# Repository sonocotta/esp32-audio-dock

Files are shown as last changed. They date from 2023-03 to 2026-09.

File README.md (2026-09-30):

# ESP32 Audio Docks and Louder ESP

<a class="logo" href="https://www.elecrow.com/store/Sonocotta" title="I sell at Elecrow">elecrow logo</a>



ESP32 Audio Docks is a range of development boards (earlier docks) that allow you to develop Audio solutions based on ESP32 chips. These were created to make Audio development entry as easy and inexpensive as possible. 

<details>
  <summary>First generation docks</summary>
  


</details>

| **HiFi-ESP32** | **HiFi-ESP32-Plus** |
|---|---|
|  |  |
| **Loud-ESP32** | **Loud-ESP32-Plus**
|   | 
| **Louder-ESP32** | **Louder-ESP32-Plus** |
|  | 
| **Louder-ESP32-mini** | **Louder-ESP32-Pro** |
|  |  |
| **Amped-ESP32** | **Amped-ESP32-Plus** | 
|  | 

⚠️ _Looking for Esparagus boards? Check out sister repository: [Esapragus Media Center](https://github.com/sonocotta/esparagus-media-center/)_

## Table of Contents

- [ESP32 Audio Docks and Louder ESP](#esp32-audio-docks-and-louder-esp)
  - [Table of Contents](#table-of-contents)
  - [Motivation](#motivation)
  - [HiFi-ESP32 and Hifi-ESP32-Plus](#hifi-esp32-and-hifi-esp32-plus)
  - [Loud-ESP32 and Loud-ESP32-Plus](#loud-esp32-and-loud-esp32-plus)
  - [Louder-ESP32 and Louder-ESP32 Plus](#louder-esp32-and-louder-esp32-plus)
  - [Louder-ESP32 Mini](#louder-esp32-mini)
  - [Louder-ESP32 Pro](#louder-esp32-pro)
    - [Recommended power adapter](#recommended-power-adapter)
  - [Amped-ESP32 and Amped-ESP32-Plus](#amped-esp32-and-amped-esp32-plus)
    - [TPA3110 vs TAP3118 designs](#tpa3110-vs-tap3118-designs)
  - [Features](#features)
    - [Onboard PSRAM](#onboard-psram)
  - [Which chip: ESP32 or ESP32-S3?](#which-chip-esp32-or-esp32-s3)
  - [Boards Pinout](#boards-pinout)
    - [Legacy boards](#legacy-boards)
    - [HiFi-ESP32 and Amped-ESP32](#hifi-esp32-and-amped-esp32)
    - [Amped-ESP32-Plus](#amped-esp32-plus)
    - [HiFi-ESP32 Plus and Amped-ESP32 Plus](#hifi-esp32-plus-and-amped-esp32-plus)
    - [Loud-ESP32](#loud-esp32)
    - [Loud-ESP32-Plus](#loud-esp32-plus)
    - [Louder-ESP32 and Louder-ESP32-Plus](#louder-esp32-and-louder-esp32-plus-1)
    - [Ethernet (all boards)](#ethernet-all-boards)
    - [Optional peripheral (all boards)](#optional-peripheral-all-boards)
    - [Fan (optional on Louder-ESP32-Pro boards)](#fan-optional-on-louder-esp32-pro-boards)
    - [Mic header](#mic-header)
    - [TFT and Fan header (Louder-ESP32 Pro boards)](#tft-and-fan-header-louder-esp32-pro-boards)
  - [Which software is right for me](#which-software-is-right-for-me)
  - [Software samples](#software-samples)
    - [Platformio IDE](#platformio-ide)
    - [Arduino IDE](#arduino-ide)
  - [Using ESP32 Audio Boards with the Home Assistant](#using-esp32-audio-boards-with-the-home-assistant)
    - [Configuring Home Assistant](#configuring-home-assistant)
    - [Home Assistant: LMS or Airplay](#home-assistant-lms-or-airplay)
      - [Native HA integration](#native-ha-integration)
      - [Integrate into Music Assistant directly](#integrate-into-music-assistant-directly)
    - [Home Assistant: ESPHome way](#home-assistant-esphome-way)
      - [Install steps](#install-steps)
    - [PCM5122 DSP capabilities (HiFi-ESP32 Plus \& Amped-ESP32 Plus)](#pcm5122-dsp-capabilities-hifi-esp32-plus--amped-esp32-plus)
    - [Home Assistant: Snapcast](#home-assistant-snapcast)
  - [Squeezelite-ESP32](#squeezelite-esp32)
    - [How to flash and configure](#how-to-flash-and-configure)
    - [Ethernet configuration](#ethernet-configuration)
    - [Squeezelite-esp32 reboots and connection drops](#squeezelite-esp32-reboots-and-connection-drops)
  - [AirPlay 1 & 2](#airplay-1--2)
    - [TAS58xx DSP: full parametric EQ and crossover control](#tas58xx-dsp-full-parametric-eq-and-crossover-control)
    - [How to Get Started](#how-to-get-started)
  - [Other smart home options](#other-smart-home-options)
    - [Building Tasmota with I2S support](#building-tasmota-with-i2s-support)
    - [Connect to the MQTT broker](#connect-to-the-mqtt-broker)
    - [Connect Louder-ESP32 to the MQTT broker](#connect-louder-esp32-to-the-mqtt-broker)
    - [Testing audio playback with MQTT controls](#testing-audio-playback-with-mqtt-controls)
  - [Standalone Snapclient](#standalone-snapclient)
    - [Snapclient benefits](#snapclient-benefits)
  - [Flashing ESP32-S3](#flashing-esp32-s3)
  - [Hardware](#hardware)
    - [ESP Audio Solo](#esp-audio-solo)
    - [ESP Audio Duo](#esp-audio-duo)
    - [HiFi-ESP](#hifi-esp)
    - [Louder ESP](#louder-esp)
    - [HiFi-ESP32](#hifi-esp32)
    - [Loud-ESP32](#loud-esp32-1)
    - [Amped-ESP32](#amped-esp32)
    - [Amped-ESP32 with TPA3118/TPA3128 amp](#amped-esp32-with-tpa3118tpa3128-amp)
    - [Louder-ESP32](#louder-esp32)
    - [Optional SPI Ethernet module](#optional-spi-ethernet-module)
    - [BTL and PBTL mode (Louder and Amped boards)](#btl-and-pbtl-mode-louder-and-amped-boards)
      - [Power figures (comparison of BTL and PBTL modes)](#power-figures-comparison-of-btl-and-pbtl-modes)
      - [Louder-ESP32 and Louder-ESP32-Plus (recent revisions)](#louder-esp32-and-louder-esp32-plus-recent-revisions)
      - [Amped TPA3110 Amp](#amped-tpa3110-amp)
      - [Amped TPA3128 Amp](#amped-tpa3128-amp)
      - [Louder TAS5805M DAC](#louder-tas5805m-dac)
    - [TAS5805M DSP capabilities](#tas5805m-dsp-capabilities)
    - [Louder-ESP32 and Amped-ESP32 power considerations](#louder-esp32-and-amped-esp32-power-considerations)
      - [Connector specs](#connector-specs)
      - [Recommended models](#recommended-models)
      - [Efficiency](#efficiency)
    - [Speakers selection](#speakers-selection)
    - [OLED screen](#oled-screen)
      - [OLED models](#oled-models)
      - [Software side](#software-side)
    - [TFT screen](#tft-screen)
    - [Case](#case)
    - [Parametric OpenSCAD desktop case](#parametric-openscad-desktop-case)
    - [Louder-ESP32 Pro case](#louder-esp32-pro-case)
    - [Louder-ESP32 Mini shell](#louder-esp32-mini-shell)
    - [Louder-ESP32 Mini Speakers Compatibility](#louder-esp32-mini-speakers-compatibility)
    - [Louder-ESP32 Mini USB-PD note](#louder-esp32-mini-usb-pd-note)
  - [Community projects](#community-projects)
  - [Where to buy](#where-to-buy)
  - [Errata](#errata)

## Motivation

I spent the last few years developing different solutions based on ESP devices. It all started with ESP8266, where CPU power is not really sufficient to do real-time decoding, so you're limited to a rather simple ding-dong business. Then ESP32 came, bringing two much more capable cores, so you have a powerhouse to handle communication and decoding at the same time. Perhaps most importantly, it also came with SPIRAM, so you can do decent buffering (essential for streamed content). Now, new ESP32 C-Series and S-Series chips are entering the market, and their potential is mostly unrealized as of today.

I created those docks and subsequently development boards to be able to quickly prototype for the whole range of ESP8266 and ESP32 chips, starting with the simplest finger-sized toys and going all the way up to full-sized speakers.

## HiFi-ESP32 and Hifi-ESP32-Plus

The **HiFi-ESP32** is a first-in-line product that uses the legendary PCM5100 series DAC with supreme audio quality. It exposes line-level output that you can plug into a stereo amplifier. Analog power comes through an Ultra-low-noise LDO, making sure no interference from the MCU comes through to your speakers. Spend as much as you need on the external amp to deliver the sound you like (personally, I prefer late 80's audio gear).

| **HiFi-ESP32** | **HiFi-ESP32-Plus** |
|---|---|
|  | 

The **HiFi-ESP32 Plus** represents the next evolution of the board, featuring the advanced PCM5122 DAC with built-in DSP capabilities. This board maintains the same audio quality as the original HiFi-ESP32 while adding powerful digital signal processing features, including parametric EQ (6 BQs per channel), DRC, and crossover functionality (with output to downstream DAC). The PCM5122's flexible DSP engine can be configured for various audio enhancement scenarios, making it ideal for projects requiring sound tuning (why would you not)

**Key Features:**

- [PCM5122](https://www.ti.com/lit/ds/symlink/pcm5122.pdf) DAC with integrated DSP
- Parametric EQ and crossover capabilities (for cascading DACs)
- Digital volume control (avoids loss of resolution compared to software volume)
- Advanced audio processing features (DRC)
- Same form factor and connectivity as HiFi-ESP32

## Loud-ESP32 and Loud-ESP32-Plus

The **Loud-ESP32** uses a dual MAX98357 HiFi DAC with a built-in highly efficient D-class amp to deliver 3 to 5W of music power directly to your speakers. It is not too loud, but also very simple to use and fun to play with. When DAC is not in use, it goes into shutdown mode, making sure no hissing will keep you up at night. It powers from a standard USB-C power source, like a phone charger, etc.

| **Loud-ESP32** | **Loud-ESP32-Plus** |
|---|---|
|  | 

The **Loud-ESP32-Plus** model hires a much more powerful [Infineon MA12070P](https://www.infineon.com/part/MA12070P) DAC with up to 60W per channel. Due to the D-class amp, they are highly efficient yet high-quality audio streamers. It lacks DSP features, but has the most raw horsepower across the line. It is in beta testing, and I'm still trying to fix minor issues with the DAC driver.

## Louder-ESP32 and Louder-ESP32 Plus

The **Louder-ESP32** is a top-of-the-range model that uses a modern, highly capable TAS5805M DAC and is aimed at being paired with medium-to-large speaker systems. With 25W per channel stereo output, it packs a punch and can easily enliven living quarters or dorm rooms. It is highly efficient, but much more demanding for power when cranked; therefore, it also uses an external power adapter using a standard  jack. This DAC has a built-in DSP, so you can have a lot of fun with complex EQ, soft-clipping, DRC compression, and AGL tools, among other things.

| **Louder-ESP32** | **Louder-ESP32-Plus** |
|---|---|
|  | 

The **Louder-ESP32-Plus** upgrades the DAC to the TAS5825M model, which is more efficient (and therefore more powerful) and more capable. It introduces advanced DSP features that are not available on the base model, as it has a much more powerful DSP processor.

- TAS5825M DAC with integrated DSP
- Digital volume control (avoids loss of resolution compared to software volume)
- Gain digital control
- Parametric EQ (15xBQ), 128-tap FIR, 3-band DRC, AGL
- Advanced DSP: Smart Excursion, Smart Thermal, Smart Bass, SmartEQ

## Louder-ESP32 Mini

**Louder-ESP32-mini** is a compact and stripped-down version of the Louder-ESP32, which would replace the standard speaker terminal on your old speakers, turning them into a Hi-Fi audio solution for your smart home.

It comes in two sizes that are most common among off-the-shelf speakers: 42x42mm (small speakers typically) and 52x52mm (for larger models).

Louder-ESP32-mini is equipped with a high-quality TAS5805M DAC with powerful DSP features, allowing audio tuning to turn small speakers into high-quality audio streamers. Onboard ESP32-S3 with 8MB PSRAM is there to ensure enough horsepower for solid streaming capabilities.

It is designed to be as affordable as it can be, so more speakers can avoid landfills and be an integral part of smart homes instead. It uses minimal (if any) extra peripherals, and it requires no soldering to operate. The part choice was carefully done to make it production-friendly and affordable for everyone

| Front | Back |
|---|---|
|  | 

## Louder-ESP32 Pro

On the other side of the scale, Louder-ESP32-Pro is a feature-packed version of the Louder-ESP32-Plus, which hosts most of the optional extras as standard, adds support for color TFT screens, and, perhaps most importantly, adds an industrial-grade heat release solution for reliable heavy-duty operation.

It comes in Raspberry Pi 5 shape with the most important component placed to follow the original heat release pattern. This allows the use of Raspberry Pi aluminum radiators, including those with soft-controlled fan connectors, that can be driven through Louder-ESP32-Pro software when operating in hot conditions.

Louder-ESP32-Pro is equipped with a high-quality TAS5825M DAC with powerful DSP features, allowing audio tuning to turn your speakers into high-quality audio streamers, big or small likewise. Onboard ESP32-S3 with 8MB PSRAM is there to ensure enough horsepower for solid streaming capabilities.



### Recommended power adapter

Louder-ESP32-Pro is designed to be powered from a USB-C power source, so powering it is as easy as plugging in a standard laptop power charger. It can accept a wide range of voltages, but for maximum performance, a 20V 3.25A 65W power adapter is recommended. This will ensure that the board can deliver its full audio output capabilities without power limitations.

|  Model | Image |
|---|---|
| [20V 3.25A 65W AC Laptop Power adapter Charger](https://pl.aliexpress.com/item/1005007070762655.html) | 

It will also work from Quick-charge power adapters (9V, 12V) that support USB-PD protocol, and even bare USB-C power sources, but the maximum output will be limited to the power adapter's capabilities.

## Amped-ESP32 and Amped-ESP32-Plus

The PCM5100 HiFi DAC is combined with a highly efficient TPA31-series D-class amplifier. It brings all the best from the HiFi model and adds an onboard amp to form a complete solution that can be paired with speakers. Compared to the Louder models, it has similar power capabilities, but it is much simpler to use since it only needs a valid I2S signal to operate, so a simple book example code will do it. It adds line-out, so you have a chance to switch betwwen built-in amp and external, if you need to. 

| **Amped-ESP32** | **Amped-ESP32-Plus** |
|---|---|
|  | 

Building upon the success of the Amped-ESP32, the **Amped-ESP32 Plus** combines the powerful PCM5122 DAC with the same TPA31-series amplifier. This board offers the same DSP capabilities as the HiFi-ESP32-Plus while providing built-in amplification for direct speaker connection. The PCM5122's DSP features will enable advanced audio processing, including speaker correction, room EQ, and other enhancements.

**Features:**

- [PCM5122](https://www.ti.com/lit/ds/symlink/pcm5122.pdf) DAC with integrated DSP + TPA3110/TPA3118 D-class amplifier
- Digital EQ and dynamic range processing
- Same power output as Amped-ESP32 with enhanced audio quality

### TPA3110 vs TAP3118 designs

Recently, all Amped boards were migrated to use the new [TPA3118](https://www.ti.com/product/TPA3118D2) amp. Benefits that the new TPA3118 amp brings:

- It is more efficient (about half the heat with the same output power, compared to TPA3110), so the board can sustain higher power for longer
- It has a true MUTE pin that can be connected to the GPIO and shut down the output driver when no audio is playing
- It can be powered from a 5V source, so if you're not looking for maximum power, you can use a USB-C power adapter alone
- Being a newer design, it has better audio quality. I can't hear it, but people say it sounds better

## Features

<details>
  <summary>First generation docks</summary>

| ESP Audio Solo | ESP Audio Duo | Hifi ESP | Louder ESP |
|---|---|---|---|
|  |  |  |  |
| ESP8266, ESP32C3, ESP32S2 Mini modules | ESP32 Mini Module | ESP32 Mini Module | ESP32 Mini Module |
| Single I2S DAC ([MAX98357](https://www.analog.com/en/products/max98357a.html)) with built in D-Class amp | Dual I2S DAC ([MAX98357](https://www.analog.com/en/products/max98357a.html)) with built in D-Class amp | [PCM5100A](https://www.ti.com/product/PCM5100A) 32bit Stereo DAC  -100 dB typical noise level | Stereo I2S DAC ([TAS5805M](https://www.ti.com/product/TAS5805M)) with built in D-Class amp |
| 3W | 2x 3W | Non-amplified stereo output | 2x 32W (4Ω, 1% THD+N) |
| 1.5W | 2x 1.5W | Non-amplified stereo output | 2x 22W (8Ω, 1% THD+N) |
|  | 8MB PSRAM (4MB usable) | 8MB PSRAM (4MB usable) | 8MB PSRAM (4MB usable) |
| WiFi (ESP8266, ESP32S2)  WiFi + BT5.0 (ESP32C3) | WiFi + BT4.2 + BLE | WiFi + BT4.2 + BLE | WiFi + BT4.2 + BLE  Ethernet |

</details>

|  | HiFi-ESP32 | HiFi-ESP32 Plus | Loud-ESP32 | Loud-ESP32-Plus | Louder-ESP32 | Louder-ESP32 Mini | Louder-ESP32 Plus | Louder-ESP32 Pro | Amped-ESP32 | Amped-ESP32 Plus |
|---|---|---|---|---|---|---|---|---|---|---|
| Image (ESP32) |  |  |  |  |  | n/a |  | n/a |  |  |
| MCU | ESP32-WROVER-N8R8 | ESP32-WROVER-N8R8 | ESP32-WROVER-N8R8 | ESP32-WROVER-N8R8 | ESP32-WROVER-N8R8 | n/a | ESP32-WROVER-N8R8 | n/a | ESP32-WROVER-N8R8 | ESP32-WROVER-N8R8 |
| Image (ESP32-S3) |  |  |  |  |  |  |  |  |   |  |
| MCU (S3) | ESP32-S3-WROOM-N8R8 | ESP32-S3-WROOM-N8R8 | ESP32-S3-WROOM-N8R8 | ESP32-S3-WROOM-N8R8 | ESP32-S3-WROOM-N8R8 | ESP32-S3-WROOM-N8R8 | ESP32-S3-WROOM-N8R8 | ESP32-S3-WROOM-N8R8 | ESP32-S3-WROOM-N8R8 | ESP32-S3-WROOM-N8R8 |
| DAC | [PCM5100A](https://www.ti.com/product/PCM5100A) 32bit Stereo DAC (-100 dB typical noise level) | [PCM5122](https://www.ti.com/product/PCM5122) 32bit Stereo DAC with integrated DSP (-112 dB typical noise level) | Dual I2S DAC ([MAX98357](https://www.analog.com/en/products/max98357a.html)) with built in D-Class amp | [Infineon MA12070P](https://www.infineon.com/part/MA12070P)<br> with built-in D-Class amp | Stereo I2S DAC ([TAS5805M](https://www.ti.com/product/TAS5805M)) with built in D-Class amplifier and powerful DSP | Stereo I2S DAC (<br>[TAS5805M](https://www.ti.com/product/TAS5805M)<br>) with built in D-Class amplifier and powerful DSP | Stereo I2S DAC (<br>[TAS5825M](https://www.ti.com/product/TAS5825M)<br>) with built in D-Class amplifier and powerful DSP | Stereo I2S DAC (<br>[TAS5825M](https://www.ti.com/product/TAS5825M)<br>) with built in D-Class amplifier and powerful DSP | [PCM5100A](https://www.ti.com/product/PCM5100A) 32bit Stereo DAC working with <br> [TPA3110D2](https://www.ti.com/product/TPA3110D2) D-Class amp <br> [TPA3128D2](https://www.ti.com/product/TPA3128D2) amp starting from Rev H | [PCM5122](https://www.ti.com/product/PCM5122) 32bit Stereo DAC with DSP + [TPA3110D2](https://www.ti.com/product/TPA3110D2) or [TPA3118D2](https://www.ti.com/product/TPA3118D2) amp |
| Line-out (possibility to connect external amplifier) | ✅ | ✅ | ❌ | ❌ | ❌ | ❌ | ❌ | ❌ | ✅ | ✅ |
| Output (4Ω, 1% THD) | ❌ | ❌ | 2x 5W | 2x 60W | 2x 32W,<br>1x 45W (bridged) | 1x 5W | 2x 45W,<br>1x 53W (bridged) | 2x 45W,<br>1x 53W (bridged) | (TPA3110)<br>2x 25W<br>1x 40W (bridged)<br>(TPA3128)<br>2x 25W<br>1x 60W (bridged) | (TPA3110)<br>2x 25W<br>1x 40W (bridged)<br>(TPA3118)<br>2x 25W<br>1x 60W (bridged) |
| Output (8Ω, 1% THD) | ❌ | ❌ | 2x 3W | 2x 35W | 2x 22W | 1x 3W | 2x 30W | 2x 30W | 2x 25W | 2x 25W |
| Flash | 8MB | 8MB | 8MB | 8MB | 8MB | 8MB | 8MB | 8MB | 8MB | 8MB |
| PSRAM | 8MB | 8MB | 8MB | 8MB | 8MB | 8MB | 8MB | 8MB | 8MB | 8MB |
| Power | 5V over USB-C | 5V over USB-C | 5V (up to 2.5A) from USB-C | 5..26V from external PSU | 5..26V from external PSU | 5V (up to 2A) from USB-C | 5..26V from external PSU | USB-PD enabled power adapter (up to 65W) | (TPA3110) 9..26V <br>(TPA3128) 5..26V<br>from external PSU | (TPA3110) 9..26V <br>(TPA3118) 5..26V<br>from external PSU |
| Connectivity | WiFi + BT4.2 (except S3) + BLE <br> Ethernet (optional module) | WiFi + BT4.2 (except S3) + BLE <br> Ethernet (optional module) | WiFi + BT4.2 (except S3) + BLE <br> Ethernet (optional module) | WiFi + BT4.2 (except S3) + BLE <br> Ethernet (optional module) | WiFi + BT4.2 (except S3) + BLE <br> Ethernet (optional module) | WiFi + BLE | WiFi + BT4.2 (except S3) + BLE <br> Ethernet (optional module) | WiFi + BLE + Ethernet | WiFi + BT4.2 (except S3) + BLE <br> Ethernet (optional module) | WiFi + BT4.2 (except S3) + BLE <br> Ethernet (optional module) |
| Built-in DSP (Digital Signal Processor) | ❌ | Basic (6-band EQ, DRC) | ❌ | ❌ | Advanced (15-band EQ, DRC, AGL, FIR, etc.) | Advanced (15-band EQ, DRC, AGL, FIR, etc.) | Advanced+ (15-band EQ, DRC, AGL, FIR, Smart features.) | Advanced+ (15-band EQ, DRC, AGL, FIR, Smart features.) | ❌ | Basic (6-band EQ, DRC) |
| Built-in mic (voice assist) | optional | optional | optional | optional | optional | ❌ | optional | ✅ | optional | optional |
| Built-in IR reader | ✅ | ✅ | ✅ | ✅ | ✅ | ❌ | ✅ | ✅ | ✅ | ✅ |
| **Software support** |  |  |  |  |  |  |  |  |  |  |
| [Squeezelite-ESP32](https://github.com/sle118/squeezelite-esp32)** | ✅ | ✅ | ✅ | ✅ | ✅ | ✅ | ✅ | ✅ | ✅ | ✅ |
| [Snapclient](https://github.com/CarlosDerSeher/snapclient)*** | ✅ | ✅ | ✅ | ✅ | ✅ | ✅ | ✅ | ✅ | ✅ | ✅ |
| [ESPHome](https://esphome.io/) (Media player) | ✅ | ✅ | ✅ | ✅ | ✅ | ✅ | ✅ | ✅ | ✅ | ✅ |
| [ESPHome](https://esphome.io/) (Sendspin player)**** | ✅ | ✅ | ✅ | ✅ | ✅ | ✅ | ✅ | ✅ | ✅ | ✅ |
| [ESPHome](https://esphome.io/) (Snapclient player)***** | ✅ | ✅ | ✅ | ✅ | ✅ | ✅ | ✅ | ✅ | ✅ | ✅ |
| [AirPlay 1 & 2](https://github.com/rbouteiller/airplay-esp32)****** | ✅ | 🔜 | ✅ | ❌ | ✅ | 🔜 | ✅ | 🔜 | ✅ | 🔜 |

** Squeezelite-ESP32 support for the ESP32-S3 is an experimental feature and is not fully stable; for styable operation, 'classic' ESP32 is recommended. Please refer to the [original repo](https://github.com/sle118/squeezelite-esp32) for up-to-date support information

*** Snapclient support for the ESP32-S3 is in beta and not fully stable as well. For best results, 'classic' ESP32 is recommended.

**** [Sendspin](https://www.sendspin-audio.com/) player is a beta feature and in active development; currently, ESP32-S3 works considerably better than classic ESP32, but it is still in development, and the situation will improve over time.

***** [Snapclient component](https://github.com/c-MM/esphome-snapclient/) in ESPHome is a beta feature, developed by the community. Please check the current development status for up-to-date support information.

****** See [AirPlay 1 & 2](#airplay-1--2) below. 🔜 means the DAC is planned but not yet supported: HiFi-ESP32-Plus and Amped-ESP32-Plus will get basic playback on their PCM5122 (no DSP exposed), and Louder-ESP32-mini/Pro will get the same TAS5805M/TAS5825M support (including full DSP) as their siblings once a build matches their exact pinout. Loud-ESP32-Plus (MA12070P) is not currently planned.

### Onboard PSRAM

Audio streaming requires proper buffering to work; even with the ESP32's 500K of RAM, it is a challenging task. For that reason, most of the projects will require WROVER modules that have onboard PSRAM chips.  All ESP32 Audio boards have an 8MB PSRAM chip onboard, connected via a high-speed interface. Any code using PSRAM just works out of the box.

## Which chip: ESP32 or ESP32-S3?

Most boards in this line are sold with either the 'classic' ESP32 or the newer ESP32-S3. They are not interchangeable for every use case, and picking the wrong one is the single most common support question — here's the short version:

- **ESP32-S3 is the newer, more capable chip** — more RAM headroom, a faster CPU, and native USB — but it has **no Bluetooth Classic radio**, so Bluetooth A2DP only works on the original ESP32.
- **Squeezelite-ESP32 and standalone Snapclient**: pick the **classic ESP32**. Neither firmware is fine-tuned for the S3 yet, and current S3 support is noticeably laggier.
- **ESPHome / Home Assistant media player**: pick **ESP32-S3**. The new Sendspin renderer runs much better on the S3's extra headroom.
- **Voice assistant (wake word) in Home Assistant**: **ESP32-S3 is mandatory** — the classic ESP32 doesn't have the RAM/CPU headroom to run it.
- **AirPlay 1 & 2** ([rbouteiller/airplay-esp32](https://github.com/rbouteiller/airplay-esp32)): both chips are fully supported on the boards it currently targets; ESP32-S3 is preferred for its extra performance headroom.

| Your use case | Pick |
|---|---|
| Bluetooth A2DP from a phone/laptop | **ESP32** |
| Squeezelite-ESP32 or standalone Snapclient | **ESP32** |
| ESPHome media player / Sendspin | **ESP32-S3** |
| Home Assistant voice assistant | **ESP32-S3** |
| AirPlay 1 & 2 | Either — **ESP32-S3** for more headroom |

If none of that applies to you and you just want the safe default, pick **ESP32-S3** — it's the newer chip. Only choose classic ESP32 if you specifically need Bluetooth A2DP, or plan to run Squeezelite-ESP32/Snapclient today.

Note that **Louder-ESP32-mini** and **Louder-ESP32-Pro** are ESP32-S3-only designs — there is no chip choice to make on those two.

## Boards Pinout

### Legacy boards

<details>
  <summary>First generation docks</summary>

**ESP Audio Solo**

| | I2S CLK | I2S DATA | I2S WS |
|---|---|---|---|
| ESP8266 | 15 | 3 | 2 |
| ESP32-C3 | 5 | 20 | 6 |
| ESP32-S2 | 12 | 37 | 16 |

**ESP Audio Duo**

| | I2S CLK | I2S DATA | I2S WS | PSRAM CE | PSRAM CLK |
|---|---|---|---|---|---|
| ESP32 | 26 | 22 | 25 | 16 | 17 |

**HiFi-ESP**

| | I2S CLK | I2S DATA | I2S WS | PSRAM CE | PSRAM CLK |
|---|---|---|---|---|---|
| ESP32 | 26 | 22 | 25 | 16 | 17 |

**Louder ESP**

| | I2S CLK | I2S DATA | I2S WS | PSRAM CE | PSRAM CLK | TAS5805 SDA | TAS5805 SCL | TAS5805 PWDN | TAS5805 FAULT |
|---|---|---|---|---|---|---|---|---|---|
| ESP32 | 26 | 22 | 25 | 16 | 17 | 21 | 27 | 33 | 34 |
| ESP32-S3 | 14 | 16 | 15 | - | - | 8 | 9 | 17 | 18 |

</details>

### HiFi-ESP32 and Amped-ESP32

| | I2S CLK | I2S DATA | I2S WS | PSRAM RESERVED | AMP EN | 
|---|---|---|---|---|---|
| ESP32 | 26 | 22 | 25 | 16, 17 | 13 (rev H+)
| ESP32-S3 | 14 | 16 | 15 | 35, 36, 37 | 17 (rev J+) 

### Amped-ESP32-Plus

| | I2C CLK | I2C DATA | PSRAM RESERVED | AMP EN | 
|---|---|---|---|---|
| ESP32 | 27 | 21 | 16, 17 | 13 | 
| ESP32-S3 | 08 | 18 | 35, 36, 37 | 17 | 

### HiFi-ESP32 Plus and Amped-ESP32 Plus

| | I2S CLK | I2S DATA | I2S WS | I2S MCLK (optional) | PSRAM RESERVED | DAC/AMP EN | I2C SDA | I2C CLK. |
|---|---|---|---|---|---|---|---|---|
| ESP32 (J) | 26 | 22 | 25 | 0 | 16, 17 | 13 |  27 | 21 |
| ESP32-S3 (H)  | 14 | 16 | 15 | 0 | 35, 36, 37 | 4 |  41 | 42 |
| ESP32 (J1+) | 26 | 22 | 25 | 0 | 16, 17 | 13 |  21 | 27 |
| ESP32-S3 (H1+)| 14 | 16 | 15 | 0 | 35, 36, 37 | 4 |  42 | 41 |

### Loud-ESP32

| | I2S CLK | I2S DATA | I2S WS | DAC EN | PSRAM RESERVED | 
|---|---|---|---|---|---|
| ESP32 | 26 | 22 | 25 | 13 | 16, 17 |
| ESP32-S3 | 14 | 16 | 15 | 8 | 35, 36, 37 | 

### Loud-ESP32-Plus

| | I2S CLK | I2S DATA | I2S WS | DAC ENABLE| DAC MUTE | SDA  |  SCL | PSRAM RESERVED | 
|---|---|---|---|---|---|---|---|---|
| ESP32 | 26 | 22 | 25 | 13 | 33 | 21 | 27 | 16, 17 |
| ESP32-S3 | 14 | 16 | 15 | 17 | 18 | 9 | 8 | 35, 36, 37 | 

### Louder-ESP32 and Louder-ESP32-Plus

| | I2S CLK | I2S DATA | I2S WS | PSRAM RESERVED |  I2C SDA | I2C SCL  | TAS58XX PWDN | TAS58XX FAULT |
|---|---|---|---|---|---|---|---|---|
| ESP32 | 26 | 22 | 25 | 16, 1 | 21 | 27 | 33 | 34 |
| ESP32-S3 | 14 | 16 | 15 | 35, 36, 37 | 8 | 9 | 17 | 18 |

### Ethernet (all boards)

| | SPI CLK | SPI MOSI | SPI MISO | SPI CS | SPI HOST/SPEED | ETH INT | ETH RST |  
|---|---|---|---|---|---|---|---|
| ESP32 | 18 | 23 | 19 | 05 | 2/20MHz | 35 | 14 | 
| ESP32-S3 | 12 | 11 | 13 | 10 | SPI2/20MHz | 6 | 5 |  

### Optional peripheral (all boards)

| |  IR IN  | RGB OUT  | OLED SPI HOST/SPEED | OLED SPI CLK | OLED SPI MOSI | OLED SPI MISO | OLED SPI CS | OLED SPI DC | OLED RST | 
|---|---|---|---|---|---|---|---|---|---|
| ESP32 | 39 | 12 | 2/20MHz | 18 | 23 | 19 | 15 | 4 | 32 |
| ESP32-S3 | 7 | 9 | SPI2/20MHz | 12 | 11 | 13 | 39 | (37) | 38 |
| ESP32-S3 (Rev J3+) | 7 | 9 | SPI2/20MHz | 12 | 11 | 13 | 47 | 38 | 48 |
| HIFI-ESP32-S3 (Rev G2+)  | 7 | 9 | SPI2/20MHz | 12 | 11 | 13 | 39 | 40 | 38 |

### Fan (optional on Louder-ESP32-Pro boards)

Louder-ESP32-Pro have a 4-pin fan connector, with a size and pinout borrowed from the Raspberry Pi 5 specification. It can be used to connect a 5V fan, which can be controlled by the onboard ESP32-S3. The fan speed can be set in software, and the actual speed can be read back from the fan's tachometer output.

| | IN (RPM read) | OUT (speed set) 
|---|---|---|
| ESP32-S3 | 1 | 2 | 

### Mic header

Both versions of the Louder-ESP32 boards (ESP32 Rev. H6+, ESP32-S3 Rev. K0+) and HiFi-ESP32 (ESP32 Rev. F3+, ESP32-S3 Rev. G2+) have an unsoldered header for external I2S mic: left and right channels. ESP32 uses the same I2S bus with an extra DATA IN pin due to the pin limitations, while S3 uses a dedicated I2S bus. It can be used for wake word functionality in the Home Assistant or for custom firmware.

| | I2S CLK | I2S WS | I2S DATA |
|---|---|---|---|
| ESP32 | 26 | 25 | 13 |
| ESP32-S3 | 41 | 40 | 39 |
| HIFI-ESP32-S3 (Rev G2+) | 17 | 18 | 8 |

The mic model that I used for testing and validation is the INMP441 MEMS microphone; the pinout is created for this model. Other models might be available.


### TFT and Fan header (Louder-ESP32 Pro boards)

| |  FAN PWM| FAN SPD  | TFT SPI HOST/SPEED | TFT SPI CLK | TFT SPI MOSI | TFT SPI MISO | TFT SPI CS | TFT SPI DC | TFT RST | TFT BACKLIGHT |
|---|---|---|---|---|---|---|---|---|---|---|
| ESP32-S3 | 2 | 1 | SPI2/20MHz | 12 | 11 | 13 | 47 | 38 | 48 | 42 | 

## Which software is right for me



## Software samples

In the [software](/firmware) section, two firmware examples are provided.

- [esp32-i2s-bare](/firmware/esp32-i2s-bare/) is base I2S implementation based on ESP-IDF implementation directly.
- [esp32-i2s-esp8266audio](/firmware/esp32-i2s-esp8266audio/) is based on excellent [ESP8266Audio](https://github.com/earlephilhower/ESP8266Audio) library (it works with the whole ESP range, don't get fooled by the name), providing minimum code implementation. 
- [esp32-i2s-web-radio](/firmware/esp32-i2s-web-radio/) is based on the [same library](https://github.com/earlephilhower/ESP8266Audio), providing minimum web-readio stream player. It expects a playlist as input in the 'data' folder.
- [Squeezelite-ESP32](https://github.com/sle118/squeezelite-esp32) - see more details [below](#Squeezelite-ESP32)

### Platformio IDE
 
All samples are provided as [Plarformio IDE](https://platformio.org/platformio-ide) projects. After installing it, open the sample project. Select the proper environment based on your dock. Run the `Build` and `Upload` commands to install necessary tools and libraries, and build and upload the project to the board. Communication and proper upload method selection will be handled by IDE automatically. 

### Arduino IDE

Follow the [ESP8266Audio](https://github.com/earlephilhower/ESP8266Audio) library guide. Default settings will work out of the box with ESP8266 and ESP32 boards. For the ESP32C3 and ESP32S2 board, please adjust the pinout according to the above section

## Using ESP32 Audio Boards with the Home Assistant

There are several ways ESP32 Audio Boards can be integrated into the Home Assistant setup. Each of them gives a unique feature, losing some other in return. As usual, there is no perfect solution for everyone, but perhaps there is one for you. Below is the summary table of the methods known to me and tested by me.

| Integration type | Tested  | Description | Pros | Cons |
|---|---|---|---|---|
| [LMS/Airplay](https://github.com/sle118/squeezelite-esp32) | Yes | Connect to Music Assistant as external protocol device. Can play your media library and internet radio | Still can use squeezelite, i.e. use Spotify Connect and Apple Airplay when HA is not using the device | No native integration into HA, only works with Music Assistant |
| [ESPHome way](https://www.espthings.io/index.php/2024/04/07/louder-esp32-a-hi-fi-class-d-audio-amplifier-running-esphome/) | Yes | Connect as HA media device. Can be used with any HA integration, including Music Assistant, Text-to-Speech announcements, alarms, etc | More integrations with HA, more flexibility in use case | No longer works as Spotify, Airplay, etc. |
| [Snapcast way](https://github.com/CarlosDerSeher/snapclient/issues/70#issuecomment-2034700037) | Yes | Connect to Music Assistant as snapcast protocol device. Can play your media library and internet radio. | Perfect for multiroom sync (Sonos-like, perhaps even better). Can be used with other Snapcast servers around the house | No longer works with Spotify, AirPlay, etc. No native integration into HA only works with Music Assistant |

Below are specific steps that you need to follow to spin up ESP32 Audio Boards in the Home Assistant

### Configuring Home Assistant

I prefer to use HA with the Music Assistant. This way, you can integrate both your media library and internet radio and have a nice UI/UX at the same time (including mobile).

Generally, you need to have a supported HA (native) installation and follow [these steps](https://music-assistant.io/integration/installation/). I will place here a short version to have a reminder for future self

<details>
  <summary>Install instructions</summary>

| Step | Screenshot |
|---|---|
| **Add SSH Addon** <br/> <br/> Navigate to Settings > Addons > Add Addon <br/> Search for SSH and install it. <br/> Enable `Show in sidebar` switch while you there | 
| **Start SSH Addon** <br/> <br/> SSH addon won't start until you add at least one SSH public key to it. So navigate to SSH Addon Settings and add a key (or password) to the config <br/> It should be able to start now | 
| **[Install Community Store](https://hacs.xyz/docs/setup/download/)** <br/> <br/> Run this command in the Terminal session <br> <code>wget -O - https://get.hacs.xyz &#124; bash -</code> <br/> You need to restart your HA after that | 
| **[Add HACS](https://hacs.xyz/docs/configuration/basic)** <br/> <br/> Navigate to Settings > Devices as Services > Integrations > Add Integration, search for HACS, and add it to the HA </br> You'll need to authorize your extension to your GitHub account | 
| **[Install Music Assistant via HACS](https://music-assistant.io/integration/installation/)** <br/> <br/> From the HACS menu, search for Music Assistant and press the Download button <br/> You need to restart HA again <br/> In the Settings > Addons, you should be able to see MA and enable sidebar navigation for it. | 
| **Configure Music Assistant** <br/> <br/> Before you enable Integration (that will in turn add speaker devices), you need to enable MA providers <br/> Go to MA > Settings > Providers and enable both Music providers and Player providers that interest you. If you're not sure, enable all of them; you can disable them later on. | 
| **Add Music Assistant Integration** <br /> <br/> Navigate to HA Settings > Devices & services > Integrations. Click the big + ADD INTEGRATION button, look for Music Assistant, and click to add it. <br/> It should discover and add media devices based on the providers you're enabled in the previous step | 
| **Add Music Devices discovered by MA** <br/> <br/> You should be able to add and use discovered devices. More details in below sections |  

</details>
  
### Home Assistant: LMS or Airplay

[gh://sle118/squeezelite-esp32](https://github.com/sle118/squeezelite-esp32)

When you have squeezelite-esp32 installed on your ESP32 Audio Board (either stock or manually going through [steps](#squeezelite-esp32)), it will announce itself by multiple protocols in the network:

- Bluetooth
- LMS or slimproto - auto-discovered by HA
- Apple AirPlay - auto-discovered by HA
- Spotify Connect

The power of this method is that you can use all four ways outside of HA, for example, using your smartphone and Spotify app, and still have it integrated into HA at the same time.

<details>
  <summary>Install instructions</summary>
  
#### Native HA integration

Make sure your MA Slimproto provider is disabled; it will conflict with the native HA integration 

| Step | Screenshot |
|---|---|
| **Add SlimProto Integration** <br/> <br/> Navigate to HA Settings > Devices & services > Integrations. Click the big + ADD INTEGRATION button, look for  SlimProto, and install it. | 
| **Add HA MediaPlayers provider to MA** | 

#### Integrate into Music Assistant directly 

Disable SlimProto integration in the HA if you want to go the MA way. If you enabled SlimProto and AirPlay providers in the MA, you should find your device as both a Slimproto device and an AirPlay device. It is up to you which protocol to use; generally, they both work perfectly well.

</details>

### Home Assistant: ESPHome way

[Louder-ESP32 running ESPHome](https://www.espthings.io/index.php/2024/04/07/louder-esp32-a-hi-fi-class-d-audio-amplifier-running-esphome/)

All ESPHome configurations are in the [firmware/esphome/](firmware/esphome/) folder. See the **[ESPHome README](firmware/esphome/README.md)** for full details on supported hardware variants, configuration options, the package system, and build instructions.

All configs use the ESP-IDF framework (preferred for audio — lighter, faster, and more stable than Arduino). Each board directory contains up to four firmware variants:

| Variant | Files | Description |
|---|---|---|
| Standard media player | `*-idf.yaml` | Native HA media player with mixer, resampler, TTS and announcement ducking |
| Snapclient | `*-snapclient.yaml` | Snapcast multi-room client with 18-band software EQ (experimental) |
| Sendspin | `*-sendspin.yaml` | ESPHome-native multi-room playback via [Sendspin protocol](https://www.music-assistant.io/player-support/sendspin/) (experimental, 2026.2.0+) |
| Voice Assistant | `*-voice-assist.yaml` | Wake-word voice assistant with HA Voice integration (Plus boards only) |

Both ESP32 and ESP32-S3 variants are covered for each board. S3 variants carry `-s3-` in the filename.

Sendspin references:

- [Music assistant discussion](https://github.com/orgs/music-assistant/discussions/4200#discussioncomment-15345580)
- [XDA Developers post](https://www.xda-developers.com/sendspin-esphome-multi-room-audio/)
- [ESPHome PR](https://github.com/esphome/esphome/pull/12284)

#### Install steps

<details>
  <summary>Install instructions</summary>

| Step | Screenshot |
|---|---|
| **Add ESPHome Addon** <br/> <br/> Navigate to HA Settings > Addons > Add Addon <br/> Search for SSH and install it.  <br/> Enable `Show in sidebar` switch while you there | 
| **Prepare ESP32 Audio Board for ESPHome onboarding** <br/> <br/> Use [Web Flasher](https://web.esphome.io/?dashboard_wizard) to flash stock ESPHome into device | 
| **Onboard ESP32 Audio Board ESPHome device into HA** <br/> <br/> Go to the HA ESPHome page and you should be able to find a new device. You need to onboard it with the below config (feel free to change names) <br/> This will take a moment or two | 
| **Validate device in the ESPHome** | 
| **Add ESPHome Integration** <br /> <br/> Navigate to HA Settings > Devices & services > Integrations. Click the big + ADD INTEGRATION button, look for ESPHome, and click to add it. <br/> It should discover and add ESPHome media devices based on the previous step | 
| **Use your media device in the HA** | 
| **Use your media device in the MA** <br/> <br/> Add Music Assistant HA MediaPlayers provider to discover new Media device | 

</details>

The latest changes in the ESPHome (deprecation of the custom components) triggered a work to implement an external [TAS5805M DAC ESPHome component](https://github.com/mrtoy-me/esphome-tas5805m). It took some time, but this driver implements a few very important features of the TAS5805M DAC that can not only be used in the device configuration, but also in various automations and complex logic. Worth noting:

- Possibility to configure Analog Gain (depending on the power supply you have, more details [here](https://github.com/sonocotta/esp32-tas5805m-dac/#digital-volume-and-analog-gain)) | 
- Advanced digital volume configuration (set minimum, maximum, and step value)
- 
- Automatic powersave modes based on playback state
- DAC mode: 2 channel, or 1 channel bridged mode (more details [here](https://github.com/sonocotta/esp32-tas5805m-dac/#setting-and-getting-dac-mode))
- Mixer mode: MONO, STEREO, INVERTED, LEFT, RIGHT (more details [here](https://github.com/sonocotta/esp32-tas5805m-dac/#mixer-controls))
- My favorite: 15 band equalizer with [-15 dB .. +15 dB] range, which is an absolute treat to configure your speakers to your audio taste
- 
- For the first time: read and reset fault states, no need to reboot the device. Not only reports them back to HA, but also example of automatic correction is provided (slowly reduce volume on overheat)
- 

We have some plans for further development of the ESPHome driver, implementing subwoofer and satellite profiles (for 2.1 and bi-amp configs), enabling soft-clipping, and perhaps even unleashing the power of all BQ-parameters (to enable speaker-specific compensation of the DAC). Stay tuned!

### PCM5122 DSP capabilities (HiFi-ESP32 Plus & Amped-ESP32 Plus)

The PCM5122 DAC featured in the new Plus models brings advanced DSP capabilities that were previously unavailable in the PCM5100-based lineup. This powerful 32-bit DAC includes a flexible DSP engine that enables low-latency sophisticated audio processing directly on the chip, reducing CPU load and providing professional-grade audio enhancement features.

**Key DSP Features:**

- **Parametric EQ**: ^BQs per channel of parametric equalization for precise frequency response shaping
- **Dynamic Range Control (DRC)**: Automatic volume management and dynamic compression
- **Crossover Networks**: Digital crossover filters for bi-amp and multi-way speaker systems
- **Bass/Treble Enhancement**: Dedicated low and high frequency boost/cut controls
- **Volume Control**: High-resolution digital volume with soft mute functionality
- **Sample Rate Conversion**: Automatic handling of different input sample rates

**Planned Implementation:**

- Integration with ESPHome for Home Assistant control of DSP parameters
- Real-time EQ adjustment through UI
- Preset management for different listening environments
- Advanced crossover configurations for 2.1 setups

The PCM5122's DSP features will be gradually unlocked through firmware updates, starting with basic EQ and volume control, and expanding to include advanced crossover and room correction features. This positions the HiFi-ESP32 Plus and Amped-ESP32 Plus as professional-grade audio development platforms suitable for high-end audio applications.

**Development Status:**

- [X] - Hardware design completed (HiFi-ESP32 Plus)
- [X] - Basic I2C driver [implementation](https://github.com/tommag/PCM51xx_Arduino)
- [X] - ESPHome component development
- [x] - Advanced DSP feature implementation
- [X] - Hardware design (Amped-ESP32 Plus)
- [x] - Web interface for DSP control

### Home Assistant: Snapcast

Snapcast is a multi-room audio player that synchronizes playback across multiple devices, ensuring that audio streams play simultaneously in perfect sync. It consists of a server, which distributes audio streams, and clients, which receive and play the audio. There is a [snapcast](https://github.com/sonocotta/esparagus-snapclient) fork that was created to implement ESP32 Audio Board-specific configuration on top of the ESP32 Snapcast client. This allows us to build flexible and extendable setups connected to various sources, like Mopidy, MPD, or Home Assistant. 

<details>
  <summary>Install instructions</summary>

| Step | Screenshot |
|---|---|
| **[Flash Snapcast to the ESP32 Audio Boards](https://sonocotta.github.io/esparagus-snapclient/)** using web-flashing tool <br/> |  
| **Enable Snapcast in the MA** <br/> <br /> Got to the Ma and enable Snapcast provider. Your speaker will be discovered automatically, as long as it is running | 
| **Use your media device in the MA** <br/> <br/> Play your audio into new device | 
| **Use a group of speakers for multi-room setup** <br/><br/> In the MA settings > Players create a new group player and add as many Eparagus players as you need. Use that group speaker to get a synced audio | 

</details>

As of mid-2025 work is ongoing ([1](https://github.com/c-MM/esphome-snapclient/), [2](https://github.com/esphome/esphome/pull/8350)) to add snapcast component to ESPHome. This is based on the [original implementation](https://github.com/CarlosDerSeher/snapclient) done by CarlosDerSeher. This has the benefit of enabling all the DAC features implemented by the ESPHome driver. At the moment of writing, there are quite a few issues to be solved in the code before it can be merged, but having tested this myself on a few S3-based boards as long as Louder-Esparagus and Louder-ESP32 boards, I can say it is stable and works really well. Also
- This is the only implementation that works with ESP32-S3 (exciting!)
- This implementation allows using advanced TAS5805M DAC features available in the Esphome driver, like bridge mode and 15-band EQ. If you have Home Assistant already, that's no brainer

## Squeezelite-ESP32

Squeezelite-ESP32 is a multimedia software suite that started as a renderer (or player) of LMS (Logitech Media Server). Now it is extended with 
- **Spotify** over-the-air player using SpotifyConnect (thanks to cspot)
- **AirPlay** controller (iPhone, iTunes ...) and enjoy multi-room synchronization as well (although it's AirPlay 1 only)
- Traditional **Bluetooth** device (iPhone, Android)

And LMS itself
- Streams your local music and connects to all major online music providers (Spotify, Deezer, Tidal, Qobuz) using Logitech Media Server - a.k.a LMS with **multi-room** audio synchronization.
- LMS can be extended by numerous plugins and can be controlled using a Web browser or dedicated applications (iPhone, Android).
- It can also send audio to UPnP, Sonos, Chromecast, and AirPlay speakers/devices.

All ESP32-based boards are tested with [Squeezelite-ESP32](https://github.com/sle118/squeezelite-esp32) software, which can be flashed using nothing but a web browser. You can use [Squeezelite-ESP32 installer](https://sonocotta.github.io/esp32-audio-dock/) for that purpose.

Note that the squeezelite team only supports officially 'classic' ESP32 boards. The ESP32-S3 build is done based on the latest code and S3-specific SDKCONFIG provided by the team, but according to them, "It is not yet part of official releases, but it compiles & runs. The S3 does not have Bluetooth audio. Note that CPU performance is greatly enhanced". It is not running stably at all times, but it might depend on the configuration also. 

### How to flash and configure

Use [Installer for ESP Audio Dock](https://sonocotta.github.io/esp32-audio-dock/) to flash the firmware first. It has been preconfigured to work with ESP Audio boards and will configure all hardware automatically.

<details>
  <summary>Install instructions</summary>
  
| | |
|---|---|
| Select the correct device first	 | 
| Connect the device to the USB port and select it from the list | 
| Press `Flash` and wait around 2 minutes  | 
| (Optional) You may enter the serial console to get more information | 
| Device is in recovery mode. Connect to `squeezelite-299fac` wifi network with `squeezelite` password (your network name suffix will be different) |  |
| When redirected to the captive portal let the device scan wifi network and provide valid credentials |    |
| You can use provided IP address (http://192.168.1.99/ on the screenshot) to access settings page |  
| (Optional) You may change device names to something close to your heart| 
| Exit recovery | 

You can use it now
| Bluetooth  | Spotify Connect  | AirPlay | LMS Renderer  |
|---|---|---|---|
| | | | 

</details>

### Ethernet configuration

If you have optional Ethernet on the board, please put this config in the NVS settings

```
# ESP32
eth_config = model=w5500,cs=5,speed=20000000,intr=35,rst=14
spi_config = mosi=23,clk=18,host=2,miso=19
```

```
# ESP32S3
eth_config = model=w5500,cs=10,speed=20000000,intr=6,rst=5
spi_config = mosi=11,clk=12,host=2,miso=13
```

### Squeezelite-esp32 reboots and connection drops

The default configuration of the squeezelite-esp32 runs automatic discovery of the available LMS server nearby. In fact, it depends on it so much that in case the LMS service is not found on the network, it will reboot automatically (every few minutes). 



In many cases, if you use squeezelite for AirPlay and Spotify only and don't have an LMS server, you need to disable discovery altogether. Currently, disabling Squeezelite in the GUI does not work correctly; it places too many spaces between the commands in the autoexec command. Following `autoexec1` NVS setting can be used to disable it:

```
squeezelite -o i2s -s -disable -b 500:2000 -C 30 -d all=sdebug
```



## AirPlay 1 & 2

Squeezelite's built-in AirPlay is a first-generation implementation. [rbouteiller/airplay-esp32](https://github.com/rbouteiller/airplay-esp32) is a standalone, open-source **AirPlay 1 & 2** receiver for the ESP32 family — actively developed, with great work done by the community despite the lack of help from Apple.

It now supports HiFi-ESP32, Loud-ESP32, Louder-ESP32 and Louder-ESP32-Plus, and Amped-ESP32 out of the box, on both the 'classic' ESP32 and ESP32-S3 revisions, flashable straight from a browser — no toolchain required. Current features:

- **AirPlay 1 & 2** — appears natively in Control Center and any AirPlay app, with PTP-based multi-room sync
- **Sendspin** (experimental) — an open multi-room protocol renderer sharing the same output path, DSP, and volume control as AirPlay
- **Bluetooth A2DP** on the classic ESP32 revision — phones and laptops can stream directly whenever AirPlay is idle (the ESP32-S3 has no Bluetooth Classic radio)
- **On-device display** — the optional OLED add-on, or the Louder-ESP32-Pro's color TFT, shows track metadata and progress for AirPlay, Bluetooth, and Sendspin alike
- **USB audio (UAC)** — the ESP32-S3 revision can be built as a USB sound card for a connected computer, sharing the same DAC path
- **Full DSP control** on Louder-ESP32/Louder-ESP32-Plus — the TAS5805M/TAS5825M's on-chip EQ is fully exposed: 15 cascaded biquad sections per channel, each an arbitrary peaking filter, shelf, high/low pass, band pass, notch, phase shift, or raw coefficients, plus a crossover builder (and, on the TAS5825M, full PurePath Console 3 tuning replay)

**Not yet there:**

- **HiFi-ESP32-Plus and Amped-ESP32-Plus** (PCM5122): support is planned, driving the DAC the same way the base PCM5100A boards are (basic playback and multi-room), without exposing the PCM5122's own on-chip EQ/DRC
- **Louder-ESP32-mini and Louder-ESP32-Pro**: the TAS5805M/TAS5825M driver already exists for the Louder-ESP32 family, including its full DSP control — a build matching these boards' exact pinout is planned
- **Loud-ESP32-Plus** (Infineon MA12070P): not currently planned — there's no driver for this DAC in the project

### TAS58xx DSP: full parametric EQ and crossover control

On Louder-ESP32 and Louder-ESP32-Plus, AirPlay's web UI exposes the TAS5805M/TAS5825M's on-chip DSP in full, not just a basic tone control:

- **15 biquad (BQ) filters per channel**, usable as a full 15-band parametric equalizer
- **Bi-amp filter configuration** for 2-way speaker systems — split the signal between tweeter and woofer with independent filter chains per amplifier
- **Low-pass filtering for subwoofer tuning and bass enhancement**
- **Generic filters for speaker and room equalization** — peaking filters, shelf filters, and EQ sections with a configurable Q-factor, applied per channel individually or to both at once

| A | B |
|---|---|
|  |  |

**Work in progress:** REW (Room EQ Wizard) integration, to drive automatic room-correction algorithms directly from a measured response.

### How to Get Started

The easiest way is the browser-based [web-installer](https://rbouteiller.github.io/airplay-esp32/getting-started/flashing/) — plug your board in over USB and flash it directly from Chrome, Edge, or Opera. No toolchain, no downloads, no command line.

If you want to build it yourself — to try a board without a prebuilt image yet, or to change build settings — you can use [PlatformIO](https://platformio.org/). Install [vscode](https://code.visualstudio.com/) and the [platformio plugin](https://docs.platformio.org/en/latest/integration/ide/vscode.html), then pull the code:

```sh
git clone --recursive https://github.com/rbouteiller/airplay-esp32 && code airplay-esp32
```

When VSCode loads, find the PlatformIO tab in the left navigation, select the environment matching your board (e.g. `louder-esp32-bt`, `louder-esp32-plus-bt`, `louder-esp32-s3`, `hifi-esp32-bt`, `loud-esp32-bt`, `amped-esp32-bt` — see the project's [build environments](https://rbouteiller.github.io/airplay-esp32/reference/build-environments/) for the full list) and run the `Upload Filesystem Image` and `Upload and Monitor` tasks (assuming your board is connected over USB).

The PlatformIO magic happens now, pulling all the dependencies, platform files, and frameworks, and building a binary for your board. Once it is flashed, all that is left to do is configure WiFi credentials using the built-in access point or connect Ethernet, if you're looking for lower latency.

## Other smart home options

In case you use Domoticz or OpenHAB, or in fact any other system that supports MQTT integration, [Tasmota](https://tasmota.github.io/docs/) is a way to go with ESP32 Audio Devices, which can be integrated into TTS, Media Player, or Web-radio scenarios. Since HiFi-ESP32 and Loud-ESP32 devices only need an I2S signal to work, setting them up would not differ from any other I2S-based device. With Louder-ESP32, it is a little more involved story, but in fact, folks at the Tasmota community did a heavy lifting of porting the I2C driver, and since mid-2025, it is a simple template that can be applied in a few clicks.

Unfortunately, the default configuration of the tasmota firmware would not include I2S by default; building firmware from source is required (which makes it more fun, if you ask me). Below is an instruction that I did test with the Louder-ESP32-S3 board (Non-S3 model will require only minor adjustments along the way)

### Building Tasmota with I2S support

| # | Description  | Image
|---|---|---|
| 1 | Pull the source code from the official repo. It is a [Platformio](https://platformio.org/) project, so if you didn't have it before, [install](https://platformio.org/platformio-ide) it now <br/> `git clone https://github.com/arendst/Tasmota/` | 
| 2 | In the code repository find a file named `user_config_override.h`, and add `USE_I2S_ALL` macro right before closing `#endif` | 
| 3 | Build and flash using the conifguration named `tasmota32s3` for the S3 model, or `tasmota32` for classic ESP32 | 
| 4 | Your device will need to connect to a Wi-Fi network, and you do this as usual by connecting to a Wi-Fi hotspot and providing wifi credentials | 

### Connect to the MQTT broker

This step will depend on your specific setup, but since I have Home Assistant, I'll document the steps I had to do in the HA installation I have. Other brokers will fundamentally need the same steps, but clearly every system would have its own specific steps to take.

| # | Description  | Image
|---|---|---|
| 1 | Install the MQTT broker into HA by installing the MQTT Addon. As soon as it is installed, it will use the HA user database, so credentials will be configured elsewhere | 
| 2 | Add `mqtt_user` in the HA User list. Keep the password nearby, as we will need it to connect the ESP32 device to the broker | 
| 3 | Add MQTT integration to the HA. It will autodiscover the local MQTT broker and connect automatically | 
| 4 | Add Tasmota integration to the HA. At this point, it will only connect to MQTT, but it will not find any devices just yet | 

### Connect Louder-ESP32 to the MQTT broker

| # | Description  | Image
|---|---|---|
| 1 | Find out your device IP address (either from Serial logs or from your WiFi router), since we would need to access its web-UI to configure the device | 
| 2 | Navigate to Configure > MQTT section and update your MQTT host, user, and password settings | 
| 3 | After the device restarts, it should be able to connect to the broker. This can be confirmed in the Tasmota integration, as it will discover a new device now. | 
| 4 | Navigate to Configure > Auto-conf section and apply `Louder-ESP32S3` config. After the device restarts, you're all set. | 

### Testing audio playback with MQTT controls

| Description  | Image
|---|---|
| Using the commands described [here](https://tasmota.github.io/docs/I2S-Audio/#internal-dac) you can control device playback | 
| Start web-radio plaback <br /> topic: `cmnd/tasmota_XXXXXX/i2swr`, payload: `http://192.168.1.48:18000/bb` | 
| Stop playback <br/> topic: `cmnd/tasmota_XXXXXX/i2swr`, payload: `` | 
| Change volume <br/> topic: `cmnd/tasmota_XXXXXX/i2sgain`, payload: `85` | 
| Commands `I2SRtttl` and `I2Ssay` didn't work for me, unfortunately. I didn't have time yet to figure out what the issue is.

## Standalone Snapclient

Snapcast is a multi-room audio player that synchronizes playback across multiple devices, ensuring that audio streams play simultaneously in perfect sync. It consists of a server, which distributes audio streams, and clients, which receive and play the audio.

**Standalone Snapclient is now available for all Esparagus boards.** The main implementation ([ESP32 Snapclient](https://github.com/CarlosDerSeher/snapclient)) is an ESP32 port of the Snapcast client. An installer repository maintained by me ([Esparagus Snapclient](https://github.com/sonocotta/esparagus-snapclient)) contains pre-configured settings for all Esparagus boards as well as a web-installer project.

The [web-installer](https://sonocotta.github.io/esparagus-snapclient/) allows you to flash snapclient firmware using nothing but a browser - no additional software required. Once flashed, the Snapcast server will be auto-discovered on the same network (it can be hosted on Music Assistant, a standalone Raspberry Pi, or any other compatible server).

### Snapclient benefits

- **Perfect multi-room synchronization** - All speakers play in perfect sync across multiple rooms, similar to Sonos but with better accuracy
- **Zero configuration** - Auto-discovers Snapcast servers on the network
- **Browser-based flashing** - No need to install any tools, flash directly from the web
- **Low latency** - Optimized for minimal audio delay
- **Flexible server options** - Works with Music Assistant, standalone servers, or DIY Raspberry Pi setups
- **Cost-effective** - Build a whole-home audio system at a fraction of commercial solutions
- **Possibility to mix up client with diffrent architecture** - ESP32 side-by-side with Raspberries, etc.

## Flashing ESP32-S3

ESP32-S3 boards have two ways of firmware update: (1) similarly to classic ESP32, they can be flashed over built-in UART, or (2) uniquely for S3, over built-in USB host controller. Since it is firmware-controlled, it may be disabled if not used (or, more commonly, not available with factory default empty firmware). When an unflashed ESP32-S3 device comes into a boot loop, with a USB-CDC device appearing and disappearing every second, and **requires a special flashing initialisation sequence to get flashed**:

- Press the IO0 (FLASH) button and keep it pressed
- Press and release the RESET button, then release the FLASH button last
- ESP32-S3 will enter download mode, and the USB-CDC device will appear and stay available
- Run flashing routine as usual, either through web-serial or `esp_tool`
- This time, it is not possible to reboot the device over USB, so press RESET once more
- Device will boot normally into firmware, and if USB-CDC is enabled in the firmware, you will be able to flash it normally, download mode and reset sequence will work over USB.
- If you manage to flash firmware without USB-CDC support, you need to go through the above sequence once more

## Hardware

Please visit the [hardware](/hardware/) section for board schematics and PCB designs. Note that PCBs are shared as multi-layer PDFs.

<details>
  <summary>First generation docks</summary>



### ESP Audio Solo

| Image  | Legend  |
|---|---|
|  |  [MAX98357](https://www.analog.com/en/products/max98357a.html) DAC <br/>  Speaker Terminal  |

### ESP Audio Duo

| Image  | Legend  |
|---|---|
|  |  [MAX98357](https://www.analog.com/en/products/max98357a.html) DAC <br/>  Speaker Terminals <br/>  8MB PSRAM IC  |

### HiFi-ESP

| Image  | Legend  |
|---|---|
|  |  [PCM5100A](https://www.ti.com/product/PCM5100A) DAC <br/>  Speaker Terminals <br/>  8MB PSRAM IC <br/>  Ultra-Low noise LDO 3V3 Voltage regulator |

### Louder ESP

| Image  | Legend  |
|---|---|
|  |  [TAS5805M](https://www.ti.com/product/TAS5805M) DAC <br/>  Speaker Terminals <br/>  8MB PSRAM IC <br/>  3V3 Drop-Down voltage regulator (powers ESP32) <br/>  Input Voltage terminal |
|  (REV B, C, D) | [TAS5805M](https://www.ti.com/product/TAS5805M) DAC <br/>  Speaker Terminals <br/> - 8MB PSRAM IC (Hidden under ESP32 module) <br/> - 3V3 Drop-Down voltage regulator (powers ESP32, hidden under ESP32 module) <br/>  Input Voltage terminal 

</details>

### HiFi-ESP32

| ESP32  | ESP32-S3
|---|---|
|   |   |

### Loud-ESP32

| ESP32  | ESP32-S3
|---|---|
|  | 

### Amped-ESP32

| ESP32  |
|---|
|  |

### Amped-ESP32 with TPA3118/TPA3128 amp

Originally, I used the TPA3110 amp with Amped Esparagus and Amped-ESP32 boards for its simplicity and availability. The only issue with TAP3110 is that it lacks the MUTE pin. It does have an STBY pin, but as it turned out, it is not pop-free, meaning each time you switch it on and off, the amp makes a loud pop in the speakers. I tried changing the level slowly, but it didn't help.

Help came with a newer TPA3128 amp with revision H of the Amped-ESP32

- It does have a true MUTE pin, and now it is software-controlled on Amped-ESP32. It means that the board starts dead-quiet, and it stays quiet when the audio is paused
- MUTE pin also disables PCM5100 DAC on rev H, so line-out is also dead quiet (not that it was noise before, but why not?)
- It can work with 4.5V, so it plays even when powered from a simple USB-C, similar to Louder-ESP32. TPA3110 needs at least 8V to spin up
- TPA3128 has a marginally better audio quality, as they say. I cannot hear the difference 😉



⚠️ TPA3128 boards default to 1SPW modulation, which causes audible pops when exiting MUTE and a quiet static noise afterward. See [errata: TPA3128 1SPW modulation pop and static noise issue](/errata/tpa3128-1spw-pop-noise.md) for a permanent hardware fix.

On the latest revisions I'm switching over to the TPA3118 amp, replacing TPA3128 for a few reasons:

- MUTE schematic is updated to slow down voltage ramping speed on turn on – this helps reduce pop noise to “I can no longer hear it” level
- Modulation is hardwired to BD (1SPW is more efficient, but caused pops as well)
- Gain is fixed at a 20dB level – also helps with pops
- I added a band-pass input filter network to make sure it is noise-free.

### Louder-ESP32

| ESP32  | ESP32-S3
|---|---|
| DSC_0013_small JPG-mh | DSC_0012_small JPG-mh

### Optional SPI Ethernet module



Every board has a header that allows for soldering in a W5500 SPI Ethernet module, which is very easy to find. The only downside is that with the module installed, the board will not fit the case, unless it is cut to accommodate extra height.

| HiFi-ESP32(S3) | Loud-ESP32(S3) | Louder-ESP32(S3) |
|---|---|---|
|  |  | 

| Louder-ESP32-Plus | Amped-ESP32-Plus
|---|---|
|  |  |  

squeezelite-esp32 nvs settings that you need to apply to enable it

```
# ESP32
eth_config = model=w5500,cs=5,speed=20000000,intr=35,rst=14
spi_config = mosi=23,clk=18,host=2,miso=19
```

```
# ESP32S3
eth_config = model=w5500,cs=10,speed=20000000,intr=6,rst=5
spi_config = mosi=11,clk=12,host=2,miso=13
```

### BTL and PBTL mode (Louder and Amped boards)

The [TAS5805M DAC](https://www.ti.com/lit/ds/symlink/tas5805m.pdf) DAC used on Louder boards, and the [TPA3110D2](https://www.ti.com/product/TPA3110D2) / [TPA3128](https://www.ti.com/product/TPA3138D2) amplifiers used on Amped boards support PBTL (Parallel BTL), also known as bridge mode. In practice, this lets the amplifier deliver roughly double the current capability into a single speaker, enabling higher output power when paired with a lower-impedance load.

A common misconception is that switching to PBTL will automatically double the power into the same speaker you used in normal 2-channel BTL/stereo mode. It won’t. Even in stereo BTL operation, each channel already drives the speaker across the full supply voltage (VCC), so the power is limited by both the supply voltage and the current capability of each output driver.

In PBTL mode, both channels are paralleled and drive the same signal, effectively doubling the current capability. This allows you to safely connect a lower-impedance speaker, which is what actually increases the possible output power. If you keep the same speaker impedance you used in stereo mode, you only balance the load between the drivers — you do not gain additional output power.

Summary:
- Use 3–4 Ω speakers in PBTL mode for optimal performance
- Use 6–8 Ω speakers in standard BTL (stereo) mode

This ensures the amplifier can operate efficiently and deliver its intended power without overloading the output drivers.

In either scenario, you'd need to inform DAC/AMP to change modulation for PBTL mode (via I2C command or physical pins) and connect speakers "across" channels, so both channel drivers can contribute. This can be done in 2 alternative ways:

| Desc  | Image |
|---|---|
| Bridge outputs before the speaker connector either with jumpers or solder bridges, use (either) single wire for each speaker terminal |  |
| More recent boards introduce solder bridges instead of jumpers |  |
| Wire both outputs of the speaker terminals together |  |

#### Power figures (comparison of BTL and PBTL modes)

| DAC  | BTL (4Ω) | BTL (8Ω) | PBTL (3-4Ω) |
|---|---|---|---|
| TAS5805M |  |  |  | 
| TPA3110  |  |  |  | 
| TPA3128 |  | |  | 

#### Louder-ESP32 and Louder-ESP32-Plus (recent revisions)

Physical connections that need to be done on the board's back side (using solder bridges - normally open bridges to be closed for PBTL mode).



Note that apart from physical bridges, it also needs Bridge mode to be enabled via I2C command (see below)

#### Amped TPA3110 Amp

Physical connections that need to be done on the board (using solder bridges - normally open bridges to be closed for PBTL mode).


Both drivers will play RIGHT channel signal

#### Amped TPA3128 Amp



Both drivers will play RIGHT channel signal

#### Louder TAS5805M DAC

The most important step is to inform the Amp to change the modulation in the first place via the I2C command. In the case of sqeezelite DAC control set value is the following:
```
dac_controlset: `{"init":[{"reg":3,"val":2},{"reg":3,"val":3},{"reg":2,"val":4}],"poweron":[{"reg":3,"val":3}],"poweroff":[{"reg":3,"val":0}]}`
```
compared to the default:
```
dac_controlset: `{"init":[{"reg":3,"val":2},{"reg":3,"val":3}],"poweron":[{"reg":3,"val":3}],"poweroff":[{"reg":3,"val":0}]}`

```
One can test audio with a single speaker connected between L and R terminals (plus on one side and minus on the other). Optionally, jumpers on the board will effectively connect the second driver in parallel, doubling the current capability.

Important point: this simple setup will send only the RIGHT channel to the output; that’s just how the basic DAC setup works. In case you want true mono (LEFT + RIGHT)/2 or pure RIGHT or LEFT audio, you need to apply a mixer configuration. Full config looks like below (thanks @frdfsnlght for helping me [here](https://github.com/sonocotta/esp32-audio-dock/issues/27))

Single speaker (PBTL mode), TRUE MONO mix (L+R)/2:

| TAS5805M | TAS5825M |
|---|---|
| `{"init":[{"reg":3,"val":2},{"reg":3,"val":3},{"reg":2,"val":4},{"reg":0,"val":0},{"reg":127,"val":140},{"reg":0,"val":41},{"reg":24,"val":[0,64,38,231]},{"reg":28,"val":[0,64,38,231]},{"reg":32,"val":[0,0,0,0]},{"reg":36,"val":[0,0,0,0]},{"reg":0,"val":0},{"reg":127,"val":0}],"poweron":[{"reg":3,"val":3}],"poweroff":[{"reg":3,"val":0}]}` | `{"init":[{"reg":3,"val":2},{"reg":3,"val":3},{"reg":2,"val":4},{"reg":0,"val":0},{"reg":127,"val":140},{"reg":0,"val":11},{"reg":20,"val":[0,64,38,231]},{"reg":24,"val":[0,64,38,231]},{"reg":28,"val":[0,0,0,0]},{"reg":32,"val":[0,0,0,0]},{"reg":0,"val":0},{"reg":127,"val":0}],"poweron":[{"reg":3,"val":3}],"poweroff":[{"reg":3,"val":0}]}`

Single speaker (PBTL mode), RIGHT input only:

| TAS5805M | TAS5825M |
|---|---|
|`{"init":[{"reg":3,"val":2},{"reg":3,"val":3},{"reg":2,"val":4},{"reg":0,"val":0},{"reg":127,"val":140},{"reg":0,"val":41},{"reg":24,"val":[0,128,0,0]},{"reg":28,"val":[0,0,0,0]},{"reg":32,"val":[0,0,0,0]},{"reg":36,"val":[0,0,0,0]},{"reg":0,"val":0},{"reg":127,"val":0}],"poweron":[{"reg":3,"val":3}],"poweroff":[{"reg":3,"val":0}]} ` | `{"init":[{"reg":3,"val":2},{"reg":3,"val":3},{"reg":2,"val":4},{"reg":0,"val":0},{"reg":127,"val":140},{"reg":0,"val":11},{"reg":20,"val":[0,128,0,0]},{"reg":24,"val":[0,0,0,0]},{"reg":28,"val":[0,0,0,0]},{"reg":32,"val":[0,0,0,0]},{"reg":0,"val":0},{"reg":127,"val":0}],"poweron":[{"reg":3,"val":3}],"poweroff":[{"reg":3,"val":0}]}`

Single speaker (PBTL mode), LEFT input only:

| TAS5805M | TAS5825M |
|---|---|
|`{"init":[{"reg":3,"val":2},{"reg":3,"val":3},{"reg":2,"val":4},{"reg":0,"val":0},{"reg":127,"val":140},{"reg":0,"val":41},{"reg":24,"val":[0,0,0,0]},{"reg":28,"val":[0,128,0,0]},{"reg":32,"val":[0,0,0,0]},{"reg":36,"val":[0,0,0,0]},{"reg":0,"val":0},{"reg":127,"val":0}],"poweron":[{"reg":3,"val":3}],"poweroff":[{"reg":3,"val":0}]}` | `{"init":[{"reg":3,"val":2},{"reg":3,"val":3},{"reg":2,"val":4},{"reg":0,"val":0},{"reg":127,"val":140},{"reg":0,"val":11},{"reg":20,"val":[0,0,0,0]},{"reg":24,"val":[0,128,0,0]},{"reg":28,"val":[0,0,0,0]},{"reg":32,"val":[0,0,0,0]},{"reg":0,"val":0},{"reg":127,"val":0}],"poweron":[{"reg":3,"val":3}],"poweroff":[{"reg":3,"val":0}]}`

Physical connections:

| Image  | Legend |
|---|---|
| Stereo Mode - leave open |  |
| (Option A) Mono (PBTL) Mode, close horizontally | 
| (Option B) Mono (PBTL) Mode, close bridges (recent revisions) | 
| (Option C) Close at the speaker | 

### TAS5805M DSP capabilities

The TAS5805M DAC has a very powerful DSP, which allows doing lots of data processing on the silicon, that otherwise would take a considerable part of your CPU time. As of the moment of writing, it is mostly an undiscovered part of the DAC, since, unfortunately, TI is not making it very easy for developers. (A minute of complaint) To be more specific, you need to be (A) a proven hardware manufacturer to get access to the configuration software, namely PurePath. (B) You need to apply for a personal license and go through an approval process, and after a few weeks of waiting, you get access to the DAC configuration you asked for. (C) You find out that it will work with TI's own evaluation board, which will set you back $250 if you'd be able to find one. Otherwise, all you have is a list of I2C commands that you need to transfer to the device at your own cost. No wonder no one knows how to use it.

But moanings aside, what do you get after:

- Flexible input mixer with gain corrections
- 15 EQ with numerous filter configurations
- 3-band Dynamic Range Compression with flexible curve configuration
- Automatic Gain Limiter with flexible configuration
- Soft clipper
- and a few other things

At this moment, it is very experimental. In the perfect world, you should be able to adjust all of those settings to make your speaker-enclosure setup work the best it can, and even apply your room factors into the equation. But with the above disclaimer, I can only deliver a limited set of configurations corresponding to the most common use cases:

- Stereo mode with enabled DRC (Loudness) and AGL settings
- Full range Mono mode with DRC (Loudness) and AGL settings
- Subwoofer Mono mode with a few filter frequency options
- Bi-Amp configuration with a few crossover frequency options

All of the above are available right now for experimentation. I'm keen to hear your feedback while I move forward with porting this to other software options

- [X] - Bare [I2S TAS5805M library](https://github.com/sonocotta/esp32-tas5805m-dac)
- [X] - [espragus-snapclient](https://sonocotta.github.io/esparagus-snapclient/) with self-hosted UI (WIP)
- [X] - [ESPHome driver](https://github.com/mrtoy-me/esphome-tas5805m) with UI in the Home Assistant
- [ ] - [squeezelite-esp32](https://sonocotta.github.io/esp32-audio-dock/)

### Louder-ESP32 and Amped-ESP32 power considerations

The power adapter requirements depend on the **speaker power rating** and **impedance**.  
Since the amplifier (DAC) operates at roughly **80% efficiency**, use the following method to determine the minimum voltage and current required.

**Calculate the Required Voltage (per channel)**

1. Take the **rated power** of one speaker (e.g., **10 W** for a 2×10 W setup).
2. Take the **speaker impedance** (e.g., **8 Ω**).
3. Compute the **RMS voltage** needed to deliver that power:
   `V_RMS = sqrt(P * R)`

   For a 10 W, 8 Ω speaker:
   `V_RMS = sqrt(10W * 8Ohm} = ~9V`

4. This RMS value is your **minimum supply voltage per channel**.

**Calculate the Required Current (including efficiency)**

1. Use the RMS voltage from Step 1.
2. Compute the **output current per channel**:
   `I_out = V_rms / R`

   For 9 V RMS into 8 Ω:
   `I_out = 9V / 8Ohm = ~1.2A`

3. Adjust for amplifier efficiency (≈ 80%) to determine **input current**.
4. Multiply by the number of channels (e.g., **2 channels**).
5. Round up for safety and headroom.

**Example:**  
Two 10 W, 8 Ω speakers → `≈ 1.2 A per channel × 2 ≈ 2.4 A`, rounded up to **3 A total**.

**Final Result**

For a pair of **10 W / 8 Ω** speakers, you need a power adapter rated for at least:

- Voltage: **~9 V**
- Current: **3 A** total  
- Power: **25..30 W**

It is not recommended to go *far beyond* the voltage your speakers can handle; otherwise, the amp will blow your speakers in no time. Using 12V power source with 9V requirement probably will be totally fine, but getting 20V power source for 10W speakers is a waste of budget and added risk.

#### Connector specs

[Barrel jack used](https://www.lcsc.com/product-detail/AC-DC-Power-Connectors_XKB-Connectivity-DC-044D-2-5A-2-0-SMT_C397342.html) is spaced at 6mm hole/2mm pin, which is typically 5.5/2.5mm jack on the male side. 



The screw terminal is connected in parallel to the barrel jack; you can use either interchangeably.

On the latest boards (starting from Amped-ESP32), I switched to [barrel jack with thick middle pin](https://jlcpcb.com/partdetail/XUNPU-DC_044AA250/C720576) with a **2.5mm pin**, it’s a bit unusual but still common enough in the laptop world. It is far more comfortable in handling high currents, and importantly, much more sturdy and resistant to desoldering. 



#### Recommended models

|  Model | Image |
|---|---|
| [19V 3.42A 65W 5.5X2.5mm AC Laptop Power adapter Charger For ASUS](https://pl.aliexpress.com/item/1005005541362473.html) | 

#### Efficiency

I performed Louder-ESP32 board load tests to analyze the thermal stability of the board under maximum load. These tests output a 100Hz sin-wave with a close to rail-to-rail signal (adjusting volume and gain) into an 8-Ohm load (both BD and 1SPW modulation). I started testing with bare naked DAC. As soon as I reached the point where DAC was entering thermal shutdown, I added a small radiator on top, and once more, a larger radiator on the back side (where the thermal pad is connected to the ground plane)

| SIN wave, 100 Hz |  |  | BD-mode |  |  |  |  |  |  | 1-SPW mode |  |  |  |  |  |  |  |
|---|---|---|---|---|---|---|---|---|---|---|---|---|---|---|---|---|---|
| VCC, V | Speaker voltage | Ratio | Speakers power RMS, W | Consumed power, W | Efficiency, % | Losses, W | Naked chip, 1min run | Heat Sink 10x15mm (top cover) | Heat sink 32x32mm(back side) | Speaker voltage | Speakers power RMS, W | Consumed power, W | Efficiency, % | Losses, W | Naked chip, 1min run | Heat Sink 10x15mm (top cover) | Heat sink 32x32mm(back side) |
| 5 | 3.09 | 1.62 | 2.4 | 3.2 | 75% | 0.8 | stable | - | - | 3.09 | 2.4 | 3.1 | 76% | 0.7 | stable | - | - |
| 6 | 3.47 | 1.73 | 3.0 | 4.0 | 75% | 1.0 | stable | - | - | 3.49 | 3.0 | 3.9 | 78% | 0.9 | stable | - | - |
| 7 | 3.92 | 1.78 | 3.8 | 5.0 | 77% | 1.2 | stable | - | - | 4.05 | 4.1 | 5.4 | 77% | 1.3 | stable | - | - |
| 8 | 4.36 | 1.83 | 4.8 | 6.1 | 77% | 1.4 | stable | - | - | 4.37 | 4.8 | 5.9 | 80% | 1.2 | stable | - | - |
| 9 | 5.49 | 1.64 | 7.5 | 9.4 | 80% | 1.9 | stable | - | - | 5.49 | 7.5 | 9.2 | 82% | 1.6 | stable | - | - |
| 10 | 6.48 | 1.54 | 10.5 | 12.8 | 82% | 2.3 | stable | - | - | 6.48 | 10.5 | 12.7 | 83% | 2.2 | stable | - | - |
| 11 | 6.90 | 1.59 | 11.9 | 14.7 | 81% | 2.8 | stable | - | - | 6.90 | 11.9 | 14.2 | 84% | 2.3 | stable | - | - |
| 12 | 7.33 | 1.64 | 13.4 | 16.9 | 80% | 3.4 | stable | - | - | 7.33 | 13.4 | 16.4 | 82% | 3.0 | stable | - | - |
| 13 | 7.64 | 1.70 | 14.6 | 18.8 | 78% | 4.2 | stable | - | - | 7.66 | 14.7 | 18.3 | 80% | 3.7 | stable | - | - |
| 14 | 8.74 | 1.60 | 19.1 | 23.9 | 80% | 4.8 | stable | - | - | 8.74 | 19.1 | 23.2 | 82% | 4.1 | stable | - | - |
| 15 | 9.22 | 1.63 | 21.3 | 27.0 | 79% | 5.7 | OT warning | stable | - | 9.21 | 21.2 | 25.8 | 82% | 4.6 | stable | - | - |
| 16 | 9.70 | 1.65 | 23.5 | 30.0 | 78% | 6.5 | shutdown | OT warning | stable | 9.70 | 23.5 | 28.7 | 82% | 5.2 | OT warning | - | - |
| 17 | 10.28 | 1.65 | 26.4 | 33.0 | 80% | 6.6 | - | shutdown | OT warning | 10.29 | 26.5 | 33.0 | 80% | 6.5 | OT warning | OT warning | - |
| 18 | 11.40 | 1.58 | 32.5 | 41.0 | 79% | 8.5 | - | - | shutdown | 11.37 | 32.3 | 40.2 | 80% | 7.9 | shutdown | OT warning | OT warning |

**Conclusion:** Long-term operation without an additional heatsink is only possible up to VCC=15V. Adding a passive heatsink only helps to sustain 1-2 more volts; more power requires active cooling.

### Speakers selection

When choosing speakers, focus on realistic power ratings rather than the often-inflated numbers printed on labels.

A good reference point is 10 watts at 1% THD (Total Harmonic Distortion) — this provides clean, pleasant audio without noticeable distortion. Many manufacturers, however, market their speakers based on higher distortion levels or theoretical peaks:
	•	Nominal Power (e.g., 20W) — This is often measured at around 10% THD, which produces harsh, phone-like distortion.
	•	Rated or “Maximum” Power (e.g., 40W) — The level a speaker can handle continuously, but without limiting distortion; sound quality is not measured. It is simply a scenario where speaker is used as a room heater.
	•	Peak Power (e.g., 80–100W) — The absolute maximum a speaker can withstand for a very short burst (milliseconds), not suitable for sustained playback.

In short, when a speaker claims “100W,” it typically translates to about 10W of clean, listenable power in real use. Always prioritize low-distortion ratings over inflated wattage numbers for the best listening experience.

### OLED screen

Starting May 2025, all boards will have an OLED screen with a solder-less connector. Originally, I added the OLED header on the back side of the PCB that would require careful and skillful soldering (It is quite nice when using squeezelite since you can get quite a lot with existing plugins and settings). Later on, I managed to find the right model of the screen and corresponding connector for a reasonable price, and decided to equip every board with the connector as standard. 

At this moment, one can simply throw in a compatible OLED screen and use a small strap of double-sided adhesive to fix it mechanically. The final result is a nice and finished look



#### OLED models

Most of the 64x128 pixel OLED screen models that are very common among hobbyists will use a compatible 30-pin ribbon connector with 0.5mm pin spacing, and they are really easy to find.

|  Model | Image |
|---|---|
| [1.3" OLED Screen 128x64 SH1106 30Pin](https://www.aliexpress.com/item/1005003801387081.html) | 

#### Software side

Although you're free to use it your way, using the pinout above, I'd expect the most common case to be squeezelite, thus here are the steps you'd need to do

| # | Description | Image |
|---|---|---|
| 1 | Update NVS settings in the Web UI (switch to recovery mode first) <br/> `display_config` = `SPI,width=128,height=64,cs=15,reset=32,driver=SH1106` <br/> `spi_config` = `mosi=23,clk=18,host=2,miso=19,dc=4` <br/> You may need to replace `SH1106` with `SSD1306` depending on your model. | 
| 1 (S3) | In case of ESP32-S3, it is `display_config` = `SPI,width=128,height=64,cs=47,reset=48,driver=SH1106` <br/> `spi_config` = `mosi=11,clk=12,host=1,miso=13,dc=38` | 
| 2 | In the LMS settings install the `SqueezeESP32` plugin | 
| 3 | Update each speaker's settings in the LMS, and navigate to `Display` settings | 

### TFT screen 

Since the development of the Sendspin protocol went into the visualisation area, and the latest features allow displaying album art, track status, and progress, I'm replacing the OLED screen with a larger and colorful TFT screen. The first board to receive an upgrade is the Louder-ESP32 Pro board, introducing a 14-pin connector for a ST7789-based 320x240 pixel TFT screen.

|  Model | Image |
|---|---|
| [2.0" TFT Screen 320x240 ST7789 14Pin](https://pl.aliexpress.com/item/1005008463441614.html) |  |
| [2.4" TFT Screen 320x240 ST7789 14Pin](https://pl.aliexpress.com/item/1005008472996411.html) |  |

### Case

HiFi-ESP32(S3), Loud-ESP32(S3), Amped-ESP32 and Louder-ESP32(S3) are mechanically compatible with Raspberry Pi 3/4 cases, tested with transparent ones. 

| Hifi-ESP32 | Loud-ESP32 |
|---|---|
|  |  | 
| Amped-ESP32 | Louder-ESP32 |
|  | 
| Amped-ESP32-Plus | Louder-ESP32-Plus |
|  | 

Also, community members created a few 3D-printable designs for Louder-ESP32 boards that can be found below 

| #  | Image |
|----|----|
| [#1](https://www.printables.com/model/1469153-improved-parametric-louder-esp32-speaker) | 
| [#2](https://www.printables.com/model/1498180-louder-esp32-speaker-cab) | 
| [#3](https://www.printables.com/model/1268717-louder-esp32-enclosure) | 
| [#4](https://www.crealitycloud.com/model-detail/case-for-amped-esp32-esp32-s3) | 
| [3D Printed Case for HiFi ESP32 Plus](https://makerworld.com/en/models/2611823-hifi-esp32-plus-case#profileId-2882358) | 
| [#5](https://www.printables.com/model/1058552-louder-esp32-s3-playeramplifier-case/comments) | 
| [#6](https://www.thingiverse.com/thing:7016604) | 
| [#7](https://www.thingiverse.com/thing:6333131) | 
| [#8](https://www.thingiverse.com/thing:6326927) | 

### Parametric OpenSCAD desktop case

A community member (who asked to remain anonymous) kindly shared a parametric [OpenSCAD](https://openscad.org/) desktop case design, published here for free use. It fits the Louder-ESP32, Louder-ESP32-Plus, Amped-ESP32 and Amped-ESP32-Plus boards as is. Loud-ESP32 and Loud-ESP32-Plus boards should fit with minor adjustments.

| Render | Assembled device |
|----|----|
|  |  |

The design is a wedge-shaped enclosure that stands on the desk with the front panel facing the user. It is split into a few printable parts:

- **Housing** - the main shell, with a DC barrel jack cutout on the side and four screw channels for M3 screws
- **Housing with terminal** - the same shell with an extra cutout and mounting holes for a speaker terminal plate on the back
- **Front** - the front panel with board mounting standoffs, an OLED screen window, an IR sensor window and embossed text
- **Clamp** - a small bracket that holds the OLED screen against the front panel

Files:

- [Amped_Case.scad](/hardware/3d/Amped_Case.scad) - base design (Amped-ESP32 labeling)
- [Louder_Display.scad](/hardware/3d/Louder_Display.scad) - Louder-ESP32 variant with a taller front panel and display adapter

To export a part, open the file in OpenSCAD, set the `part` variable at the top (`1` - Housing, `2` - Housing with terminal, `3` - Front, `4` - Clamp, `5` - all parts assembled for preview), render (F6) and export to STL. The main dimensions (`X`, `Y` - front panel size, `HF`, `HR` - depth at the top and the bottom, `R` - edge radius, `W` - wall thickness) and the front text (`text1`, `text2`, ...) are defined as variables, so it is easy to adapt the case to your board or your taste. Screw threads are modelled directly in the print, so M3 screws can be driven into the front panel without inserts.

### Louder-ESP32 Pro case

Louder-ESP32-Pro boards are mechanically compatible with aluminum cases for Raspberry Pi 5. The most important components that release heat under heavy operation would be covered by the case heat release pads. On top of that, the board allows connecting a 4-pin fan with speed control and RPM readout, so it can be engaged only when needed.



### Louder-ESP32 Mini shell

Since the Louder-ESP32 Mini is designed to fit a standard speaker terminal, a vertical USB-C port was added instead of the more traditional horizontal type. It is highly recommended to protect it from sideways force, which would be common when the cable is inserted. The simplest solution is to use a 3D-printed shell that will protect the board and the USB-C port from mechanical stress.

| 42mm model  | 55mm model |
|----|----|
|  | 

You can pull it from the [folder](/hardware/9-louder-esp32-mini/3d/) or pull directly from Tinkercad ([42mm](https://www.tinkercad.com/things/3qzMPw0aLqx-louder-esp32-mini-shell) and [55mm](https://www.tinkercad.com/things/i2f2N5D1MD0-louder-esp32-mini-m-shell) model) and modify if needed. The shell is designed to be printed without support, and it is perfectly okay to print it with PLA plastic or similar material. 

### Louder-ESP32 Mini Speakers Compatibility

Most of the speakers with 42mm or 55mm square terminals would work without any mechanical work needed. Smaller terminals can be extended for Louder-ESP32-mini use with basic mechanical work 

| A  | B  | C |
|----|----|----|
|  |  | 
|   |  | 

The main benefit of the 55mm model is an onboard USB PD-trigger chip that allows use with 65W USB-C power adapters. Compared to the 5W limit of the 42mm model, this gives a healthy power headroom when used with larger speakers.

### Louder-ESP32 Mini USB-PD note

While the 55mm variant has a [Hynetek HUSB238](https://www.hynetek.com/uploadfiles/site/219/news/aabbbbdb-48c9-4a44-a6dc-2c15f53282e6.pdf) USB-PD trigger chip, capable of pulling more power from the PD-enabled power adapters (most commonly modern laptop power adapters), there are certain limitations to the way it can be used.

The chip allows two modes of operation: (a) "Dumb" GPIO mode, where voltage is requested via pin configuration and no code is needed; it will work right from the start; and (b) "Smart" mode, where voltage /curent is requested via I2C and reported back to the host.

The default mode of operation of the Louder-ESP32-Mini (55mm) is "Smart" mode, which requires an I2C driver that actively sets the required voltage on start. The ESPhome driver is currently in development ([PR6693](https://github.com/esphome/esphome/pull/6693) and [PR16572](https://github.com/esphome/esphome/pull/16572)) and might be available in the near future, but not today.

However, it is fairly easy to change the mode of operation to GPIO, so it would always require maximum available power from the power adapter. For this, you need to do two changes:

- Cut the I2C line from the MCU - it will set voltage and current to the maximum available
- Remove 1M resistor marked with (*) - it will force GPIO mode



If you decide to go with the change, since your software can't trigger higher voltage, I advise not to remove the resistor completely, but disconnect it on one end - this way you can go back to "Smart" mode later on.

## Community projects

If you don't mind showing off your projects, please send me a note or create a PR directly

| #  | Image |
|----|----|
| [V4 - DIY $90 Home Assistant bookshelf speaker for ESPHome & SendSpin or Squeezelite](https://www.reddit.com/r/homeassistant/comments/1u7dtm9/v4_diy_90_home_assistant_bookshelf_speaker_for/) | 
| [Inexpensive DIY Wi-Fi & BT speaker for Home Assistant audio](https://github.com/undotcom/home-assistant-audio-speaker-v2/) | 
| [DIY WiFi & BT audio speaker for Home Assistant, modify prebuilt 3D printed speaker](https://www.reddit.com/r/homeassistant/comments/1qw1gg6/diy_wifi_bt_audio_speaker_for_home_assistant/) | 

## Where to buy

You may support my work by ordering these products at Lectronz, Elecrow, and Tindie
- HiFi-ESP32 at [Lectronz](https://lectronz.com/products/hifi-esp32), [Elecrow](https://www.elecrow.com/hifi-esp32.html), and [Tindie](https://www.tindie.com/products/sonocotta/hifi-esp32/)
- HiFi-ESP32-Plus at [Lectronz](https://lectronz.com/products/hifi-esp32-plus), [Elecrow](https://www.elecrow.com/hifi-esp32-plus.html), and [Tindie](https://www.tindie.com/products/sonocotta/hifi-esp32-plus/)
- Loud-ESP32 at [Lectronz](https://lectronz.com/products/loud-esp32), [Elecrow](https://www.elecrow.com/loud-esp32.html), and [Tindie](https://www.tindie.com/products/sonocotta/loud-esp32/)
- Loud-ESP32-Plus at [Lectronz](https://lectronz.com/products/loud-esp32-plus), Elecrow (coming soon), and [Tindie](https://www.tindie.com/products/sonocotta/loud-esp32-plus/)
- Louder-ESP32 at [Lectronz](https://lectronz.com/products/louder-esp32), [Elecrow](https://www.elecrow.com/louder-esp32.html), and [Tindie](https://www.tindie.com/products/sonocotta/louder-esp32/)
- Louder-ESP32-Mini at [Lectronz](https://lectronz.com/products/louder-esp32-mini), [Elecrow](https://www.elecrow.com/louder-esp32-mini.html), and [Tindie](https://www.tindie.com/products/sonocotta/louder-esp32-mini/)
- Louder-ESP32-Plus at [Lectronz](https://lectronz.com/products/louder-esp32-plus), [Elecrow](https://www.elecrow.com/louder-esp32-plus.html), and [Tindie](https://www.tindie.com/products/sonocotta/louder-esp32-plus/)
- Louder-ESP32-Pro at [Lectronz](https://lectronz.com/products/louder-esp32-pro) and [Tindie](https://www.tindie.com/products/sonocotta/louder-esp32-pro/) (Elecrow coming soon as well!)
- Amped-ESP32 at [Lectronz](https://lectronz.com/products/amped-esp32), [Elecrow](https://www.elecrow.com/amped-esp32.html), and [Tindie](https://www.tindie.com/products/sonocotta/amped-esp32/)
- Amped-ESP32-Plus at [Lectronz](https://lectronz.com/products/amped-esp32-plus), [Elecrow](https://www.elecrow.com/amped-esp32-plus.html), and [Tindie](https://www.tindie.com/products/sonocotta/amped-esp32-plus/)

## Errata

- [TPA3128 1SPW modulation pop and static noise issue](/errata/tpa3128-1spw-pop-noise.md)

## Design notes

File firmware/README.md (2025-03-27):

# ESP32 Audio Dock Test Firmware

This folder contains the test firmware for the ESP32 Audio Dock, a project designed to provide high-quality audio playback using the ESP32 microcontroller and the TAS5805M digital audio amplifier.

I use this code to test different aspects of the boards, mostly TAS5805M DAC capabilities.

There are a few different ways this can be used
- [esp32-i2s-bare](/esp32-i2s-bare/) implementation, used bare naked I2S driver to sent samples to the DAC. I implemented a simple tone generator for testing purposes
- [esp32-i2s-esp8266audio](/esp32-i2s-esp8266audio/) implements basic playback controls for a few WAV files stored on the device. These are simple tone and channel test files that I use for board testing
- [esp32-i2s-web-radio](/esp32-i2s-web-radio/), similar to the `esp32-i2s-esp8266audio`, this example implements basic playback controls to play an audio stream from the web
- [esphome](/esphome/) - ESPHome yaml config files that can be used with the board with minimal changes
- [squeezelite-esp32](/squeezelite-esp32/) - sdkconfig file for building `squeezelite-esp32` project for ESP32-S3

## Software Requirements

- [PlatformIO](https://platformio.org/) installed in your development environment.
- ESP-IDF or Arduino framework (configured via PlatformIO).

## Getting Started

### 1. Clone the Repository

```bash
git clone https://github.com/your-username/esp32-audio-dock.git
cd esp32-audio-dock/firmware/esp32-i2s-bare
```

### 2. Install Dependencies

PlatformIO will automatically install the required dependencies listed in platformio.ini when you build the project.

### 3. Configure the Build

Edit the platformio.ini file to select the appropriate environment for your board. For example:

```ini
[env:louder-esp32]
board = wemos_d1_mini32
build_flags =
    -D CONFIG_DAC_TAS5805M
    -D PIN_I2C_SDA=21
    -D PIN_I2C_SCL=27
    -D PIN_I2S_FS=25
    -D PIN_I2S_SCK=26
    -D PIN_I2S_SD=22
```

### 4. Build and Upload

To build and upload the firmware to your ESP32 board, run:

```bash
pio run --target upload
```

### 5. Monitor Serial Output

To monitor the serial output, run:

```bash
pio device monitor
```

## Usage

### Command Line Interface (CLI)

The details below mostly apply to the first 3 folders for clear reasons.

All of them were built as a command-line tool that allows controlling the board functions with terminal inputs. Below is a quick summary, while more information is available by typing `help` in the ESP32 console

- `play`, `pause`, `resume`, `stop`, `prev`, `next` are the playback controls
- `list` will display the items in the playlist
- `loop` will toggle looping through the current track
- `help` command will display a handy help

Specific to the `esp32-i2s-bare` code
- `tone` command will play a square wave tone, with given frequency in Hz and amplitude in bits [0..16], `16` would mean rail-to-rail.

Specific to TAS5805M DAC (more details at my [library](https://github.com/sonocotta/esp32-tas5805m-dac) repo)
- `amp` will set an amp mode: play, mute, highz, sleep, etc
- `volume` and `vol` are digital volume controls in 8-bit and percent values respectively
- `gain` controls DAC analog gain
- `dacmode` switches between 2-channel and bridge mode
- `eq` reads and writes equilizer states for the given band in the range of -15..+15 dB
- `mod` controls the modulation and switching frequency
- `mixer` switches between MONO, STEREO, LEFT, RIGHT modes
- `fault` allows for reading DAC self-reported errors and clearing them



### Example CLI Commands

```bash
amp play          # Set the amplifier to play mode
amp highz         # Set the amplifier to high-impedance mode
amp sleep         # Put the amplifier into sleep mode
amp deepsleep     # Put the amplifier into deep sleep mode
```

## Contributing

Contributions are welcome! Feel free to open issues or submit pull requests to improve the project.

## License

This project is licensed under the Apache License v2.0. See the LICENSE file for details.

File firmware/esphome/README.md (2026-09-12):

# ESPHome Firmware Configurations

This directory contains ESPHome firmware configurations for all ESP32 Audio Dock devices. Each device has multiple configuration variants optimized for different use cases.

## Table of Contents

- [ESPHome Firmware Configurations](#esphome-firmware-configurations)
  - [Table of Contents](#table-of-contents)
  - [Overview](#overview)
  - [Hardware Variants](#hardware-variants)
    - [0. Legacy Boards](#0-legacy-boards)
    - [1. HiFi-ESP32](#1-hifi-esp32)
    - [2. Loud-ESP32](#2-loud-esp32)
    - [3. Louder-ESP32](#3-louder-esp32)
    - [4. Amped-ESP32](#4-amped-esp32)
    - [5. HiFi-ESP32-Plus](#5-hifi-esp32-plus)
    - [6. Loud-ESP32-Plus](#6-loud-esp32-plus)
    - [7. Louder-ESP32-Plus](#7-louder-esp32-plus)
    - [8. Amped-ESP32-Plus](#8-amped-esp32-plus)
    - [9. Louder-ESP32-Mini](#9-louder-esp32-mini)
    - [10. Louder-ESP32-Pro](#10-louder-esp32-pro)
  - [Configuration Variants](#configuration-variants)
    - [Standard Media Player](#standard-media-player)
    - [Snapclient](#snapclient)
    - [Sendspin](#sendspin)
    - [Voice Assistant](#voice-assistant)
  - [Quick Start](#quick-start)
  - [Building and Flashing](#building-and-flashing)
    - [Using VS Code Tasks (Fast, as long as you have good hardware)](#using-vs-code-tasks-fast-as-long-as-you-have-good-hardware)
    - [Using Docker CLI](#using-docker-cli)
    - [Initial Flash via Serial](#initial-flash-via-serial)
    - [GitHub Actions CI/CD](#github-actions-cicd)
    - [Building ESPHome on Windows with WSL (Alternative Method)](#building-esphome-on-windows-with-wsl-alternative-method)
      - [Step 1 — Install and Configure WSL 2](#step-1--install-and-configure-wsl-2)
      - [Step 2 — Install Dependencies](#step-2--install-dependencies)
      - [Step 3 — Build](#step-3--build)
      - [Step 4 — Flash the Firmware from Windows](#step-4--flash-the-firmware-from-windows)
  - [Configuration](#configuration)
    - [Customizing Device Name](#customizing-device-name)
    - [Customizing Pinout](#customizing-pinout)
    - [Advanced Configuration](#advanced-configuration)
  - [Secrets Management](#secrets-management)
    - [Setup Secrets File](#setup-secrets-file)
  - [Package System](#package-system)
    - [Core Packages](#core-packages)
    - [DAC Packages](#dac-packages)
    - [Audio Addon Packages](#audio-addon-packages)
    - [Media Player Addon Packages](#media-player-addon-packages)
    - [Sendspin Addon Packages](#sendspin-addon-packages)
    - [Snapclient Addon Packages](#snapclient-addon-packages)
    - [Feature Packages](#feature-packages)
    - [Voice Assistant Packages](#voice-assistant-packages)
    - [Using Packages](#using-packages)
    - [Remote Package Import](#remote-package-import)
  - [Additional Resources](#additional-resources)
  - [Contributing](#contributing)
  - [License](#license)

---

## Overview

All configurations use:
- **ESP-IDF framework** for better audio performance and stability. I used to provide Arduino-based examples as well, but they proved to be a poor user experience.
- **Modular package system** for code reusability (see `packages/` directory)
- **Shared secrets** for Wi-Fi credentials and API keys
- **Common features**: Wi-Fi, OTA updates, API, debug logging, RGB LED, IR receiver

Most boards are available in both **ESP32** and **ESP32-S3** variants within the same directory, the S3 variants carry `-s3-` in their filename. Plus-series boards (`5-`, `6-`, `7-`, `8-`) are available in both ESP32 and ESP32-S3 unless noted otherwise. Mini (`9-`) and Pro (`10-`) boards are ESP32-S3 only.

Each hardware variant has 3-4 firmware options depending on your use case.

---

## Hardware Variants

### 0. Legacy Boards

**DAC**: PCM5100 (I2S) or external I2S DAC  
**MCU**: ESP32 / ESP32-S2 / ESP32-S3  
**Target**: Simple reference/example implementations using Arduino framework  
**Features**: Basic I2S media player, no modular packages

**Directory**: `0-legacy-boards/`

**Configurations:**
- `esp32-duo-media-player.yaml` — Dual-core ESP32 with I2S
- `esp32-s2-solo-media-player.yaml` — ESP32-S2 single-core with I2S
- `esp32-s3-solo-media-player.yaml` — ESP32-S3 with I2S

> **Note**: These are early reference implementations using the Arduino framework. They are not recommended for new builds — use the IDF-based configurations for better performance.

---

### 1. HiFi-ESP32

**DAC**: PCM5100 (I2S)  
**MCU**: ESP32 / ESP32-S3  
**Target**: High-quality line-level audio output, 2.1V RMS  
**Features**: RGB LED, IR receiver, optional OLED display, optional Ethernet (W5500)

**Directory**: `1-hifi-esp32/`

**Configurations:**
- `hifi-esp32-idf.yaml` / `hifi-esp32-s3-idf.yaml` - Standard media player with mixer/resampler
- `hifi-esp32-idf-snapclient.yaml` / `hifi-esp32-s3-idf-snapclient.yaml` - Snapcast client with software DSP controls
- `hifi-esp32-idf-sendspin.yaml` / `hifi-esp32-s3-idf-sendspin.yaml` - Sendspin synchronized playback, very much experimental but working quite impressively well
- `hifi-esp32-s3-idf-voice-assist.yaml` - Voice assistant with wake word detection (S3 only)
- `hifi-esp32-s3-idf-voice-assist-sendspin.yaml` - Voice assistant with Sendspin synchronized playback (S3 only)

**Packages used**: `audio.yaml`, `media-player.yaml`, `light.yaml`, `ir-receiver.yaml`, `monitoring.yaml`, `oled.yaml`  
**Optional**: `ethernet-w5500.yaml`



---

### 2. Loud-ESP32

**DAC**: Dual MAX98357A (I2S)  
**MCU**: ESP32 / ESP32-S3  
**Target**: Built-in stereo amplifier for direct speaker connection (small speakers ~5W)  
**Features**: RGB LED, IR receiver, DAC enable control

**Directory**: `2-loud-esp32/`

**Configurations:**
- `loud-esp32-idf.yaml` / `loud-esp32-s3-idf.yaml` - Standard media player with mixer/resampler
- `loud-esp32-idf-snapclient.yaml` / `loud-esp32-s3-idf-snapclient.yaml` - Snapcast client with software DSP controls
- `loud-esp32-idf-sendspin.yaml` / `loud-esp32-s3-idf-sendspin.yaml` - Sendspin synchronized playback, very much experimental but working quite impressively well

**Packages used**: `audio.yaml`, `media-player.yaml`, `dac-switch.yaml`, `media-player-addon-dac-enable.yaml`, `light.yaml`, `ir-receiver.yaml`, `monitoring.yaml`, `oled.yaml`  
**Optional**: `ethernet-w5500.yaml`



---

### 3. Louder-ESP32

**DAC**: TAS5805M (I2C + I2S) with built-in DSP  
**MCU**: ESP32 / ESP32-S3  
**Target**: High-power output with advanced audio processing  
**Features**: RGB LED, IR receiver, optional OLED display, optional Ethernet (W5500)

**Directory**: `3-louder-esp32/`

**Configurations:**
- `louder-esp32-idf.yaml` / `louder-esp32-s3-idf.yaml` - Standard media player with TAS5805M DSP
- `louder-esp32-idf-snapclient.yaml` / `louder-esp32-s3-idf-snapclient.yaml` - Snapcast client with DSP controls, software DSP makes less sense since hardware DSP is much more efficient here
- `louder-esp32-idf-sendspin.yaml` / `louder-esp32-s3-idf-sendspin.yaml` - Sendspin synchronized playback, very much experimental but working quite impressively well, especially in combination with built-in DSP

**Packages used**: `dac-tas58xx.yaml`, `audio.yaml`, `audio-addon-external-dac.yaml`, `media-player.yaml`, `media-player-addon-dac-enable.yaml`, `media-player-addon-tas58xx.yaml`, `light.yaml`, `ir-receiver.yaml`, `monitoring.yaml`, `oled.yaml`  
**Optional**: `ethernet-w5500.yaml`



---

### 4. Amped-ESP32

**DAC**: PCM5100 (I2S) + TPA3110 amplifier  
**MCU**: ESP32 / ESP32-S3  
**Target**: High-quality audio with built-in amplification  
**Features**: RGB LED, IR receiver, optional OLED display, optional Ethernet (W5500)

**Directory**: `4-amped-esp32/`

**Configurations:**
- `amped-esp32-idf.yaml` / `amped-esp32-s3-idf.yaml` - Standard media player with amplifier
- `amped-esp32-idf-snapclient.yaml` / `amped-esp32-s3-idf-snapclient.yaml` - Snapcast client with software DSP controls
- `amped-esp32-idf-sendspin.yaml` / `amped-esp32-s3-idf-sendspin.yaml` - Sendspin synchronized playback

**Packages used**: `audio.yaml`, `media-player.yaml`, `amp-unmute.yaml`, `media-player-addon-amp-unmute.yaml`, `light.yaml`, `ir-receiver.yaml`, `monitoring.yaml`, `oled.yaml`  
**Optional**: `ethernet-w5500.yaml`



---

### 5. HiFi-ESP32-Plus

**DAC**: PCM5122 (I2C + I2S) with entry-level DSP  
**MCU**: ESP32 / ESP32-S3  
**Target**: High-quality audio with software-configurable volume, tone and DSP controls  
**Features**: RGB LED, IR receiver, optional OLED display, optional Ethernet (W5500)

**Directory**: `5-hifi-esp32-plus/`

**Configurations:**
- `hifi-esp32-plus-idf.yaml` / `hifi-esp32-s3-plus-idf.yaml` - Standard media player
- `hifi-esp32-plus-idf-snapclient.yaml` / `hifi-esp32-s3-plus-idf-snapclient.yaml` - Snapcast client with software DSP controls
- `hifi-esp32-plus-idf-sendspin.yaml` / `hifi-esp32-s3-plus-idf-sendspin.yaml` - Sendspin synchronized playback

**Packages used**: `dac-pcm5122.yaml`, `audio.yaml`, `audio-addon-external-dac.yaml`, `media-player.yaml`, `media-player-addon-dac-enable.yaml`, `light.yaml`, `ir-receiver.yaml`, `monitoring.yaml`, `oled.yaml`  
**Optional**: `ethernet-w5500.yaml`

---

### 6. Loud-ESP32-Plus

**DAC**: Infineon MA12070P (I2C + I2S) with built-in DSP  
**MCU**: ESP32 / ESP32-S3  
**Target**: High-efficiency Class-D amplification with entry-level DSP  
**Features**: RGB LED, IR receiver, optional OLED display, optional Ethernet (W5500), I2C volume/mute control

**Directory**: `6-loud-esp32-plus/`

**Configurations:**
- `loud-esp32-plus-idf.yaml` / `loud-esp32-s3-plus-idf.yaml` - Standard media player with MA12070P DSP
- `loud-esp32-plus-idf-sendspin.yaml` / `loud-esp32-s3-plus-idf-sendspin.yaml` - Sendspin synchronized playback
- `loud-esp32-s3-plus-idf-snapclient.yaml` - Snapcast client (S3 only, 32-bit I2S required)

The MA12070P is a high-efficiency Class-D audio amplifier with I2C digital volume control and built-in DSP. It provides software-configurable volume, mute, and enable control via I2C.

> **Note**: The snapclient configuration requires 32-bit I2S data, which is required for this DAC. At this moment snapclient doen't allow this.

**Packages used**: `dac-ma12070p.yaml`, `audio.yaml`, `media-player.yaml`, `media-player-addon-dac-mute.yaml`, `light.yaml`, `ir-receiver.yaml`, `monitoring.yaml`, `monitoring-wifi.yaml`  
**Optional**: `ethernet-w5500.yaml`, `oled.yaml`

---

### 7. Louder-ESP32-Plus

**DAC**: TAS5825M (I2C + I2S) with built-in DSP  
**MCU**: ESP32 / ESP32-S3  
**Target**: High-power output with advanced audio processing and voice assistant support  
**Features**: RGB LED, IR receiver, OLED display, optional Ethernet (W5500), microphone (voice assistant)

**Directory**: `7-louder-esp32-plus/`

**Configurations:**
- `louder-esp32-plus-idf.yaml` / `louder-esp32-s3-plus-idf.yaml` - Standard media player with TAS5825M DSP
- `louder-esp32-plus-idf-snapclient.yaml` / `louder-esp32-s3-plus-idf-snapclient.yaml` - Snapcast client
- `louder-esp32-plus-idf-sendspin.yaml` / `louder-esp32-s3-plus-idf-sendspin.yaml` - Sendspin synchronized playback with OLED display
- `louder-esp32-s3-plus-idf-voice-assist.yaml` - Voice assistant with wake word detection (S3 only)

The TAS5825M DSP allows 3 distinct EQ modes:

- 15-band EQ in ganged mode (both channels share DSP settings)



- 15-band EQ with individual controls per channel, allows fine-tuning speakers in an asymmetrical setup



- High/Low frequency profiles for bi-amp config, allows filtering out subwoofer and satellite channels with a specific frequency in the 60–150 Hz range in 10 Hz steps



The DSP also allows adjusting the gain per channel, which is essentially a balance control for speakers with different sensitivity and impedance.

> **Important**: Play sound on boot is required for the TAS5825M DAC to capture the clock signal and enable DSP configuration. Any DSP configs sent before the clock signal is established (EQ, Mixer controls) are silently ignored.

---

### 8. Amped-ESP32-Plus

**DAC**: PCM5122 (I2C + I2S) with entry-level DSP + amplifier  
**MCU**: ESP32 / ESP32-S3  
**Target**: High-quality DSP-controlled audio with built-in amplification and voice assistant support  
**Features**: RGB LED, IR receiver, optional OLED display, optional Ethernet (W5500), microphone (voice assistant)

**Directory**: `8-amped-esp32-plus/`

**Configurations:**
- `amped-esp32-plus-idf.yaml` / `amped-esp32-s3-plus-idf.yaml` - Standard media player
- `amped-esp32-plus-idf-snapclient.yaml` / `amped-esp32-s3-plus-idf-snapclient.yaml` - Snapcast client
- `amped-esp32-plus-idf-sendspin.yaml` / `amped-esp32-s3-plus-idf-sendspin.yaml` - Sendspin synchronized playback
- `amped-esp32-s3-plus-idf-voice-assist.yaml` - Voice assistant with wake word detection (S3 only)

---

### 9. Louder-ESP32-Mini

**DAC**: TAS5805M (I2C + I2S) with built-in DSP  
**MCU**: ESP32-S3  
**Target**: Compact high-power audio in PBTL mono configuration  
**Features**: No RGB LED or IR receiver (minimal footprint design), USB-PD support on the 55mm variant

**Directory**: `9-louder-esp32-mini/`

The Mini board comes in two physical sizes, identified by the number in the filename (board edge length in mm):

**42mm variant** (no USB-PD):
- `louder-esp32-s3-mini-42.yaml` - Standard media player with TAS5805M DSP (no LED)
- `louder-esp32-s3-mini-42-snapclient.yaml` - Snapcast client (no LED)
- `louder-esp32-s3-mini-42-sendspin.yaml` - Sendspin synchronized mono playback (no LED)

**55mm variant** (USB-PD via HUSB238A):
- `louder-esp32-s3-mini-55.yaml` - Standard media player with TAS5805M DSP (no LED, `husb238a.yaml` package)
- `louder-esp32-s3-mini-55-snapclient.yaml` - Snapcast client (no LED, `husb238a.yaml` package)
- `louder-esp32-s3-mini-55-sendspin.yaml` - Sendspin synchronized mono playback (no LED, `husb238a.yaml` package, work in progress!)

The Mini boards are designed for compact installations where a full-sized board won't fit. They feature TAS5805M DAC in PBTL (mono) configuration for maximum power from a compact form factor. Mixer mode (MONO/LEFT/RIGHT) can be selected per-config.

---

### 10. Louder-ESP32-Pro

**DAC**: TAS5825M (I2C + I2S) with built-in DSP  
**MCU**: ESP32-S3  
**Target**: High-power audio with TFT display, fan cooling, and voice assistant support  
**Features**: RGB LED, IR receiver, TFT SPI display (ST7789/ILI9341), active fan control, optional Ethernet (W5500), microphone (voice assistant)

**Directory**: `10-louder-esp32-pro/`

**Configurations:**
- `louder-esp32-s3-pro-idf.yaml` - Standard media player with TAS5825M DSP, TFT display, fan control
- `louder-esp32-s3-pro-idf-sendspin.yaml` - Sendspin synchronized playback with TFT display
- `louder-esp32-s3-pro-idf-snapclient.yaml` - Snapcast client with OLED display
- `louder-esp32-s3-pro-idf-voice-assist.yaml` - Voice assistant with wake word detection

The Pro board is a feature-rich platform with:
- **TFT SPI display** (ST7789 or ILI9341) for track info, album art, and clock
- **Active fan control** for thermal management during extended high-power operation
- **I2S microphone** for voice assistant capabilities
- **TAS5825M DAC** with full 15-band EQ, bi-amp mode, and presets

---

## Configuration Variants

### Standard Media Player

**Files**: `*-idf.yaml`

Full-featured ESPHome media player with:

- Native Home Assistant integration
- Media player controls (play/pause/volume)
- Mixer and resampler for announcements
- Text-to-speech (TTS) support, with ducking (lowers background music during announcements)
- IR remote control
- RGB LED status indicator

**Best for**: General Home Assistant integration, TTS announcements, standard audio playback



---

### Snapclient

**Files**: `*-snapclient.yaml`

Snapcast client implementation with enhanced features:
- Synchronized multi-room audio playback
- 18-band equalizer (software DSP controls, works on every board)
  - Frequencies: 40, 50, 60, 70, 80, 90, 100, 110, 120, 130, 140, 200, 315, 500, 800, 1250, 2000, 5000 Hz
  - Range: -15dB to +15dB per band
- Perfect audio synchronization across multiple devices
- Low latency streaming
- Two snapclient implementations available:
  - **Basic** (`snapclient-new.yaml`): @c-MM original port, no DSP controls
  - **With DSP** (`snapclient-with-dsp.yaml`): @farmed-switch fork with software BQ-filters

**Best for**: Multi-room synchronized audio with a central Snapcast server

**Requirements**: Snapcast server (can run in Home Assistant add-on)

**Drawbacks**: Very much experimental at the moment
- do not support hardware mute
- do not support voice announcements
- limitations when using together with TAS58xx DSP (may not apply EQ if it starts without audio)
- do not support displaying audio title
- do not allow control volume from the snapclient node



---

### Sendspin

**Files**: `*-sendspin.yaml`

Sendspin synchronized audio playback:

- Multi-room synchronized playback
- ESPHome native implementation
- Simplified setup compared to Snapcast
- Direct integration with Home Assistant
- Very much experimental (in beta currently)
- Allows pulling title, artist, and controlling playback

**Best for**: Multi-room audio without external server infrastructure

**Note**: Experimental feature, firmware version 2026.5.0+ required for latest sendspin features



---

### Voice Assistant

**Files**: `*-voice-assist.yaml`

Full-featured voice assistant with wake word detection:

- Local wake word detection ("okay Nabu" by default)
- Microphone input via I2S (on supported boards)
- Speaker output with announcement ducking
- Native Home Assistant Voice integration
- Visual feedback via RGB LED phases (idle / listening / thinking / replying / error / muted)
- Also available with Sendspin synchronized playback (`*-voice-assist-sendspin.yaml`)

**Available on**:
- HiFi-ESP32 S3 (`1-hifi-esp32/`) — S3 only
- Louder-ESP32-Plus (`7-louder-esp32-plus/`) — S3 only
- Amped-ESP32-Plus (`8-amped-esp32-plus/`) — S3 only
- Louder-ESP32-Pro (`10-louder-esp32-pro/`) — S3 only

**Requirements**: Home Assistant with voice assistant configured, ESPHome firmware 2026.1.4+, esparagus-echo microphone packages (included via remote import)

---

## Quick Start

1. **Choose your hardware variant** from the directories:
   - `0-legacy-boards/` — Legacy Arduino-based examples (not recommended for new builds)
   - `1-hifi-esp32/` — PCM5100 line-level output
   - `2-loud-esp32/` — MAX98357A built-in amp
   - `3-louder-esp32/` — TAS5805M high-power with DSP
   - `4-amped-esp32/` — PCM5100 + TPA3110 amp
   - `5-hifi-esp32-plus/` — PCM5122 with DSP
   - `6-loud-esp32-plus/` — MA12070P high-efficiency Class-D
   - `7-louder-esp32-plus/` — TAS5825M high-power with DSP (ESP32 / ESP32-S3)
   - `8-amped-esp32-plus/` — PCM5122 + amp + voice assist (ESP32 / ESP32-S3)
   - `9-louder-esp32-mini/` — TAS5805M compact PBTL mono (ESP32-S3)
   - `10-louder-esp32-pro/` — TAS5825M with TFT display and fan (ESP32-S3)

2. **Choose your MCU variant** (where applicable):
   - `*-esp32-*` — ESP32 variant
   - `*-esp32-s3-*` — ESP32-S3 variant

3. **Choose your configuration variant**:
   - Standard: `*-idf.yaml`
   - Snapclient: `*-snapclient.yaml`
   - Sendspin: `*-sendspin.yaml`
   - Voice Assistant: `*-voice-assist.yaml` (selected boards, S3 only)
   - Voice Assistant + Sendspin: `*-voice-assist-sendspin.yaml` (HiFi-ESP32 S3 only)

4. **Configure secrets** (see [Secrets Management](#secrets-management))

5. **Build and flash** (see [Building and Flashing](#building-and-flashing))

---

## Building and Flashing

### Using VS Code Tasks (Fast, as long as you have good hardware)

The project includes VS Code tasks for building with Docker:

1. Open any configuration YAML file
2. Run task: `Tasks > Run Build Task > ESPHome: Build Current File (Stable)`
3. For OTA updates: `ESPHome: Build and Upload OTA (Stable)`

### Using Docker CLI

```bash
# Build
docker run --rm \
  -v "$(pwd)/1-hifi-esp32:/config" \
  -v "$(pwd)/packages:/config/packages" \
  -v "$(pwd)/secrets/secrets.yaml:/config/secrets.yaml" \
  -v "$(pwd)/.esphome-cache:/cache" \
  -e PLATFORMIO_BUILD_CACHE_DIR=/cache/.pio-cache \
  -it esphome/esphome:latest \
  compile /config/hifi-esp32-idf.yaml

# Upload via OTA
docker run --rm \
  --network=host \
  -v "$(pwd)/1-hifi-esp32:/config" \
  -v "$(pwd)/packages:/config/packages" \
  -v "$(pwd)/secrets/secrets.yaml:/config/secrets.yaml" \
  -v "$(pwd)/.esphome-cache:/cache" \
  -it esphome/esphome:latest \
  run /config/hifi-esp32-idf.yaml --device OTA
```

### Initial Flash via Serial

For first-time setup, flash via USB:

```bash
docker run --rm \
  --device=/dev/ttyUSB0 \
  -v "$(pwd)/1-hifi-esp32:/config" \
  -v "$(pwd)/packages:/config/packages" \
  -v "$(pwd)/secrets/secrets.yaml:/config/secrets.yaml" \
  -it esphome/esphome:latest \
  run /config/hifi-esp32-idf.yaml --device /dev/ttyUSB0
```

### GitHub Actions CI/CD

The project includes automated build pipeline (`.github/workflows/build-esphome.yml`) that:
- Automatically discovers all configuration files
- Builds all variants in parallel on pull requests
- Uses caching for faster builds

### Building ESPHome on Windows with WSL (Alternative Method)

> Contributed by [@harrison110](https://github.com/harrison110) in [#123](https://github.com/sonocotta/esp32-audio-dock/issues/123#issuecomment-4255961275)

Building via Docker on Windows without a properly configured WSL can result in **very** long build times (7000+ seconds). Using WSL 2 brings this down to ~3 minutes.

#### Step 1 — Install and Configure WSL 2

1. Install WSL with Ubuntu (or your preferred distro) from **PowerShell**:
   ```powershell
   wsl --install -d Ubuntu
   ```
   Make sure you have at least the minimum recommended version — Docker currently recommends **WSL 2.1.5** or newer. Older versions will cause issues with the build.

2. Create the WSL config file to set resource limits. Without this, WSL may not have enough resources, which will drastically increase build times.

   Create the file `C:\Users\YOUR_USER_NAME\.wslconfig` with the following contents (adjust values to your system):
   ```ini
   [wsl2]
   memory=8GB
   processors=6
   swap=4GB
   localhostForwarding=true
   ```

#### Step 2 — Install Dependencies

Inside WSL, install Python and any other required dependencies. Also install **Docker Desktop** on Windows (it integrates with WSL 2 automatically).

#### Step 3 — Build

Clone the repository inside WSL and follow the standard build instructions. Running the Docker build from within WSL keeps all files on the Linux filesystem, which is the key to fast build times.

#### Step 4 — Flash the Firmware from Windows

Flashing is easier to do from Windows rather than from WSL to avoid USB/hardware access issues.

1. Install `esptool` on Windows:
   ```powershell
   pip install esptool
   ```

2. Flash using the following command (adjust `--chip`, `--port`, and the path to your binary as needed):
   ```powershell
   python -m esptool --chip esp32s3 --port COM7 --baud 460800 write-flash 0x0 "FIRMWARE.FACTORY.BIN_LOCATION"
   ```

3. If the compiled `.bin` file is still on the WSL filesystem, get its Windows path with:
   ```bash
   wslpath -w "$(find ./3-louder-esp32 -name firmware.factory.bin | head -n 1)"
   ```
   Change the folder name to match your target device.

4. To find the correct COM port in PowerShell:
   ```powershell
   Get-CimInstance Win32_SerialPort | Select-Object DeviceID,Name,Description
   ```

---

## Configuration

### Customizing Device Name

Each configuration file has substitutions at the top:

```yaml
substitutions:
  name: esphome-web-dc95a8  # Change this to your device name
  friendly_name: HiFi-ESP32  # Change this to friendly name
```

### Customizing Pinout

All GPIO pins are defined in the `substitutions:` section. Modify these if you have your own hardware:

```yaml
substitutions:
  i2s_lrclk_pin: GPIO25
  i2s_bclk_pin: GPIO26
  i2s_dout_pin: GPIO22
  # ... more pins
```

### Advanced Configuration

Most functionality is imported from packages. To customize:

1. **Base audio packages**: `packages/audio.yaml`, `packages/sendspin-audio.yaml`
2. **DAC-specific packages**: `packages/dac-tas58xx.yaml`, `packages/dac-pcm5122.yaml`, `packages/dac-ma12070p.yaml`, `packages/dac-tas58xx-biamp.yaml`, `packages/dac-tas58xx-presets.yaml`
3. **Feature addons**: `packages/media-player-addon-*.yaml`, `packages/sendspin-addon-*.yaml`, `packages/snapclient-addon-*.yaml`
4. **Optional features**: `packages/ethernet-w5500.yaml`, `packages/oled.yaml`, `packages/tft-spi.yaml`, `packages/fan.yaml`

Feel free to experiment with IR/RGB/Rotary/OLED configuration. Only the most basic configuration is provided to get you started. Don't hesitate to extend it.

---

## Secrets Management

### Setup Secrets File

1. Copy the example: `cp secrets/secrets.yaml.example secrets/secrets.yaml`
2. Edit `secrets/secrets.yaml` with your credentials:

```yaml
# Wi-Fi credentials
esphome_wifi_ssid: "YourWiFiSSID"
esphome_wifi_password: "YourWiFiPassword"
esphome_ap_password: "YourAPPassword"
esphome_ota_password: "YourOTAPassword"
esphome_api_key: "YourAPIKey"

# Alternative naming (also supported)
wifi_ssid: "YourWiFiSSID"
wifi_password: "YourWiFiPassword"
```
---

## Package System

The package system promotes code reusability across different hardware variants. Packages use the `id: !extend` addon pattern, meaning they extend base components without duplicating configuration. This allows mixing and matching features cleanly.

### Core Packages

- **`audio.yaml`**: Base I2S audio configuration — defines `i2s_speaker_id`, mixer, resampler
- **`media-player.yaml`**: Media player with announcement ducking — defines `external_media_player`
- **`media-player-no-light.yaml`**: Media player without RGB LED control — for boards without LEDs (e.g., Louder-ESP32-Mini)
- **`sendspin.yaml`**: Sendspin multi-room player — defines `sendspin_group_media_player`, `external_media_player`, and audio sources
- **`sendspin-no-light.yaml`**: Sendspin without RGB LED control — for boards without LEDs
- **`snapclient-new.yaml`**: Snapcast client (@c-MM original port, basic implementation)
- **`snapclient-with-dsp.yaml`**: Snapcast client with 18-band software EQ (@farmed-switch fork)
- **`light.yaml`**: RGB LED support (WS2812)
- **`ir-receiver.yaml`**: Infrared remote control
- **`monitoring.yaml`**: Debug and system monitoring
- **`monitoring-wifi.yaml`**: Extended Wi-Fi diagnostics — signal strength, IP address, and connection state sensors
- **`oled.yaml`**: SSD1306 OLED display
- **`tft-spi.yaml`**: TFT SPI display (ST7789/ILI9341) — used on Pro boards
- **`fan.yaml`**: Active fan control with temperature sensor — used on Pro boards

### DAC Packages

- **`dac-switch.yaml`**: Simple GPIO enable/disable switch for MAX98357A (Loud-ESP32)
- **`dac-pcm5122.yaml`**: PCM5122 DAC via I2C with volume, EQ and DSP controls (HiFi-ESP32-Plus, Amped-ESP32-Plus)
- **`dac-ma12070p.yaml`**: Infineon MA12070P Class-D amplifier with I2C control — digital volume, mute, enable (Loud-ESP32-Plus)
- **`dac-tas58xx.yaml`**: TAS5805M/TAS5825M DAC using the unified `tas58xx` driver — 15-band EQ, mixer, gain control (Louder-ESP32, Louder-ESP32-Plus, Louder-ESP32-Mini, Louder-ESP32-Pro)
- **`dac-tas58xx-biamp.yaml`**: TAS58xx in bi-amp mode with per-channel EQ
- **`dac-tas58xx-presets.yaml`**: TAS58xx with high/low frequency filter presets for subwoofer/satellite setups

### Audio Addon Packages

These addon packages extend the base audio stack to connect an external DAC component:

- **`audio-addon-external-dac.yaml`**: Extends `i2s_speaker_id` to add `audio_dac: external_dac` — needed for Louder-ESP32, HiFi-ESP32-Plus, and other boards with I2C-controlled DACs
- **`sendspin-audio-addon-external-dac.yaml`**: Same as above but extends the Sendspin audio stack
- **`sendspin-audio-addon-ma12070p.yaml`**: Extends Sendspin audio stack specifically for MA12070P DAC

### Media Player Addon Packages

These addon packages extend `external_media_player` with board-specific behavior:

- **`media-player-addon-dac-enable.yaml`**: Turns DAC GPIO on when playback starts, off when idle — used on Loud-ESP32, HiFi-ESP32-Plus, Louder-ESP32, Louder-ESP32-Mini
- **`media-player-addon-dac-enable-dual.yaml`**: Same as above but for dual DAC configurations
- **`media-player-addon-dac-mute.yaml`**: Controls DAC mute via I2C (MA12070P) or GPIO on play/idle — used on Loud-ESP32-Plus
- **`media-player-addon-amp-unmute.yaml`**: Unmutes the TPA3110/TPA3128 amplifier on playback — used on Amped-ESP32
- **`media-player-addon-tas58xx.yaml`**: TAS58xx-specific playback hooks — plays startup sync sound on boot, enables DAC on play, overtemp monitoring
- **`media-player-addon-tas58xx-dual.yaml`**: Same as above for dual TAS58xx configurations

### Sendspin Addon Packages

These addon packages extend Sendspin player components with board-specific behavior:

- **`sendspin-addon-dac-enable.yaml`**: Turns DAC GPIO on/off with Sendspin playback state
- **`sendspin-addon-dac-mute.yaml`**: Controls DAC mute via I2C (MA12070P) with Sendspin playback
- **`sendspin-addon-amp-unmute.yaml`**: Unmutes amplifier with Sendspin playback
- **`sendspin-addon-tas58xx.yaml`**: TAS58xx hooks for Sendspin — startup sync sound on boot, DAC enable on play
- **`sendspin-addon-esp32.yaml`**: ESP32 (non-S3) specific wifi/audio optimizations for Sendspin
- **`sendspin-addon-oled.yaml`**: Scrolling track info on OLED display during Sendspin playback
- **`sendspin-addon-tft.yaml`**: Track info and display management on TFT SPI display during Sendspin playback (Pro boards)
- **`sendspin-addon-voice-assist-tas58xx.yaml`**: TAS58xx hooks for voice assistant + Sendspin combined configs

### Snapclient Addon Packages

These addon packages extend snapclient with board-specific behavior:

- **`snapclient-addon-dac-enable.yaml`**: Enables DAC GPIO on snapclient play
- **`snapclient-addon-dac-mute.yaml`**: Controls DAC mute via I2C (MA12070P) with snapclient playback
- **`snapclient-addon-external-dac.yaml`**: Extends snapclient to use external I2C DAC
- **`snapclient-addon-tas58xx.yaml`**: TAS58xx EQ control and startup sync for snapclient
- **`snapclient-addon-amp-enable.yaml`**: Enables amplifier with snapclient playback

### Feature Packages

- **`amp-unmute.yaml`**: GPIO switch definition for TPA3110/TPA3128 amplifier mute control
- **`ethernet-w5500.yaml`**: W5500 SPI Ethernet module (replaces Wi-Fi config when used)
- **`husb238a.yaml`**: HUSB238A USB-PD sink controller over I2C — attached/voltage/current sensing, capabilities, and voltage selection (Louder-ESP32-Mini, optional)

### Voice Assistant Packages

Voice assistant packages are sourced from the external [esparagus-echo](https://github.com/sonocotta/esparagus-echo) repository and imported via remote packages:

- **`microphone-i2s.yaml`**: I2S microphone configuration
- **`microphone.yaml`**: Microphone sensor entity
- **`voice-assist.yaml`**: Full voice assistant with wake word detection
- **`voice-assist-sendspin.yaml`**: Voice assistant combined with Sendspin synchronized playback
- **`media-player-addon-voice-assist.yaml`**: Media player hooks for voice assistant integration

### Using Packages

Packages are imported in each config file's `packages:` block:

```yaml
packages:
  audio: !include packages/audio.yaml
  media_player: !include packages/media-player.yaml
  light: !include packages/light.yaml
  ir_receiver: !include packages/ir-receiver.yaml
  monitoring: !include packages/monitoring.yaml
  oled: !include packages/oled.yaml
```

This keeps device-specific configs clean and maintainable.

### Remote Package Import

All config files include a commented-out remote import block that allows pulling packages directly from GitHub without a local clone:

```yaml
packages:
  esparagus_remote:
    url: https://github.com/sonocotta/esp32-audio-dock
    ref: main
    files:
      - firmware/esphome/packages/audio.yaml
      - firmware/esphome/packages/media-player.yaml
      - firmware/esphome/packages/light.yaml
      - firmware/esphome/packages/ir-receiver.yaml
      - firmware/esphome/packages/monitoring.yaml
      - firmware/esphome/packages/oled.yaml
```

Uncomment this block and remove the local `!include` imports to use the latest published packages from the repository automatically. Many configs already use the remote import method by default.

---

## Additional Resources

- **Main Project**: [ESP32 Audio Dock Repository](../../README.md)
- **ESPHome Documentation**: https://esphome.io
- **Home Assistant**: https://www.home-assistant.io
- **Snapcast**: https://github.com/badaix/snapcast
- **Discord Community**: Join our [Discord](https://discord.gg/PtnaAaQMpS) for support

---

## Contributing

ESPHome is very dynamic ecosystem at the moment, when it comes to Sendspin, things are changing literally every day. Found an issue - let me know, create PR, create issue. Help others to figure it out.

---

## License

See [LICENSE](../../LICENSE) in the root directory.

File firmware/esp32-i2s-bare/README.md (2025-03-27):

# esp32-i2s-bare example firmware

Please see the README level above

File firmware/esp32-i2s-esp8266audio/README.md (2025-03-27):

# esp32-i2s-esp8266audio example firmware

Simple example demonstrates how to use [ESP8266Audio](https://github.com/earlephilhower/ESP8266Audio) library to initialize the DAC and generate audio.

Library has plenty of examples on it's own, I selected self contained example, that plays test audio from flash storage

To make it work you need to flash LittleFS image by using `Upload Filesystem Image` task. It will automatically pick up all files from `data` folder.

After applying power audio starts automatically.

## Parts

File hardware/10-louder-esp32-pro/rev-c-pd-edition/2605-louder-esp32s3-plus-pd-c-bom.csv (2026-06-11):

ID | Name | Designator | Footprint | Quantity | Manufacturer Part | Manufacturer | Supplier | Supplier Part | Price
1 | 100nF | C59,C61,C62,C63,C66 | C0402 | 5 | CL05B104KO5NNNC | SAMSUNG(三星) | LCSC | C1525 | 0.002
2 | 100nF | C15,C13 | R0402 | 2 | CL05B104KO5NNNC | SAMSUNG | LCSC | C1525 | 0.002
3 | ICS-43432 | U4 | SENSOR-SMD_ICS-43432 | 1 | ICS-43432 | TDK InvenSense(应美盛) | LCSC | C574021
4 | 470uF | C9,C10,C18,C19,C22,C25 | CAP-TH_BD8.0-P3.50-D0.6-FD | 6 | 25PX470MEFC8X11.5 | Rubycon(红宝石) | LCSC | C88730 | 0.127
5 | 22uF | C20,C21,C6 | C0603 | 3 | CL10A226MQ8NRNC | SAMSUNG(三星) | LCSC | C59461 | 0.017
6 | 100kΩ | R26 | R0402 | 1 | 0402WGF1003TCE | UNI-ROYAL(厚声) | LCSC | C25741 | 0.001
7 | FPC 0.5MM 14P Vertical mounting type H2.0mm | FPC1 | FPC-SMD_14P-P1.00-AFC11-S14ICC-00 | 1 | AFC11-S14ICC-00 | JS(钜硕电子) | LCSC | C11070 | 0.113
8 | 10K | R9,R17,R72,R5,R53,R54,R55,R4,R31 | R0402 | 9 | 0402WGF1002TCE | UniOhm | LCSC | C25744 | 0.001
9 | TS24CA | SW1 | SW-SMD_TS24CA | 1 | TS24CA | SHOU HAN(首韩) | LCSC | C393942 | 0.025
10 | 100nF | C12,C2,C16 | C0402 | 3 | CL05B104KO5NNNC | SAMSUNG | LCSC | C1525 | 0.002
11 | TS-1088-AR02016 | SW2 | SW-SMD_L3.9-W3.0-P4.45 | 1 | TS-1088-AR02016 | XUNPU(讯普) | LCSC | C720477 | 0.056
12 | XL-1615RGBC-WS2812B | LED3 | LED-SMD_4P-L1.6-W1.5_XL-1615RGBC-WS2812B | 1 | XL-1615RGBC-WS2812B | XINGLIGHT(成兴光) | LCSC | C5349954 | 0.063
13 | 100 | R8,R10,R6,R7 | R0402 | 4 | 0402WGF1000TCE | UniOhm | LCSC | C25076 | 0.001
14 | 10uF | C14 | C0603 | 1 | CL10A106KP8NNNC | SAMSUNG | LCSC | C19702 | 0.018
15 | IRM-H638T/TR2 | CGQ1 | SENSOR-SMD_IRM-H638T-TR2-TL | 1 | IRM-H638T/TR2 | EVERLIGHT(亿光) | LCSC | C91447 | 0.241
16 | 10uF | C3,C52 | C0603 | 2 | CL10A106KP8NNNC | SAMSUNG(三星) | LCSC | C19702 | 0.018
17 | HR913550A | RJ2 | RJ45-TH_HR913550A | 1 | HR913550A | HANRUN(汉仁) | LCSC | C163507 | 1.075
18 | 1kΩ | R43,R44 | R0402 | 2 | 0402WGF1001TCE | UNI-ROYAL(厚声) | LCSC | C11702 | 0.001
19 | 22nF | C35 | C0402 | 1 | 0402B223K500NT | FH(风华) | LCSC | C1532 | 0.003
20 | 6.8nF | C67,C68 | C0603 | 2 | 0603B682K500NT | FH(风华) | LCSC | C1631 | 0.005
21 | 33Ω | R38,R40,R41,R42 | R0603 | 4 | 0603WAF330JT5E | UNI-ROYAL(厚声) | LCSC | C23140 | 0.001
22 | 51Ω | R45,R46,R48,R49 | R0603 | 4 | 0603WAF510JT5E | UNI-ROYAL(厚声) | LCSC | C23197 | 0.001
23 | 10Ω | R47 | R0603 | 1 | 0603WAF100JT5E | UNI-ROYAL(厚声) | LCSC | C22859 | 0.002
24 | 1MΩ | R51 | R1206 | 1 | 1206W4F1004T5E | UNI-ROYAL(厚声) | LCSC | C17927 | 0.004
25 | 18pF | C56,C57 | C0402 | 2 | 0402CG180J500NT | FH(风华) | LCSC | C1549 | 0.002
26 | 100Ω | L1 | L0805 | 1 | GZ2012D101TF | Sunlord(顺络) | LCSC | C1015
27 | 12.4kΩ | R33 | R0402 | 1 | 0402WGF1242TCE | UNI-ROYAL(厚声) | LCSC | C11692 | 0.001
28 | 0Ω | R34,R35,R36 | R0603 | 3 | 0603WAF0000T5E | UNI-ROYAL(厚声) | LCSC | C21189 | 0.002
29 | 25MHz | X1 | OSC-SMD_4P-L3.2-W2.5-BL | 1 | X322525MOB4SI | YXC(扬兴晶振) | LCSC | C9006 | 0.075
30 | 10nF | C4,C5 | C0402 | 2 | CL05B103KB5NNNC | SAMSUNG(三星) | LCSC | C15195 | 0.002
31 | 4.7uF | C7 | C0603 | 1 | CL10A475KO8NNNC | SAMSUNG(三星) | LCSC | C19666 | 0.014
32 | W5500 | U2 | LQFP-48_L7.0-W7.0-P0.50-LS9.0-BL | 1 | W5500 | WIZNET | LCSC | C32843 | 2.693
33 | 100uF | C11,C72 | CAP-SMD_L3.5-W2.8 | 2 | TAJB107K006RNJ | AVX | LCSC | C16133 | 0.466
34 | WJ2EDGR-5.08-2P | CN2,CN4 | CONN-TH_WJ2EDGR-5.08-2P | 2 | WJ2EDGR-5.08-02P-14-00A | KANGNEX(康奈克斯电气) | LCSC | C71370 | 0.194
35 | WJ2EDGR-5.08-2P | CN3,CN5 | CONN-TH_WJ2EDGR-5.08-2P | 2 | WJ2EDGR-5.08-02P-14-00A | KANGNEX(康奈克斯电气) | LCSC | C8383 | 0.047
36 | 68uH | L3,L5 | IND-SMD_L5.0-W5.0_FNR50XXS | 2 | FNR5040S680MT | cjiang(长江微电) | LCSC | C167977 | 0.093
37 | ESP32-S3-WROOM-1U-N8R8 | U1 | WIRELM-SMD_ESP32-S3-WROOM-1U | 1 | ESP32-S3-WROOM-1U-N8R8 | ESPRESSIF(乐鑫) | LCSC | C2980300 | 5.664
38 | B5819W_C8598 | D2,D1 | SOD-123_L2.7-W1.6-LS3.7-RD-1 | 2 | B5819W SL | CJ(江苏长电/长晶) | LCSC | C8598 | 0.024
39 | XL1509-5.0_C2902368 | U6 | SOIC-8_L4.9-W3.9-P1.27-LS6.0-TR | 1 | XL1509-5.0 | UMW(广东友台半导体) | LCSC | C2902368 | 0.225
40 | 22uF | C74,C24,C28,C30,C34,C1 | C1206 | 6 | CL31A226KAHNNNE | SAMSUNG(三星) | LCSC | C12891 | 0.169
41 | BM04B-SRSS-TB(LF)(SN) | CN1 | CONN-SMD_BM04B-SRSS-TB | 1 | BM04B-SRSS-TB(LF)(SN) | JST | LCSC | C160390 | 0.234
42 | S8050_C2146 | Q2,Q4 | SOT-23-3_L3.0-W1.7-P0.95-LS2.9-BR | 2 | S8050 J3Y(RANGE:200-350) | CJ(江苏长电/长晶) | LCSC | C2146 | 0.013
43 | 10Ω | R1 | R0805 | 1 | 0805W8F100JT5E | UNI-ROYAL(厚声) | LCSC | C17415 | 0.003
44 | 1uF | C8,C46,C50,C36,C43 | C0603 | 5 | CL10A105KB8NNNC | SAMSUNG(三星) | LCSC | C15849 | 0.011
45 | 1kΩ | R11 | R0603 | 1 | 0603WAF1001T5E | UNI-ROYAL(厚声) | LCSC | C21190 | 0.002
46 | CH224K | U12 | ESSOP-10_L4.9-W3.9-P1.0-LS6.0-TL-EP | 1 | CH224K | WCH(南京沁恒) | LCSC | C970725 | 0.617
47 | FC-2012HRK-620D | FAULT1 | LED0805-R-RD | 1 | NCD0805R1 | 国星光电 | LCSC | C84256 | 0.013
48 | 17-21SUYC/TR8 | WARN1 | LED0805-R-RD | 1 | KT-0805黄灯 | KENTO | LCSC | C2296 | 0.012
49 | 100nF | C49,C23,C27,C29,C33 | C0603 | 5 | CC0603KRX7R9BB104 | YAGEO | LCSC | C14663 | 0.011
50 | 470nF | C51,C53,C54,C55 | C0805 | 4 | CL21B474KBFNNNE | SAMSUNG(三星) | LCSC | C13967 | 0.018
51 | 10uH | L6,L8,L7,L9 | IND-SMD_L7.1-W6.6 | 4 | PSPMAA063T-100M-ANP | PROD(谱罗德) | LCSC | C436568 | 0.127
52 | 10kΩ | R15,R13 | R0402 | 2 | 0402WGF1002TCE | UNI-ROYAL(厚声) | LCSC | C25744 | 0.001
53 | TAS5825MRHBR | U9 | VQFN-32_L5.0-W5.0-P0.50-TL-EP | 1 | TAS5825MRHBR | TI(德州仪器) | LCSC | C471049 | 2.677
54 | 680nF | C44,C45,C47,C48 | C0805 | 4 | CL21B684KBFVPNE | SAMSUNG(三星) | LCSC | C472832 | 0.062
55 | KT-0603R | LED1 | LED0603-R-RD | 1 | KT-0603R | null | LCSC | C2286 | 0.007
56 | XL1509-3.3E1 | U3 | SOP-8_L4.9-W3.9-P1.27-LS6.0-BL | 1 | XL1509-3.3E1 | XLSEMI(芯龙) | LCSC | C74193 | 0.298
57 | 10uF | C17 | C0805 | 1 | CL21A106KAYNNNE | SAMSUNG | LCSC | C15850 | 0.048
58 | TYPE-C 16PIN 2MD(073) | USB1 | USB-C-SMD_TYPE-C-6PIN-2MD-073 | 1 | TYPE-C 16PIN 2MD(073) | SHOU HAN(首韩) | LCSC | C2765186 | 0.074

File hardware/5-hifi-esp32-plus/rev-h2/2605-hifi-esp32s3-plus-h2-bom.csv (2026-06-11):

ID | Name | Designator | Footprint | Quantity | Manufacturer Part | Manufacturer | Supplier | Supplier Part | Price
1 | SOLDERJUMPER_3_OPEN_SHORT | JP3 | JUMPER:SOLDERJUMPER-3_P1.3MM_BRIDGED12_PAD1.0X1.5MM COPY | 1
2 | Header-Female-2.54_1x6 | P1,P2 | HDR-TH_6P-P2.54-V-F | 2 | 2.54-1*6P母 | BOOMELE(博穆精密) | LCSC | C40877 | 0.088
3 | 3V3 | LED3 | LED0603-R-RD | 1 | KT-0603R | KENTO | LCSC | C2286 | 0.007
4 | 470Ω | R7,R9,R10,R11 | R0402 | 4 | 0402WGF4700TCE | UNI-ROYAL(厚声) | LCSC | C25117 | 0.001
5 | 10uF | C22,C3,C4,C12,C21 | CAP-SMD_L3.2-W1.6-R-RD | 5 | TAJA106K016RNJ | AVX | LCSC | C7171 | 0.15
6 | 100kΩ | R3 | R0402 | 1 | 0402WGF1003TCE | UNI-ROYAL(厚声) | LCSC | C25741 | 0.001
7 | PCM5122PWR | U9 | TSSOP-28_L9.8-W6.6-P0.65-BL | 1 | PCM5122PWR | TI(德州仪器) | LCSC | C962071 | 2.293
8 | 100nF | C39,C29,C30,C31,C16,C41 | C0402 | 6 | CL05B104KO5NNNC | SAMSUNG | LCSC | C1525 | 0.002
9 | 10K | R2,R23,R6,R20 | R0402 | 4 | 0402WGF1002TCE | UniOhm | LCSC | C25744 | 0.001
10 | TS-1088-AR02016 | SW1,SW3 | SW-SMD_L3.9-W3.0-P4.45 | 2 | TS-1088-AR02016 | XUNPU(讯普) | LCSC | C720477 | 0.056
11 | 100 | R13,R14,R18,R21 | R0402 | 4 | 0402WGF1000TCE | UniOhm | LCSC | C25076 | 0.001
12 | ESP32-S3-WROOM-1(N16R8) | U4 | WIRELM-SMD_ESP32-S3-WROOM-1 | 1 | ESP32-S3-WROOM-1-N16R8 | ESPRESSIF(乐鑫) | LCSC | C2980300 | 5.664
13 | TPLP5907MFX-3.3 | U1,U2 | SOT-23-5_L2.9-W1.6-P0.95-LS2.8-BR | 2 | TPLP5907MFX-3.3 | TECH PUBLIC(台舟) | LCSC | C5370990 | 0.098
14 | PJ-328A0-B | CN1 | AUDIO-TH_PJ-328A0-B | 1 | PJ-328A0-B | XKB Connectivity(中国星坤) | LCSC | C381129 | 0.259
15 | 2.2uF | C1,C2 | C0603 | 2 | CL10A225KO8NNNC | SAMSUNG(三星) | LCSC | C23630 | 0.009
16 | 100nF | C5,C6,C7,C8 | C0603 | 4 | CC0603KRX7R9BB104 | YAGEO | LCSC | C14663 | 0.011
17 | 200kΩ | R5,R30 | R0402 | 2 | 0402WGF2003TCE | UNI-ROYAL(厚声) | LCSC | C25764 | 0.001
18 | 10uF | C52,C57,C58 | C0603 | 3 | CL10A106KP8NNNC | SAMSUNG(三星) | LCSC | C19702 | 0.018
19 | FPC-05F-30PH20 | FPC3 | FPC-SMD_30P-P0.50_XUNPU_FPC-05F-30PH20 | 1 | FPC-05F-30PH20 | XUNPU(讯普) | LCSC | C2856808 | 0.131
20 | 10uF | C17,C28,C32 | C0805 | 3 | CL21A106KAYNNNE | SAMSUNG | LCSC | C15850 | 0.048
21 | 2.2uF | C9,C20 | C0805 | 2 | CL21A225KBQNNNE | SAMSUNG(三星) | LCSC | C377773 | 0.022
22 | B5819W_C8598 | D4,D1 | SOD-123_L2.8-W1.8-LS3.7-RD | 2 | B5819W | CJ | LCSC | C8598 | 0.024
23 | 1uF | C10,C11,C15,C19 | C0805 | 4 | CL21B105KBFNNNE | SAMSUNG | LCSC | C28323 | 0.017
24 | 2.2nF | C13,C14 | C0805 | 2 | CL21C222JBFNNNE | SAMSUNG | LCSC | C28260 | 0.029
25 | 470 | R1,R4 | R0603 | 2 | 0603WAF4700T5E | UniOhm | LCSC | C23179 | 0.002
26 | AMS1117-3.3 | U8 | SOT-223-3_L6.5-W3.4-P2.30-LS7.0-BR | 1 | AMS1117-3.3 | AMS | LCSC | C6186 | 0.199
27 | 100uF | C18 | CAP-SMD_L3.5-W2.8 | 1 | TAJB107K006RNJ | AVX | LCSC | C16133 | 0.466
28 | 22uF | C37,C38 | C1206 | 2 | CL31A226KAHNNNE | SAMSUNG(三星) | LCSC | C12891 | 0.169
29 | 10uF | C40 | C0603 | 1 | CL10A106KP8NNNC | SAMSUNG | LCSC | C19702 | 0.018
30 | 5.1kΩ | R16,R17 | R0402 | 2 | 0402WGF5101TCE | UNI-ROYAL(厚声) | LCSC | C25905 | 0.001
31 | TYPE-C 16PIN 2MD(073) | USB1 | USB-C-SMD_TYPE-C-6PIN-2MD-073 | 1 | TYPE-C 16PIN 2MD(073) | SHOU HAN(首韩) | LCSC | C2765186 | 0.074
32 | IRM-56384 | IR1 | OPTO-TH_IRM-56384 | 1 | IRM-56384 | EVERLIGHT(亿光) | LCSC | C72048 | 0.158

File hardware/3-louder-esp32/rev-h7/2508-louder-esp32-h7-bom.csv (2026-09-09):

ID | Name | Designator | Footprint | Quantity | Manufacturer Part | Manufacturer | Supplier | Supplier Part | Price
1 | TS-1088-AR02016 | SW3,SW4 | SW-SMD_L3.9-W3.0-P4.45 | 2 | TS-1088-AR02016 | XUNPU(讯普) | LCSC | C720477 | 0.056
2 | DB126V-5.0-2P | U6,U10,U11 | CONN-TH_2P-P5.00_L7.8-W10.0 | 3 | DB126V-5.0-2P-GN-P | DORABO(地博电气) | LCSC | C395849 | 0.112
3 | KT-0603R | LED1 | LED0603-R-RD | 1 | KT-0603R | null | LCSC | C2286 | 0.008
4 | 10kΩ | R13,R10,R9 | R0402 | 3 | 0402WGF1002TCE | UNI-ROYAL(厚声) | LCSC | C25744 | 0.003
5 | 1N5819WS | D4 | SOD-323_L1.8-W1.3-LS2.5-RD | 1 | 1N5819WS | Hottech(合科泰) | LCSC | C191023 | 0.014
6 | 100nF | C2,C5,C6,C8,C9,C10,C11,C13 | C0603 | 8 | CC0603KRX7R9BB104 | YAGEO(国巨) | LCSC | C14663 | 0.014
7 | 1uF | C3,C21,C19 | C0603 | 3 | CL10A105KB8NNNC | SAMSUNG(三星) | LCSC | C15849 | 0.022
8 | 100nF | C42,C23,C27,C29,C33,C35,C36 | C0603 | 7 | CC0603KRX7R9BB104 | YAGEO | LCSC | C14663 | 0.014
9 | 100Ω | R1,R4,R5,R7,R8 | R0402 | 5 | 0402WGF1000TCE | UNI-ROYAL(厚声) | LCSC | C25076 | 0.003
10 | 470nF | C4,C7,C12,C15 | C0805 | 4 | CL21B474KBFNNNE | SAMSUNG(三星) | LCSC | C13967 | 0.023
11 | 22uF | C24,C28,C30,C34,C1,C22,C37,C38 | C1206 | 8 | CL31A226KAHNNNE | SAMSUNG(三星) | LCSC | C12891 | 0.171
12 | 470uF | C25,C26,C31,C32 | CAP-SMD_BD10.0-L10.3-W10.3-FD | 4 | CS1V471M-CRG10 | SEMTECH | LCSC | C96181 | 0.111
13 | 10uH | L1,L2,L3,L4 | IND-SMD_L7.1-W6.6 | 4 | PSPMAA0603-100M-ANF | PROD(谱罗德) | LCSC | C436542 | 0.101
14 | TAS5805MPWPR | U2 | HTSSOP-28_L9.7-W4.4-P0.65-LS6.4-BL-EP | 1 | TAS5805MPWPR | Texas Instruments | LCSC | C478472 | 1.268
15 | B5819W_C8598 | D1 | SOD-123_L2.7-W1.6-LS3.7-RD-1 | 1 | B5819W SL | CJ(江苏长电/长晶) | LCSC | C8598 | 0.031
16 | 68uH | L5 | IND-SMD_L5.0-W5.0_FNR50XXS | 1 | FNR5040S680MT | cjiang(长江微电) | LCSC | C167977 | 0.093
17 | XL1509-3.3E1 | U3 | SOP-8_L4.9-W3.9-P1.27-LS6.0-BL | 1 | XL1509-3.3E1 | XLSEMI(芯龙) | LCSC | C74193 | 0.301
18 | Header-Female-2.54_1x6 | P1,P2 | HDR-TH_6P-P2.54-V-F | 2 | 2.54-1*6P母 | BOOMELE(博穆精密) | LCSC | C40877 | 0.089
19 | S8050_C2146 | Q1,Q2 | SOT-23-3_L3.0-W1.7-P0.95-LS2.9-BR | 2 | S8050 | CJ | LCSC | C2146 | 0.017
20 | 2.2uF | C14,C20 | C0603 | 2 | CL10A225KO8NNNC | SAMSUNG(三星) | LCSC | C23630 | 0.019
21 | 10uF | C52,C57,C58 | C0603 | 3 | CL10A106KP8NNNC | SAMSUNG(三星) | LCSC | C19702 | 0.032
22 | 200kΩ | R6,R30 | R0402 | 2 | 0402WGF2003TCE | UNI-ROYAL(厚声) | LCSC | C25764 | 0.002
23 | FPC-05F-30PH20 | FPC3 | FPC-SMD_30P-P0.50_XUNPU_FPC-05F-30PH20 | 1 | FPC-05F-30PH20 | XUNPU(讯普) | LCSC | C2856808 | 0.132
24 | 100kΩ | R33 | R0402 | 1 | 0402WGF1003TCE | UNI-ROYAL(厚声) | LCSC | C25741 | 0.003
25 | M7 | D3 | SMA_L4.3-W2.6-LS5.2-RD | 1 | M7 | MDD | LCSC | C95872 | 0.01
26 | DC-044A-A250 | DC2 | DC-IN-TH_DC-044A-A250 | 1 | DC-044A-A250 | XUNPU(讯普) | LCSC | C720576 | 0.257
27 | 100 | R2,R3,R18,R21 | R0402 | 4 | 0402WGF1000TCE | UniOhm | LCSC | C25076 | 0.003
28 | 10uF | C17 | C0805 | 1 | CL21A106KAYNNNE | SAMSUNG | LCSC | C15850 | 0.086
29 | 100nF | C16,C39,C41 | C0402 | 3 | CL05B104KO5NNNC | SAMSUNG | LCSC | C1525 | 0.005
30 | 100uF | C18 | CAP-SMD_L3.5-W2.8 | 1 | TAJB107K006RNJ | AVX | LCSC | C16133 | 0.526
31 | 10uF | C40 | C0603 | 1 | CL10A106KP8NNNC | SAMSUNG | LCSC | C19702 | 0.032
32 | 5.1kΩ | R16,R17 | R0402 | 2 | 0402WGF5101TCE | UNI-ROYAL(厚声) | LCSC | C25905 | 0.003
33 | 10K | R19,R20,R22,R23,R24 | R0402 | 5 | 0402WGF1002TCE | UniOhm | LCSC | C25744 | 0.003
34 | ESP32-WROVER-IE(8MB) | U1 | WIFI-SMD_ESP32-WROVER-E | 1 | ESP32-WROVER-IE-N8R8 | ESPRESSIF(乐鑫) | LCSC | C701351 | 5.64
35 | CH340C | U4 | SOP-16_L10.0-W3.9-P1.27-LS6.0-BL | 1 | CH340C | WCH | LCSC | C84681 | 0.59
36 | TYPE-C 16PIN 2MD(073) | USB1 | USB-C-SMD_TYPE-C-6PIN-2MD-073 | 1 | TYPE-C 16PIN 2MD(073) | SHOU HAN(首韩) | LCSC | C2765186 | 0.075
37 | IRM-56384 | IR1 | OPTO-TH_IRM-56384 | 1 | IRM-56384 | EVERLIGHT(亿光) | LCSC | C72048 | 0.167

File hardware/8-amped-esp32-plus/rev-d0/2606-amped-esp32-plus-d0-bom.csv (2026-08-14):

ID | Name | Designator | Footprint | Quantity | Manufacturer Part | Manufacturer | Supplier | Supplier Part | Price
1 | 1uF | C4,C5,C8,C9 | C0805 | 4 | CL21B105KBFNNNE | SAMSUNG(三星) | LCSC | C28323 | 0.051
2 | 100nF | C6,C7,C27,C35,C36,C60,C62,C64,C68,C70 | C0603 | 10 | CC0603KRX7R9BB104 | YAGEO | LCSC | C14663 | 0.018
3 | 1uF | C10,C11,C15,C19 | C0805 | 4 | CL21B105KBFNNNE | SAMSUNG | LCSC | C28323 | 0.051
4 | 220pF | C12,C83,C84,C85 | C0402 | 4 | 0402B221K500NT | FH(风华) | LCSC | C1530 | 0.003
5 | 1uF | C13,C86 | C0603 | 2 | CL10A105KB8NNNC | SAMSUNG(三星) | LCSC | C15849 | 0.028
6 | 2.2uF | C14,C20 | C0603 | 2 | CL10A225KO8NNNC | SAMSUNG(三星) | LCSC | C23630 | 0.02
7 | 100nF | C16,C29,C30,C31,C39,C41 | C0402 | 6 | CL05B104KO5NNNC | SAMSUNG | LCSC | C1525 | 0.006
8 | 10uF | C17,C28,C32 | C0805 | 3 | CL21A106KAYNNNE | SAMSUNG | LCSC | C15850 | 0.101
9 | 100uF | C18,C72,C103 | CAP-SMD_L3.5-W2.8 | 3 | TAJB107K006RNJ | AVX | LCSC | C16133 | 0.534
10 | 100nF | C21,C48,C77,C78,C79,C80,C81,C90 | C0603 | 8 | CC0603KRX7R9BB104 | YAGEO(国巨) | LCSC | C14663 | 0.018
11 | 10uF | C22,C23,C24,C25,C26 | CAP-SMD_L3.2-W1.6-R-RD | 5 | TAJA106K016RNJ | AVX | LCSC | C7171 | 0.164
12 | 22uF | C37,C38,C61,C63,C67,C71,C74 | C1206 | 7 | CL31A226KAHNNNE | SAMSUNG(三星) | LCSC | C12891 | 0.322
13 | 10uF | C40 | C0603 | 1 | CL10A106KP8NNNC | SAMSUNG | LCSC | C19702 | 0.039
14 | 10uF | C52,C57,C58 | C0603 | 3 | CL10A106KP8NNNC | SAMSUNG(三星) | LCSC | C19702 | 0.039
15 | 470uF | C56,C66,C69 | CAP-SMD_BD10.0-L10.3-W10.3-FD | 3 | CS1V471M-CRG10 | SEMTECH | LCSC | C96181 | 0.102
16 | 2.2nF | C65,C73 | C0805 | 2 | CL21C222JBFNNNE | SAMSUNG | LCSC | C28260 | 0.032
17 | 2.2uF | C75,C76 | C0805 | 2 | CL21A225KBQNNNE | SAMSUNG(三星) | LCSC | C377773 | 0.091
18 | 1nF | C82,C87,C88,C89 | C0603 | 4 | CL10B102KB8NNNC | SAMSUNG(三星) | LCSC | C1588 | 0.007
19 | PJ-328A0-B | CN1 | AUDIO-TH_PJ-328A0-B | 1 | PJ-328A0-B | XKB Connectivity(中国星坤) | LCSC | C381129 | 0.263
20 | B5819W_C8598 | D1,D4 | SOD-123_L2.8-W1.8-LS3.7-RD | 2 | B5819W | CJ | LCSC | C8598 | 0.03
21 | B5819W_C8598 | D2 | SOD-123_L2.7-W1.6-LS3.7-RD-1 | 1 | B5819W SL | CJ(江苏长电/长晶) | LCSC | C8598 | 0.03
22 | M7 | D3 | SMA_L4.3-W2.6-LS5.2-RD | 1 | M7 | MDD | LCSC | C95872 | 0.011
23 | 1N5819WS | D5,D6 | SOD-323_L1.8-W1.3-LS2.5-RD | 2 | 1N5819WS | Hottech(合科泰) | LCSC | C191023 | 0.014
24 | DC-044A-A250 | DC2 | DC-IN-TH_DC-044A-A250 | 1 | DC-044A-A250 | XUNPU(讯普) | LCSC | C720576 | 0.256
25 | FPC-05F-30PH20 | FPC3 | FPC-SMD_30P-P0.50_XUNPU_FPC-05F-30PH20 | 1 | FPC-05F-30PH20 | XUNPU(讯普) | LCSC | C2856808 | 0.132
26 | IRM-56384 | IR1 | OPTO-TH_IRM-56384 | 1 | IRM-56384 | EVERLIGHT(亿光) | LCSC | C72048 | 0.116
27 | 68uH | L3 | IND-SMD_L5.0-W5.0_FNR50XXS | 1 | FNR5040S680MT | cjiang(长江微电) | LCSC | C167977 | 0.093
28 | YI453215U101-8R0T | L6,L7,L8,L9 | IND-SMD_L4.5-W3.2-CBW453215U800T | 4 | YI453215U101-8R0T | YJYCOIN(益嘉源) | LCSC | C2926397 | 0.164
29 | KT-0603R | LED1 | LED0603-R-RD | 1 | KT-0603R | null | LCSC | C2286 | 0.008
30 | Header-Female-2.54_1x6 | P1,P2 | HDR-TH_6P-P2.54-V-F | 2 | 2.54-1*6P母 | BOOMELE(博穆精密) | LCSC | C40877 | 0.089
31 | S8050_C2146 | Q1,Q2 | SOT-23-3_L3.0-W1.7-P0.95-LS2.9-BR | 2 | S8050 | CJ | LCSC | C2146 | 0.017
32 | AO3400A | Q5 | SOT-23-3_L2.9-W1.6-P1.90-LS2.8-BR | 1 | AO3400A | AOS | LCSC | C20917 | 0.085
33 | 10kΩ | R4,R12,R15,R29,R36,R42,R43 | R0402 | 7 | 0402WGF1002TCE | UNI-ROYAL(厚声) | LCSC | C25744 | 0.008
34 | 10K | R5,R11,R19,R20,R22,R23 | R0402 | 6 | 0402WGF1002TCE | UniOhm | LCSC | C25744 | 0.008
35 | 200kΩ | R6,R30 | R0402 | 2 | 0402WGF2003TCE | UNI-ROYAL(厚声) | LCSC | C25764 | 0.003
36 | 100 | R9,R10,R18,R21 | R0402 | 4 | 0402WGF1000TCE | UniOhm | LCSC | C25076 | 0.008
37 | 5.1kΩ | R16,R17 | R0402 | 2 | 0402WGF5101TCE | UNI-ROYAL(厚声) | LCSC | C25905 | 0.004
38 | 470Ω | R24,R31,R32 | R0402 | 3 | 0402WGF4700TCE | UNI-ROYAL(厚声) | LCSC | C25117 | 0.006
39 | 100kΩ | R33,R44,R45 | R0402 | 3 | 0402WGF1003TCE | UNI-ROYAL(厚声) | LCSC | C25741 | 0.008
40 | 470 | R34,R35 | R0603 | 2 | 0603WAF4700T5E | UniOhm | LCSC | C23179 | 0.005
41 | 1kΩ | R37,R38,R39,R40 | R0402 | 4 | 0402WGF1001TCE | UNI-ROYAL(厚声) | LCSC | C11702 | 0.007
42 | 5.6kΩ | R41 | R0603 | 1 | 0603WAF5601T5E | UNI-ROYAL(厚声) | LCSC | C23189 | 0.007
43 | TS-1088-AR02016 | SW3,SW4 | SW-SMD_L3.9-W3.0-P4.45 | 2 | TS-1088-AR02016 | XUNPU(讯普) | LCSC | C720477 | 0.056
44 | PCM5122PWR | U1 | TSSOP-28_L9.8-W6.6-P0.65-BL | 1 | PCM5122PWR | TI(德州仪器) | LCSC | C962071 | 2.603
45 | DB126V-5.0-2P | U3,U14,U15 | CONN-TH_2P-P5.00_L7.8-W10.0 | 3 | DB126V-5.0-2P-GN-P | DORABO(地博电气) | LCSC | C395849 | 0.112
46 | ESP32-WROVER-E-N8R8 | U4 | WIFI-SMD_ESP32-WROVER-IE8MB | 1 | ESP32-WROVER-E-N8R8 | ESPRESSIF(乐鑫) | LCSC | C2973667 | 3.836
47 | XL1509-5.0_C2902368 | U6 | SOIC-8_L4.9-W3.9-P1.27-LS6.0-TR | 1 | XL1509-5.0 | UMW(广东友台半导体) | LCSC | C2902368 | 0.264
48 | CH340C | U7 | SOP-16_L10.0-W3.9-P1.27-LS6.0-BL | 1 | CH340C | WCH | LCSC | C84681 | 0.588
49 | AMS1117-3.3 | U8 | SOT-223-3_L6.5-W3.4-P2.30-LS7.0-BR | 1 | AMS1117-3.3 | AMS | LCSC | C6186 | 0.203
50 | TPA3118D2DAPR | U9 | HTSSOP-32_L11.0-W6.1-P0.65-LS8.1-BL-EP | 1 | TPA3118D2DAPR | TI(德州仪器) | LCSC | C46497 | 1.102
51 | TPLP5907MFX-3.3 | U12,U13 | SOT-23-5_L2.9-W1.6-P0.95-LS2.8-BR | 2 | TPLP5907MFX-3.3 | TECH PUBLIC(台舟) | LCSC | C5370990 | 0.1
52 | TYPE-C 16PIN 2MD(073) | USB1 | USB-C-SMD_TYPE-C-6PIN-2MD-073 | 1 | TYPE-C 16PIN 2MD(073) | SHOU HAN(首韩) | LCSC | C2765186 | 0.074

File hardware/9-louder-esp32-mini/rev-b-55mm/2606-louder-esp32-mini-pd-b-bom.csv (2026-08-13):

ID | Name | Designator | Footprint | Quantity | Manufacturer Part | Manufacturer | Supplier | Supplier Part | Price
1 | 1uF | C1,C2,C7,C12 | C0402 | 4 | CL05A105KA5NQNC | SAMSUNG(三星) | LCSC | C52923 | 0.013
2 | 10uF | C3 | C0402 | 1 | CL05A106MQ5NUNC | SAMSUNG(三星) | LCSC | C15525 | 0.026
3 | 470nF | C4,C22 | C0805 | 2 | CL21B474KBFNNNE | SAMSUNG(三星) | LCSC | C13967 | 0.029
4 | 100nF | C5,C6,C8,C9,C10,C11,C13,C14 | C0603 | 8 | CC0603KRX7R9BB104 | YAGEO(国巨) | LCSC | C14663 | 0.019
5 | 100uF | C15,C16,C17,C19 | CAP-SMD_L7.3-W4.3_H2.8 | 4 | T521D107M025ATE040 | KEMET(基美) | LCSC | C696814 | 1.466
6 | 10uF | C18,C29,C30,C31,C32,C33 | C1206 | 6 | CL31A106KBHNNNE | SAMSUNG(三星) | LCSC | C13585 | 0.291
7 | 100nF | C20,C21,C24,C25 | C0603 | 4 | CC0603KRX7R9BB104 | YAGEO | LCSC | C14663 | 0.019
8 | 100uF | C23 | CAP-SMD_L3.5-W2.8 | 1 | TAJB107K006RNJ | AVX | LCSC | C16133 | 0.534
9 | 100nF | C26 | C0402 | 1 | CL05B104KO5NNNC | SAMSUNG | LCSC | C1525 | 0.006
10 | 22uF | C28 | C1206 | 1 | CL31A226KAHNNNE | SAMSUNG(三星) | LCSC | C12891 | 0.304
11 | HDGC4001SMD-S-1P | CN1,CN3 | CONN-SMD_HDGC4001SMD-S-1P | 2 | HDGC4001SMD-S-1P | HDGC(华德共创) | LCSC | C5197183 | 0.102
12 | B5819W_C8598 | D1 | SOD-123_L2.7-W1.6-LS3.7-RD-1 | 1 | B5819W SL | CJ(江苏长电/长晶) | LCSC | C8598 | 0.03
13 | 10uH | L1,L2 | IND-SMD_L7.1-W6.6 | 2 | PSPMAA063T-100M-ANP | PROD(谱罗德) | LCSC | C436568 | 0.132
14 | 68uH | L5 | IND-SMD_L5.0-W5.0_FNR50XXS | 1 | FNR5040S680MT | cjiang(长江微电) | LCSC | C167977 | 0.093
15 | 10kΩ | R1,R5,R7 | R0402 | 3 | 0402WGF1002TCE | UNI-ROYAL(厚声) | LCSC | C25744 | 0.008
16 | 1MΩ | R2,R3,R4 | R0402 | 3 | 0402WGF1004TCE | UNI-ROYAL(厚声) | LCSC | C26083 | 0.005
17 | 10K | R11,R14 | R0402 | 2 | 0402WGF1002TCE | UniOhm | LCSC | C25744 | 0.008
18 | TS-1088-AR02016 | SW1,SW2 | SW-SMD_L3.9-W3.0-P4.45 | 2 | TS-1088-AR02016 | XUNPU(讯普) | LCSC | C720477 | 0.056
19 | TYPE-C 16PLT-H10.0 | U1 | TYPE-C-SMD_USB4120-03-C | 1 | TYPE-C 16PLT-H10.0 | SHOU HAN(首韩) | LCSC | C3151749 | 0.308
20 | TAS5805MPWPR | U2 | HTSSOP-28_L9.7-W4.4-P0.65-LS6.4-BL-EP | 1 | TAS5805MPWPR | Texas Instruments | LCSC | C478472 | 1.574
21 | HUSB238A-BB001-QN16R | U3 | QFN-16_L3.0-W3.0-P0.50-BL-EP1.7 | 1 | HUSB238A-BB001-QN16R | Hynetek(慧能泰) | LCSC | C24833806 | 0.652
22 | ESP32-S3-WROOM-1U-N8R8 | U5 | WIRELM-SMD_ESP32-S3-WROOM-1U | 1 | ESP32-S3-WROOM-1U-N8R8 | ESPRESSIF(乐鑫) | LCSC | C2980300 | 5.76
23 | XL1509-3.3E1 | U6 | SOP-8_L4.9-W3.9-P1.27-LS6.0-BL | 1 | XL1509-3.3E1 | XLSEMI(芯龙) | LCSC | C74193 | 0.299

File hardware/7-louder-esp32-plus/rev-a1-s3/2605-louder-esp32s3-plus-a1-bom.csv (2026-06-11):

ID | Name | Designator | Footprint | Quantity | Manufacturer Part | Manufacturer | Supplier | Supplier Part | Price
1 | 22uF | C1,C22,C24,C28,C30,C34,C37,C38 | C1206 | 8 | CL31A226KAHNNNE | SAMSUNG(三星) | LCSC | C12891 | 0.169
2 | 2.2uF | C14,C20 | C0603 | 2 | CL10A225KO8NNNC | SAMSUNG(三星) | LCSC | C23630 | 0.009
3 | 100nF | C16,C39,C41 | C0402 | 3 | CL05B104KO5NNNC | SAMSUNG | LCSC | C1525 | 0.002
4 | 10uF | C17 | C0805 | 1 | CL21A106KAYNNNE | SAMSUNG | LCSC | C15850 | 0.048
5 | 100uF | C18 | CAP-SMD_L3.5-W2.8 | 1 | TAJB107K006RNJ | AVX | LCSC | C16133 | 0.466
6 | 100nF | C23,C27,C29,C33,C49 | C0603 | 5 | CC0603KRX7R9BB104 | YAGEO | LCSC | C14663 | 0.011
7 | 470uF | C25,C26,C31,C32 | CAP-SMD_BD10.0-L10.3-W10.3-FD | 4 | CS1V471M-CRG10 | SEMTECH | LCSC | C96181 | 0.128
8 | 1uF | C36,C43,C46,C50 | C0603 | 4 | CL10A105KB8NNNC | SAMSUNG(三星) | LCSC | C15849 | 0.011
9 | 10uF | C40 | C0603 | 1 | CL10A106KP8NNNC | SAMSUNG | LCSC | C19702 | 0.018
10 | 680nF | C44,C45,C47,C48 | C0805 | 4 | CL21B684KBFVPNE | SAMSUNG(三星) | LCSC | C472832 | 0.062
11 | 470nF | C51,C53,C54,C55 | C0805 | 4 | CL21B474KBFNNNE | SAMSUNG(三星) | LCSC | C13967 | 0.018
12 | 10uF | C52,C57,C58 | C0603 | 3 | CL10A106KP8NNNC | SAMSUNG(三星) | LCSC | C19702 | 0.018
13 | B5819W_C8598 | D1 | SOD-123_L2.7-W1.6-LS3.7-RD-1 | 1 | B5819W SL | CJ(江苏长电/长晶) | LCSC | C8598 | 0.024
14 | 1N5819WS | D2,D4 | SOD-323_L1.8-W1.3-LS2.5-RD | 2 | 1N5819WS | Hottech(合科泰) | LCSC | C191023 | 0.011
15 | M7 | D3 | SMA_L4.3-W2.6-LS5.2-RD | 1 | M7 | MDD | LCSC | C95872 | 0.009
16 | DC-044A-A250 | DC2 | DC-IN-TH_DC-044A-A250 | 1 | DC-044A-A250 | XUNPU(讯普) | LCSC | C720576 | 0.255
17 | FC-2012HRK-620D | FAULT1 | LED0805-R-RD | 1 | NCD0805R1 | 国星光电 | LCSC | C84256 | 0.013
18 | FPC-05F-30PH20 | FPC3 | FPC-SMD_30P-P0.50_XUNPU_FPC-05F-30PH20 | 1 | FPC-05F-30PH20 | XUNPU(讯普) | LCSC | C2856808 | 0.131
19 | IRM-56384 | IR1 | OPTO-TH_IRM-56384 | 1 | IRM-56384 | EVERLIGHT(亿光) | LCSC | C72048 | 0.158
20 | 68uH | L5 | IND-SMD_L5.0-W5.0_FNR50XXS | 1 | FNR5040S680MT | cjiang(长江微电) | LCSC | C167977 | 0.093
21 | 10uH | L6,L7,L8,L9 | IND-SMD_L7.1-W6.6 | 4 | PSPMAA063T-100M-ANP | PROD(谱罗德) | LCSC | C436568 | 0.127
22 | KT-0603R | LED1 | LED0603-R-RD | 1 | KT-0603R | null | LCSC | C2286 | 0.007
23 | Header-Female-2.54_1x6 | P1,P2 | HDR-TH_6P-P2.54-V-F | 2 | 2.54-1*6P母 | BOOMELE(博穆精密) | LCSC | C40877 | 0.088
24 | 10kΩ | R2,R12,R13,R14,R15 | R0402 | 5 | 0402WGF1002TCE | UNI-ROYAL(厚声) | LCSC | C25744 | 0.001
25 | 10K | R4,R20,R22,R23,R31 | R0402 | 5 | 0402WGF1002TCE | UniOhm | LCSC | C25744 | 0.001
26 | 200kΩ | R6,R30 | R0402 | 2 | 0402WGF2003TCE | UNI-ROYAL(厚声) | LCSC | C25764 | 0.001
27 | 5.1kΩ | R16,R17 | R0402 | 2 | 0402WGF5101TCE | UNI-ROYAL(厚声) | LCSC | C25905 | 0.001
28 | 100 | R18,R21 | R0402 | 2 | 0402WGF1000TCE | UniOhm | LCSC | C25076 | 0.001
29 | 100kΩ | R33 | R0402 | 1 | 0402WGF1003TCE | UNI-ROYAL(厚声) | LCSC | C25741 | 0.001
30 | TS-1088-AR02016 | SW3,SW4 | SW-SMD_L3.9-W3.0-P4.45 | 2 | TS-1088-AR02016 | XUNPU(讯普) | LCSC | C720477 | 0.056
31 | XL1509-3.3E1 | U3 | SOP-8_L4.9-W3.9-P1.27-LS6.0-BL | 1 | XL1509-3.3E1 | XLSEMI(芯龙) | LCSC | C74193 | 0.298
32 | ESP32-S3-WROOM-1(N16R8) | U4 | WIRELM-SMD_ESP32-S3-WROOM-1 | 1 | ESP32-S3-WROOM-1-N16R8 | ESPRESSIF(乐鑫) | LCSC | C2980300 | 5.664
33 | DB126V-5.0-2P | U6,U10,U11 | CONN-TH_2P-P5.00_L7.8-W10.0 | 3 | DB126V-5.0-2P-GN-P | DORABO(地博电气) | LCSC | C395849 | 0.108
34 | TAS5825MRHBR | U9 | VQFN-32_L5.0-W5.0-P0.50-TL-EP | 1 | TAS5825MRHBR | TI(德州仪器) | LCSC | C471049 | 2.677
35 | TYPE-C 16PIN 2MD(073) | USB1 | USB-C-SMD_TYPE-C-6PIN-2MD-073 | 1 | TYPE-C 16PIN 2MD(073) | SHOU HAN(首韩) | LCSC | C2765186 | 0.074
36 | 17-21SUYC/TR8 | WARN1 | LED0805-R-RD | 1 | KT-0805黄灯 | KENTO | LCSC | C2296 | 0.012

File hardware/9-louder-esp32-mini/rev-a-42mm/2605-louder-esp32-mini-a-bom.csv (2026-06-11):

ID | Name | Designator | Footprint | Quantity | Manufacturer Part | Manufacturer | Supplier | Supplier Part | Price
1 | CBW453215U181T | BEAD2,BEAD4 | L1812 | 2 | CBW453215U181T | FH(风华) | LCSC | C394522 | 0.139
2 | 1uF | C1,C2,C12 | C0402 | 3 | CL05A105KA5NQNC | SAMSUNG(三星) | LCSC | C52923 | 0.005
3 | 10uF | C3 | C0402 | 1 | CL05A106MQ5NUNC | SAMSUNG(三星) | LCSC | C15525 | 0.014
4 | 2.2nF | C4,C27,C29,C30 | C0603 | 4 | 0603B222K500NT | FH(风华) | LCSC | C1604 | 0.004
5 | 100nF | C5,C6,C8,C9,C10,C11,C13,C14 | C0603 | 8 | CC0603KRX7R9BB104 | YAGEO(国巨) | LCSC | C14663 | 0.011
6 | 100uF | C15,C16,C17,C19,C22,C31 | CAP-SMD_L3.5-W2.8 | 6 | TAJB107K006RNJ | AVX | LCSC | C16133 | 0.466
7 | 2.2uF | C20,C24,C34,C35 | C0402 | 4 | CL05A225MQ5NSNC | SAMSUNG(三星) | LCSC | C12530 | 0.006
8 | 22uF | C21,C25,C32,C33 | C0603 | 4 | CL10A226MQ8NRNC | SAMSUNG(三星) | LCSC | C59461 | 0.017
9 | 100nF | C26,C37,C38,C39 | C0402 | 4 | CL05B104KO5NNNC | SAMSUNG | LCSC | C1525 | 0.002
10 | 10uF | C36,C40 | C0805 | 2 | CL21A106KAYNNNE | SAMSUNG | LCSC | C15850 | 0.048
11 | HDGC4001SMD-S-1P | CN1,CN3 | CONN-SMD_HDGC4001SMD-S-1P | 2 | HDGC4001SMD-S-1P | HDGC(华德共创) | LCSC | C5197183 | 0.098
12 | 10kΩ | R1,R7 | R0402 | 2 | 0402WGF1002TCE | UNI-ROYAL(厚声) | LCSC | C25744 | 0.001
13 | 10K | R11,R14 | R0402 | 2 | 0402WGF1002TCE | UniOhm | LCSC | C25744 | 0.001
14 | 75Ω | R21,R22 | R0603 | 2 | 0603WAF750JT5E | UNI-ROYAL(厚声) | LCSC | C4275 | 0.002
15 | 5.1kΩ | R33,R34 | R0402 | 2 | 0402WGF5101TCE | UNI-ROYAL(厚声) | LCSC | C25905 | 0.001
16 | TS-1088-AR02016 | SW1,SW2 | SW-SMD_L3.9-W3.0-P4.45 | 2 | TS-1088-AR02016 | XUNPU(讯普) | LCSC | C720477 | 0.056
17 | TYPE-C 16PLT-H10.0 | U1 | TYPE-C-SMD_USB4120-03-C | 1 | TYPE-C 16PLT-H10.0 | SHOU HAN(首韩) | LCSC | C3151749 | 0.307
18 | TAS5805MPWPR | U2 | HTSSOP-28_L9.7-W4.4-P0.65-LS6.4-BL-EP | 1 | TAS5805MPWPR | Texas Instruments | LCSC | C478472 | 1.376
19 | ESP32-S3-WROOM-1U-N8R8 | U5 | WIRELM-SMD_ESP32-S3-WROOM-1U | 1 | ESP32-S3-WROOM-1U-N8R8 | ESPRESSIF(乐鑫) | LCSC | C2980300 | 5.664
20 | AMS1117-3.3 | U7 | SOT-223-3_L6.5-W3.4-P2.30-LS7.0-BR | 1 | AMS1117-3.3 | AMS | LCSC | C6186 | 0.199

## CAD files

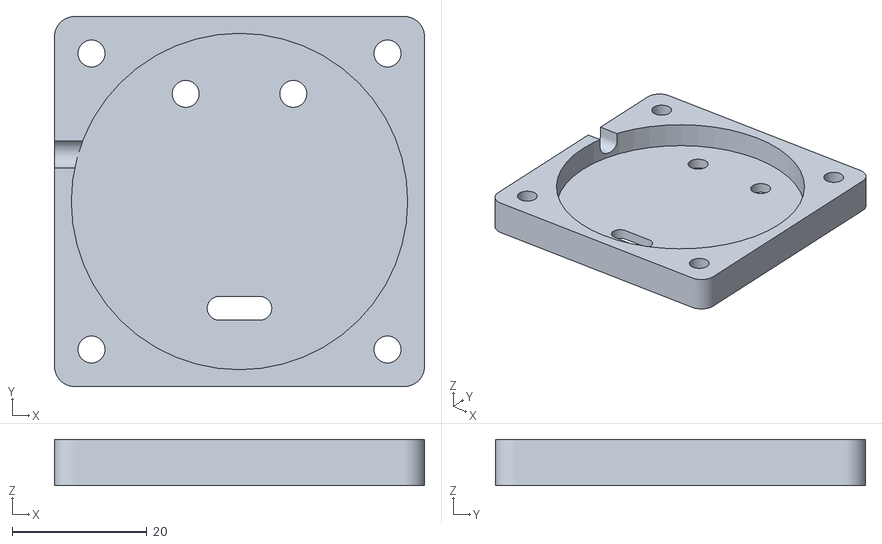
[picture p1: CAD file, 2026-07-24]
hardware/9-louder-esp32-mini/3d/Louder-ESP32-mini-M-shell.stl
55.0 x 55.0 x 6.86

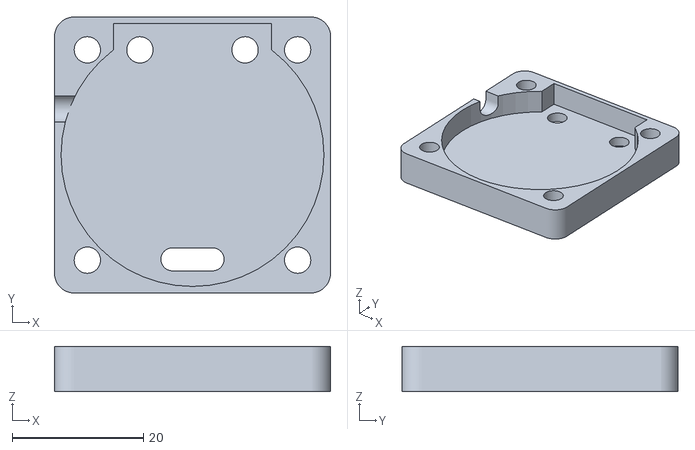
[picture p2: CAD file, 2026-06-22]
hardware/9-louder-esp32-mini/3d/Louder-ESP32-mini-S-shell.stl
42.0 x 42.0 x 6.86

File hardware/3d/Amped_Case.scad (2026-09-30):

$fn=200;

R=10;   //Kantenradius
W=3;    //Wand
HF=35; //Tiefe Oben
HR=55; //Tiefe Unten
X=95; //Breite Gehäuse
Y=70; //Höhe Gehäuse

text1="Amped";
text2="ESP32";



//Menü

part = 5; // [1:Housing, 2:Housing with Terminal 3:Front, 4:Clamp, 5:all]




//###########################################
if (part == 1){
    housing();
    };

if (part == 2){
    difference(){
    housing();
    terminal();
    
    }
    };
    
    
    if (part == 3) {
    rotate([180,0,0]) front();
    
    };
    //}
if (part == 4) {
    clamp();
    };
    
if (part == 5) {
    front();
    translate([0,0,5])clamp();
    translate([0,0,20])housing();
    
    };
   
 
//Gehäuse
module inner_housing(){

    hull(){
        translate([X/2,Y/2,R])sphere(r=R-W);
        translate([X/2,-Y/2,R])sphere(r=R-W);
        translate([-X/2,Y/2,R])sphere(r=R-W);
        translate([-X/2,-Y/2,R])sphere(r=R-W);

        translate([X/2,20,HR])sphere(r=R-W);
        translate([X/2,-Y/2,HF])sphere(r=R-W);
        translate([-X/2,20,HR])sphere(r=R-W);
        translate([-X/2,-Y/2,HF])sphere(r=R-W);
    }

}

module housing_neg() {
    difference(){
        translate([-(X+R*2)/2,-(Y+R*2)/2,+R])
        cube([X+R*2,Y+R*2,max(HF,HR)+R]);
        inner_housing();
    }
}

module display_neg() {
difference(){
    cube([X+R*2+5,Y+R*2+5,12],center=true);
    hull(){
        translate([X/2,Y/2,R])sphere(r=R);
        translate([X/2,-Y/2,R])sphere(r=R);
        translate([-X/2,Y/2,R])sphere(r=R);
        translate([-X/2,-Y/2,R])sphere(r=R);
}
translate([0,0,20])cube([150,150,20],center=true);
}
}

module gehaeuserand(){
translate([0,0,0]){
difference(){
hull(){
translate([X/2,Y/2,R])cylinder(r=R,h=2);
translate([X/2,-Y/2,R])cylinder(r=R,h=2);
translate([-X/2,Y/2,R])cylinder(r=R,h=2);
translate([-X/2,-Y/2,R])cylinder(r=R,h=2);
}


hull(){
translate([X/2,Y/2,R])cylinder(r=R-W/2,h=2);
translate([X/2,-Y/2,R])cylinder(r=R-W/2,h=2);
translate([-X/2,Y/2,R])cylinder(r=R-W/2,h=2);
translate([-X/2,-Y/2,R])cylinder(r=R-W/2,h=2);
}
}
}
}



module housing(){

difference(){
hull(){
translate([X/2,Y/2,R])sphere(r=R);
translate([X/2,-Y/2,R])sphere(r=R);
translate([-X/2,Y/2,R])sphere(r=R);
translate([-X/2,-Y/2,R])sphere(r=R);

translate([X/2,20,HR])sphere(r=R);
translate([X/2,-Y/2,HF])sphere(r=R);
translate([-X/2,20,HR])sphere(r=R);
translate([-X/2,-Y/2,HF])sphere(r=R);
}

inner_housing();

translate([X/2,Y/2,10]) cylinder(d=3.5,h=35);
translate([X/2,-Y/2,10]) cylinder(d=3.5,h=35);
translate([-X/2,Y/2,10]) cylinder(d=3.5,h=35);
translate([-X/2,-Y/2,10]) cylinder(d=3.5,h=35);

translate([X/2,Y/2,15]) cylinder(d=6,h=35);
translate([X/2,-Y/2,15]) cylinder(d=6,h=35);
translate([-X/2,Y/2,15]) cylinder(d=6,h=35);
translate([-X/2,-Y/2,15]) cylinder(d=6,h=35);

//Schnitt
translate([0,0,0])cube([X+50,150,20],center=true);

//Netzteilstecker
translate([40,-19.5,10])rotate([0,90,0])cylinder (d=8.5,h=30);

gehaeuserand();
}


//Führungsrohre für Schrauben
difference(){
union(){
translate([X/2,Y/2,11]) cylinder(d=R+W+2,h=HF+15);
translate([X/2,-Y/2,11]) cylinder(d=R+W+2,h=HF+15);
translate([-X/2,Y/2,11]) cylinder(d=R+W+2,h=HF+15);
translate([-X/2,-Y/2,11]) cylinder(d=R+W+2,h=HF+15);
}
translate([X/2,Y/2,10]) cylinder(d=3.5,h=HF);
translate([X/2,-Y/2,10]) cylinder(d=3.5,h=HF);
translate([-X/2,Y/2,10]) cylinder(d=3.5,h=HF);
translate([-X/2,-Y/2,10]) cylinder(d=3.5,h=HF);




housing_neg();

translate([X/2,Y/2,15]) cylinder(d=6.5,h=35);
translate([X/2,-Y/2,15]) cylinder(d=6.5,h=35);
translate([-X/2,Y/2,15]) cylinder(d=6.5,h=35);
translate([-X/2,-Y/2,15]) cylinder(d=6.5,h=35);

}
}

module terminal(){
translate([5,0,0]){
union(){
//Ausschnitt Lautsprecher-Terminal
translate([-5,5,HR]) rotate([-70,0,0]) cube([51,30, 20],center=true);

//Verschraubung Terminal

translate([25,6.5,HR])rotate([30,0,0])cylinder (d=4,h=100);
translate([-35,6.5,HR])rotate([30,0,0])cylinder (d=4,h=100);
}
}
}



module front(){


translate([8,-4,3])rotate([180,0,0])linear_extrude(4)
    text(text1, font = "Liberation Sans", size = 7);    
    
translate([8,7,3])rotate([180,0,0])linear_extrude(4)
    text(text2, font = "Liberation Sans", size = 7);
//Zylinder für Boardbefestigung



difference(){
union(){
translate([-39,24.5,W])cylinder(d=8,h=12);
translate([19,-24.5,W])cylinder(d=8,h=12);
translate([-39,-24.5,W])cylinder(d=8,h=12);
}

translate([-39,24.5,W])threads(diameter=3, pitch=0.5, length=13, rez=60);
translate([19,-24.5,W])threads(diameter=3, pitch=0.5, length=13, rez=60);
translate([-39,-24.5,W])threads(diameter=3, pitch=0.5, length=13, rez=60);

translate([-36.5,19.5,10])cube([3,10,6]);

}

difference(){
gehaeuserand();
//Netzteilstecker
translate([40,-19.5,10])rotate([0,90,0])cylinder (d=8.5,h=30);
//Displayfront
}
difference(){

hull(){
translate([X/2,Y/2,R])sphere(r=R);
translate([X/2,-Y/2,R])sphere(r=R);
translate([-X/2,Y/2,R])sphere(r=R);
translate([-X/2,-Y/2,R])sphere(r=R);
}

hull(){
translate([X/2,Y/2,R])sphere(r=R-W);
translate([X/2,-Y/2,R])sphere(r=R-W);
translate([-X/2,Y/2,R])sphere(r=R-W);
translate([-X/2,-Y/2,R])sphere(r=R-W);
}


translate([0,0,20])cube([150,150,20],center=true);

//Display
translate([-25,0,-2]) cube([32,16.5, 20],center=true);
translate([-25,-2,6]) cube([35.5,23, 10],center=true);

//Netzteilstecker
translate([40,-19.5,10])rotate([0,90,0])cylinder (d=8.5,h=30);

//IR-Sensor
translate([-18,25,1])cylinder(d=15,h=5);

}



//Rahmen

difference(){
union(){
translate([-50,0,W-0.1])cylinder(d=6,h=4);
translate([0,0,W-0.1])cylinder(d=6,h=4);
translate([-25,14,W-0.1])cylinder(d=6,h=4);
}
translate([-25,0,3]) cube([45.5,26, 2.3],center=true);
display_neg();
}


difference(){
union(){
translate([X/2,Y/2,W/2]) cylinder(d=10,h=8.5);
translate([X/2,-Y/2,W/2]) cylinder(d=10,h=8.5);
translate([-X/2,Y/2,W/2]) cylinder(d=10,h=8);
translate([-X/2,-Y/2,W/2]) cylinder(d=10,h=8);

}



translate([X/2,Y/2,W/2])threads(diameter=3, pitch=0.5, length=13, rez=60);
translate([X/2,-Y/2,W/2])threads(diameter=3, pitch=0.5, length=13, rez=60);
translate([-X/2,Y/2,W/2])threads(diameter=3, pitch=0.5, length=13, rez=60);
translate([-X/2,-Y/2,W/2])threads(diameter=3, pitch=0.5, length=13, rez=60);


}



}


module clamp(){
difference(){
hull(){
translate([-25,0,5]) cube([45,30, 0.1],center=true);
translate([-25,0,6.9]) cube([41,26, 0.1],center=true);
}
translate([-25,0,5]) cube([32,20, 10],center=true);
translate([-25,-5,5]) cube([20,20, 10],center=true);
}
}


module threads(diameter=4,pitch=undef,length=10,scale=1,rez=20){
	pitch = (pitch!=undef) ? pitch : get_coarse_pitch(diameter);
	twist = length/pitch*360;
	depth=pitch*.6;
	linear_extrude(height = length, center = false, convexity = 10, twist = -twist, $fn = rez)
		translate([depth/2, 0, 0]){
			circle(r = scale*diameter/2-depth/2);
		}
}

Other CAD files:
hardware/3d/Louder_Display.scad

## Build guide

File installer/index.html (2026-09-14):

# Flash and provision ESP Audio Dock boards from your browser

No local toolchain, no dashboard - plug the board in over USB and click Install below.

1. Connect
Plug the device into your computer with a USB cable, then click an Install button on the board you have.

2. Provision Wi-Fi
ESPHome images ask for Wi-Fi credentials right in the browser (Improv) during setup - no secrets baked into the firmware. Squeezelite-ESP32 images use the same connect button to set up Improv-serial Wi-Fi on already-flashed devices.

3. Stay updated
ESPHome images check GitHub Pages for new firmware automatically; no need to reflash for future updates.

On Linux you may need to add your user to the dialout group (or adjust permissions on /dev/ttyUSBX) for the browser to see the device. Installing requires Chrome, Edge, or another browser with Web Serial support (https://developer.mozilla.org/en-US/docs/Web/API/Web_Serial_API#browser_compatibility). For Squeezelite-ESP32, the 16-bit build is recommended for most boards - see the readme (https://github.com/sle118/squeezelite-esp32#performances) for details.

### Looking for something else?

AirPlay and standalone Snapcast aren't built from this repo, so they live on their own installer pages - browser-flashable too, just hop over to install them.

##### AirPlay 1 & 2

A standalone AirPlay 1 & 2 receiver from rbouteiller/airplay-esp32 (https://github.com/rbouteiller/airplay-esp32) - appears natively in Control Center with PTP-based multi-room sync. Also bundles the experimental Sendspin renderer and, on classic ESP32 boards, Bluetooth A2DP.

- Supports HiFi-ESP32, Loud-ESP32, Louder-ESP32, Louder-ESP32-Plus, and Amped-ESP32 today (both ESP32 / ESP32-S3)
- Not yet available for HiFi/Amped-ESP32-Plus, Louder-ESP32-mini/Pro, or Loud-ESP32-Plus - see the readme for the current roadmap
- Full 15-band parametric EQ + crossover control on Louder-ESP32 and Louder-ESP32-Plus

Open the AirPlay installer (https://rbouteiller.github.io/airplay-esp32/getting-started/flashing/)

##### Standalone Snapclient

A Snapcast client build maintained by sonocotta/esparagus-snapclient (https://github.com/sonocotta/esparagus-snapclient) (built on CarlosDerSeher/snapclient (https://github.com/CarlosDerSeher/snapclient)) for perfectly synchronized multi-room playback, independent of the ESPHome/Squeezelite builds above.

- Zero configuration - auto-discovers your Snapcast server (Music Assistant, a Raspberry Pi, etc.)
- Available for every ESP32 Audio Dock board
- Pick classic ESP32 over S3 for now - S3 support is still in beta and noticeably laggier

Open the Snapclient installer (https://sonocotta.github.io/esparagus-snapclient/)

###### On this page

Looking for something else?

ESPHome (https://esphome.io/) — Squeezelite-ESP32 (https://github.com/sle118/squeezelite-esp32) — Squeezelite-ESP32 Installer (https://github.com/sle118/squeezelite-esp32-installer) — Installer based on ESP Web Tools (https://esphome.github.io/esp-web-tools/)

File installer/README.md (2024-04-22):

# Esparagus Media Center firmware installer

Web installer for the Esparagus Media Center project

the installer can be used here:
https://sonocotta.github.io/esparagus-media-center/

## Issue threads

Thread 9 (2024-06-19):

Flashing snapclient on Louder ESP rev E error

agdamsbo, 2024-06-19:
Hi. I tried your webflasher to flash snapclient to one of my Louder ESP rev E boards. I get the following error, which sends the board into a rebooting loop:

```
Rebooting...
ets Jul 29 2019 12:21:46

rst:0xc (SW_CPU_RESET),boot:0x13 (SPI_FAST_FLASH_BOOT)
configsip: 0, SPIWP:0xee
clk_drv:0x00,q_drv:0x00,d_drv:0x00,cs0_drv:0x00,hd_drv:0x00,wp_drv:0x00
mode:DIO, clock div:1
load:0x3fff0030,len:7428
load:0x40078000,len:16652
load:0x40080400,len:4
load:0x40080404,len:4284
entry 0x40080668
I (29) boot: ESP-IDF v5.1.1 2nd stage bootloader
I (29) boot: compile time Jun 14 2024 20:30:26
I (29) boot: Multicore bootloader
I (33) boot: chip revision: v3.1
I (37) qio_mode: Enabling default flash chip QIO
I (43) boot.esp32: SPI Speed      : 80MHz
I (47) boot.esp32: SPI Mode       : QIO
I (52) boot.esp32: SPI Flash Size : 4MB
I (56) boot: Enabling RNG early entropy source...
I (62) boot: Partition Table:
I (65) boot: ## Label            Usage          Type ST Offset   Length
I (73) boot:  0 nvs              WiFi data        01 02 00009000 00004000
I (80) boot:  1 otadata          OTA data         01 00 0000d000 00002000
I (88) boot:  2 phy_init         RF data          01 01 0000f000 00001000
I (95) boot:  3 ota_0            OTA app          00 10 00010000 001b0000
I (102) boot:  4 ota_1            OTA app          00 11 001c0000 001b0000
I (110) boot:  5 storage          Unknown data     01 82 00370000 00090000
I (118) boot: End of partition table
I (122) esp_image: segment 0: paddr=00010020 vaddr=3f400020 size=341c8h (213448) map
I (189) esp_image: segment 1: paddr=000441f0 vaddr=3ffb0000 size=03740h ( 14144) load
I (194) esp_image: segment 2: paddr=00047938 vaddr=40080000 size=086e0h ( 34528) load
I (206) esp_image: segment 3: paddr=00050020 vaddr=400d0020 size=cdde0h (843232) map
I (438) esp_image: segment 4: paddr=0011de08 vaddr=400886e0 size=0c6cch ( 50892) load
I (466) boot: Loaded app from partition at offset 0x10000
I (466) boot: Disabling RNG early entropy source...
I (477) cpu_start: Multicore app
I (477) quad_psram: This chip is ESP32-D0WD
I (478) esp_psram: Found 8MB PSRAM device
I (479) esp_psram: Speed: 80MHz
I (483) esp_psram: PSRAM initialized, cache is in low/high (2-core) mode.
W (491) esp_psram: Virtual address not enough for PSRAM, map as much as we can. 4MB is mapped
I (500) cpu_start: Pro cpu up.
I (504) cpu_start: Starting app cpu, entry point is 0x400814f4
I (496) cpu_start: App cpu up.
I (978) esp_psram: SPI SRAM memory test OK
I (986) cpu_start: Pro cpu start user code
I (986) cpu_start: cpu freq: 240000000 Hz
I (986) cpu_start: Application information:
I (989) cpu_start: Project name:     snapclient
I (994) cpu_start: App version:      1
I (998) cpu_start: Compile time:     Jun 14 2024 20:30:59
I (1004) cpu_start: ELF file SHA256:  533ea0f74923bc30...
I (1010) cpu_start: ESP-IDF:          v5.1.1
I (1015) cpu_start: Min chip rev:     v0.0
I (1020) cpu_start: Max chip rev:     v3.99
I (1025) cpu_start: Chip rev:         v3.1
I (1030) heap_init: Initializing. RAM available for dynamic allocation:
I (1037) heap_init: At 3FFAE6E0 len 00001920 (6 KiB): DRAM
I (1043) heap_init: At 3FFB9EF8 len 00026108 (152 KiB): DRAM
I (1050) heap_init: At 3FFE0440 len 00003AE0 (14 KiB): D/IRAM
I (1056) heap_init: At 3FFE4350 len 0001BCB0 (111 KiB): D/IRAM
I (1063) heap_init: At 40094DAC len 0000B254 (44 KiB): IRAM
I (1069) esp_psram: Adding pool of 4096K of PSRAM memory to heap allocator
I (1077) spi_flash: detected chip: generic
I (1081) spi_flash: flash io: qio
I (1086) app_start: Starting scheduler on CPU0
I (1090) app_start: Starting scheduler on CPU1
I (1090) main_task: Started on CPU0
I (1100) esp_psram: Reserving pool of 32K of internal memory for DMA/internal allocations
I (1108) main_task: Calling app_main()
I (1123) SC: Start codec chip
I (1123) HAL: INIT
W (1123) TAS5805M: Power down pin: 33
W (1144) TAS5805M: Setting to HI Z
E (1144) TAS5805M: Fehler bei der I2C-Übertragung: ESP_FAIL
ESP_ERROR_CHECK failed: esp_err_t 0xffffffff (ESP_FAIL) at 0x40104189
file: "./components/custom_board/tas5805m/tas5805m.c" line 162
func: tas5805m_init
expression: tas5805m_write_byte(TAS5805M_DEVICE_CTRL_2_REGISTER, 0x02)

abort() was called at PC 0x4008d30f on core 0

Backtrace: 0x40081dd9:0x3ffbb5e0 0x4008d319:0x3ffbb600 0x40091689:0x3ffbb620 0x4008d30f:0x3ffbb690 0x40104189:0x3ffbb6c0 0x401042cc:0x3ffbb700 0x40103d7d:0x3ffbb730 0x40103e30:0x3ffbb780 0x400da95a:0x3ffbb7b0 0x40199a5e:0x3ffbb810

ELF file SHA256: 533ea0f74923bc30

Rebooting...
ets Jul 29 2019 12:21:46
```

anabolyc, 2024-06-19:
Hey @agdamsbo Can you please attach a photo of your setup. Looks like I2C communication fails for some reason.

agdamsbo, 2024-06-19:
I have the espboard attached to the carrier ESP louder board, microusb from espboard to my computer (macos). I will try again with a different computer maybe if you think its just a communications thing.

anabolyc, 2024-06-19:
It is a communication between module and the DAC that is failing, that's why I'd like to see an actual photo to verify it everything is correct

agdamsbo, 2024-06-19:
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

anabolyc, 2024-06-19:
@agdamsbo in the Revision E DAC cannot pull power from USB (Few customers reported earlier that it blows power circuit on the module). Therefore you need to connect power source to the DAC using barrel jack or screw terminals, keeping USB power for flashing and debugging. Right now your DAC is not powered, as indicated by LED near the barrel jack.

Staring Rev H, USB can power DAC as well, since I changed ESP32-mini for ESP32-WROVER module.

agdamsbo, 2024-07-01:
Hi. So now I finally have a little time on hand to revisit this issue. I've had a look at my board again. There is one capacitor (I assume) that looks to be shortening the connection on the mini32 (red circle). And there is another capacitor (again, just my assumption) on the DAC, that is not properly soldered to the pad (yellow circle). I have just marked on the same photo, as uploaded previously. I assume these might be issues (especially on the DAC), that might cause the bad reception I have experienced? Thank you in advance.
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

anabolyc, 2024-07-01:
Hey @agdamsbo good catch! DAC capacitor is just one out of many filtering power, so it should not cause malfunction. If it were shorted, it would cut out power altogether, so probably it is not soldered. You may solder it back in, if you have soldering iron, or just leave it as it is.

As for the module itself, it is hard to say what it is doing, but I assume it is filtering power. It can affect the network, although that would be quite exotic I'd say. Again, if you have a soldering iron, I'd advise to attempt solder it back in, or remove it altogether and see if it helps. Not much to lose anyway :)

Closed 2024-12-17.

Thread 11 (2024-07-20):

louder esp snapcast audio

developsad, 2024-07-20:
Hi. I installed snapcast on my louder esp.
Its working but there is some strange audio behavior.
It sounds like floating sound or lossy samle rate. I can hear it mainly on hights where they are clear and then they become dull. I tried with dsp, without dsp.
The board is ok because when i had the squeezelite installed there was no such behavior

anabolyc, 2024-07-23:
Hey @developsad . I'm checking with upstream developers if that's a known issue or perhaps something that is a work in progress. So far I didn't witness myself this behavior, so I'm not sure what it is caused by

anabolyc, 2024-07-25:
Fixed by #12

Closed 2024-07-25.

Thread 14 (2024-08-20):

boot_comm: mismatch chip ID, expected 9, found 0 -- when ota louderesp32

olivervhansen, 2024-08-20:
I'll admit I'm a little unsure of which device I have but it was a recent purchase so I believe rev J of the WROOM (that's what the chip says on the board).

I'm installing ESPHome from Home Assistant when I get this error. I can get the base install of ESPHome from web.esphome.io to install and even get it into Home Assistant after but when I try to update the config to  [https://github.com/sonocotta/esp32-audio-dock/blob/main/firmware/esphome/louder-esp32-media-player.yaml](https://github.com/sonocotta/esp32-audio-dock/blob/main/firmware/esphome/louder-esp32-media-player.yaml) I get the error in the subject.

```[20:33:17][D][esphome.ota:293]: Progress: 78.2%
[20:33:18][D][esphome.ota:293]: Progress: 90.5%
[20:33:19][D][esphome.ota:293]: Progress: 98.1%
[20:33:20][D][esp-idf:000]: E (2370958) boot_comm: mismatch chip ID, expected 9, found 0

[20:33:20][E][ota.arduino_esp32:052]: End error: 9
[20:33:20][W][esphome.ota:309]: Error ending update! error_code: 132
[20:33:20][E][component:164]: Component esphome.ota set Error flag: unspecified
[20:33:20][W][component:237]: Component esphome.ota took a long time for an operation (9670 ms).
[20:33:20][W][component:238]: Components should block for at most 30 ms.
[20:33:25][E][component:176]: Component esphome.ota cleared Error flag
```
I've been trying lots of things but this is the latest config I'm using that fails. I'm guessing it's probably something simple. Searching this specific error gives me results about encryption so I've tried installing without it.

```
substitutions:
  name: "louder-esp32"
  friendly_name: Louder-ESP32 Media Player
  pcb_version: "J"

esphome:
  name: "${name}"
  name_add_mac_suffix: false
  comment: "${friendly_name} Louder ESP32 ${pcb_version}"
  includes:
    - louderesp32.h
  platformio_options:
    lib_deps: "Wire"
  on_boot:
    priority: 800
    then:
    ## Set a volume limit just to be safe...
    - media_player.volume_set:
        id: louderesp32
        volume: 20%

esp32:
  board: mhetesp32minikit
  #framework:
    #type: arduino

### Optional if you want ethernet (then remove all wifi config) ###
#ethernet:
#  type: W5500
#  clk_pin: GPIO18
#  mosi_pin: GPIO23
#  miso_pin: GPIO19
#  cs_pin: GPIO05
#  interrupt_pin: GPIO35
#  reset_pin: GPIO14

# Enable logging
logger:
  level: DEBUG

# Enable Home Assistant API
api:
    #encryption:
      #key: !secret esphome_api_key

# Allow Over-The-Air updates
ota:
  - platform: esphome

wifi:
  ssid: !secret wifi_ssid
  password: !secret wifi_password
  domain: !secret wifi_domain
  ap:
    ssid: "$name Hotspot"
    password: "squeezebox"

captive_portal:

psram:
  mode: octal
  speed: 80MHz

switch:
  - platform: custom
    lambda: |-
      auto tas5805 = new TAS5805();
      App.register_component(tas5805);
      return {tas5805};
    switches:
      name: "Enable Amp"

i2c:
  sda: GPIO21
  scl: GPIO27
  scan: True
  id: i2c_component

i2s_audio:
  i2s_lrclk_pin: GPIO25
  i2s_bclk_pin: GPIO26

media_player:
  - platform: i2s_audio
    name: $friendly_name
    id: louderesp32
    dac_type: external
    i2s_dout_pin: GPIO22
    mode: stereo
```

anabolyc, 2024-08-20:
Hey @olivervhansen

Rev J is an ESP32-S3 board, this config is for the regular ESP32. Two things need to be changed: the board and the pinout.
You can find pinout [here](https://github.com/sonocotta/esp32-audio-dock/tree/main#louder-esp) and board should be `esp32-s3-devkitc-1` afaik.

Pls give it a try, and I can add updated config to the repo

olivervhansen, 2024-08-20:
Thanks @anabolyc ! Those were the pieces of information I didn't have. I had a config in HA that worked using that board but then it gave me errors about the pins and because I didn't know much about the pins I figured that file in the repo must be correct.

I added the encryption back in after one successful flash and this is what I currently have working. It loads but I don't have my speakers yet to test it fully.

One other question: is **pcb_version** supposed to be defined elsewhere? I added it to substitutions but initially thought it should be pulled in from something that detects the version.

```
substitutions:
  name: "louder-esp32"
  friendly_name: Louder-ESP32 Media Player
  pcb_version: "J"

esphome:
  name: "${name}"
  name_add_mac_suffix: false
  comment: "${friendly_name} Louder ESP32 ${pcb_version}"
  includes:
    - louderesp32.h
  platformio_options:
    lib_deps: "Wire"
  on_boot:
    priority: 800
    then:
    ## Set a volume limit just to be safe...
    - media_player.volume_set:
        id: louderesp32
        volume: 20%

esp32:
  board: esp32-s3-devkitc-1

### Optional if you want ethernet (then remove all wifi config) ###
#ethernet:
#  type: W5500
#  clk_pin: GPIO18
#  mosi_pin: GPIO23
#  miso_pin: GPIO19
#  cs_pin: GPIO05
#  interrupt_pin: GPIO35
#  reset_pin: GPIO14

# Enable logging
logger:
  level: DEBUG

# Enable Home Assistant API
api:
    encryption:
      key: !secret esphome_api_key

# Allow Over-The-Air updates
ota:
  - platform: esphome

wifi:
  ssid: !secret wifi_ssid
  password: !secret wifi_password
  domain: !secret wifi_domain
  ap:
    ssid: "$name Hotspot"
    password: "squeezebox"

captive_portal:

psram:
  mode: octal
  speed: 80MHz

switch:
  - platform: custom
    lambda: |-
      auto tas5805 = new TAS5805();
      App.register_component(tas5805);
      return {tas5805};
    switches:
      name: "Enable Amp"

i2c:
  sda: GPIO8
  scl: GPIO9
  scan: True
  id: i2c_component

i2s_audio:
  i2s_lrclk_pin: GPIO15
  i2s_bclk_pin: GPIO14

media_player:
  - platform: i2s_audio
    name: $friendly_name
    id: louderesp32
    dac_type: external
    i2s_dout_pin: GPIO16
    mode: stereo
```

anabolyc, 2024-08-20:
**pcb_version** is completely optional. It is just a handy way to remind the board it was tested with.

olivervhansen, 2024-08-21:
So this config works to flash the device but I'm not getting expected behavior in HA. If I manually turn on the "Enable Amp" switch  under ESPHome it changes back to off. If I do it again it stays on for a while but then seems to automatically turn off. I can try to play media with it on or off and nothing happens. I've tried from Music Assistant and also just sending a TTS command from a local piper engine. I connected one passive speaker I had for testing to the left channel only and nothing.

A portion of the logs
```
Louder-ESP32 Media Player changed to Idle Media player: Play media
5:11:31 PM - 15 hours ago - Supervisor
Enable Amp turned off
5:11:31 PM - 15 hours ago
Enable Amp became unavailable
5:11:31 PM - 15 hours ago
Louder-ESP32 Media Player became unavailable Media player: Play media
5:11:31 PM - 15 hours ago - Supervisor
Enable Amp turned on Switch: Turn on
5:10:32 PM - 15 hours ago - Admin
```

anabolyc, 2024-08-21:
Can you please enable DEBUG level of logging on the ESPHome and attach the logs from the louder boards when you switch the amp on

olivervhansen, 2024-08-21:
Thanks for the suggestion! I wasn't sure how to enable debug but once I did I could see what was going on. My HA is on a different VLAN than the media players and this one hadn't yet been added to the list of devices that could initiate traffic to the HA. So HA could reach out to Louder-ESP32-S3 but Louder couldn't initiate a session or grab the audio file generated on the HA for the TTS.

Fixed that and now I've got sound coming out to my test speaker now so I think it's functioning properly now.

anabolyc, 2024-08-22:
Thanks for letting me know. I added S3 config to the repo to make it easier next time.

Closed 2024-08-22.

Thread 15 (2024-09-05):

Speaker Connection for Mono/PTBL mode

flix-one, 2024-09-05:
Is it possible that the images for the speaker connection are switched accidently between BTL and PBTL modes?
The schematics and rated power fit together but the speaker connection images are showing the opposite of the schematics?

https://github.com/sonocotta/esp32-audio-dock#btl-and-pbtl-mode

To use the Louder ESP32 rev. H with one speaker, I need to solder the mono header together horizontally and then connect OutA+ and OutA- to Speaker + and Out B+ and OutB- to Speaker - (As shown in schematic for PTBL but image for BTL)
Is that correct?

anabolyc, 2024-09-05:
Hey @flix-one you're right, thanks for reporting. I've updated the description, and also added a sentence about the software side of that.

flix-cas, 2024-09-10:
Just a quick clarification for the PTBL mode.
When I solder the mono header together, is it sufficient to connect the Speaker+ to **either** OutA+ **or** OutA- ?
Or do I have to bridge the OutA+ and OutA- together before connecting Speaker+ as in your [picture](https://github.com/sonocotta/esp32-audio-dock/assets/5459747/eca2cf1e-ebe0-4684-9aa2-1cc193e0982f)?

anabolyc, 2024-09-10:
> Just a quick clarification for the PTBL mode. When I solder the mono header together, is it sufficient to connect the Speaker+ to **either** OutA+ **or** OutA- ? Or do I have to bridge the OutA+ and OutA- together before connecting Speaker+ as in your [picture](https://github.com/sonocotta/esp32-audio-dock/assets/5459747/eca2cf1e-ebe0-4684-9aa2-1cc193e0982f)?

Correct, you can use either, they are bridged together

flix-one, 2024-09-10:
Sorry wrong account, but thank you for the super fast reply :-)

Closed 2024-09-05.

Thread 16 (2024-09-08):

Add rotary encoder to Louder ESP32 (rev H)

flix-one, 2024-09-08:
I really love the Louder ESP32, it works really well.
I would like to add a rotary encoder to add the possibility to change volume directly at the speaker.

Could you give some information how this is done easiest?
I've seen some GPIOs available on the PCB of my rev H (2, 4, 13, 15, 32, 36, 3V3, GND).
Can I use all of them or are some of them better suited for the rotary encoder?
I suppose the programming needs to be done via the I2C or SPI Bus Parameters in the Hardware Section of Squeezelite-ESP32?

I have some KY-040 available here, but it seems they're working with 5V?
https://www.az-delivery.de/en/products/drehimpulsgeber-modul
"GND"
"+" = 5V
"SW" = Interrupt for Push-Button
"DT" = Encoder Pin B
"CLK" = Encoder Pin A

If they're not suited, could you give me a suggestion which ones are better suited?

Thanks in advance, maybe this could also be added to the readme?

anabolyc, 2024-09-08:
Hey @flix-one

First of all, rotaries are not active devices, they are basically switch whatever voltage you feed in, like basic buttons. Please use 3.3V as power and you'll get good reliable 3.3v on all signal lines.

You can use pretty much any pins that are available with [some limitations](https://randomnerdtutorials.com/esp32-pinout-reference-gpios/). In your list avoid pin 2 (bootstrapping pin), the rest should be good to go.

Last point, here is the [squeezelite](https://github.com/sle118/squeezelite-esp32?tab=readme-ov-file#rotary-encoder) docs on how to configure rotary encoder as soon as you have it connected.

flix-one, 2024-09-08:
Thank you for the feedback, I think of using
SW = GPIO 4
CLK (Pin A) = GPIO 13
DT (Pin B) = GPIO 32

In the Pinout Reference it says:

```Note: ADC2 pins cannot be used when Wi-Fi is used. So, if you’re using Wi-Fi and you’re having trouble getting the value from an ADC2 GPIO, you may consider using an ADC1 GPIO instead. That should solve your problem.```

Are the ADC2 pins (0, 2, **4**, 12, **13**, 14, 15, 25, 26, 27) used for Wi-Fi by your PCB configuration (especially 4 and 13)?

anabolyc, 2024-09-08:
As far as I know, this warning only applies if you're using ADC, or `analogRead`. For digital functions it is fully functional.

flix-one, 2024-09-09:
With SW on GPIO 4, DT (A) on GPIO 32 and CLK (B) on GPIO 13 it works with rotary_config: ```A=32,B=13,SW=4,volume,longpress```

Thank you for the support!

anabolyc, 2024-09-09:
You're very welcome. Feel free to attach a pic of the end result, if it is all right :)

flix-one, 2024-09-10:
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

Closed 2024-09-09.

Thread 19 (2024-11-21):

[Idea] Power Supply via PoE

flix-one, 2024-11-21:
Hi,

I was asking myself if it would be possible to use the Ethernet connection to supply the Louder-ESP32 with power via PoE connection.

One problem is probably the voltage level of 48V that has to be reduced to the 12-18V of the ESP32?
I found the TI TPS23730 that can convert DC-DC from PoE
https://www.ti.com/product/TPS23730

Then you would probably have to redesign the PCB to first extract the power supply from the Ethernet cable and then go through the Ethernet module to connect the data stream?

It's just an idea, but the benefit would be to supply a speaker with data and power by only one ethernet cable and have wired connection. This could be beneficial in case WiFi coverage is bad at the destined location of the speaker.

Greetings,
Fabian

anabolyc, 2024-11-21:
Hey @flix-one

A few more people reached out to me with a similar request. I'm not against it, but I would set my expectations low for a few reasons
- PoE appliance can deliver 50W only, which could not be enough for the DAC
- Power quality on the PoE line is far from audio grade, the D-class amp will push all the noises directly to the speakers
- Long power lines together with high-speed digital lines don't sound good for audio either

With that said I'm not against it and I'm planning to do a prototype at some point. For now, I'd need to investigate how the PoE works, and what should be done on the ESP side to negotiate voltage and drop it down to 3.3V (I guess it is similar to USB-PD?). I also need to find some PoE appliances for testing, since I don't have them to start with :)

bitte-ein-bit, 2025-01-16:
For a start, you can use POE splitters. They receive POE+DATA and split that into DATA (RJ45) and Power (usb, barrel, open ends). The voltage depends on the splitter chosen.

To power it a simple POE injector might be sufficient.

One item to be aware of are the two flavors: active and passive POE. Passive always gets power (various voltages), active has to negotiate first but is always 48V (to my knowledge)

Closed 2025-04-09.

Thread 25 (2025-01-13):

Local Playback (LMS) is too loud. Device crashes

haldi4803, 2025-01-13:
Howdy,

I've bought two Louder-ESP32 v2 boards after the one in my showerroom broke down. Maybe i should think about waterproof coating.... it gets steamy in there...
using the 20V 65W and 19V 90W it works out of the box, compared to the old version. But i had the same Problem as on the old board, when playing via LMS and local Files (NAS) getting over 90% Volume the device suddenly becomes mute while LMS continues the music. Only way to get it back to output sound is by turning the device off and then starting playback again. The track will begin from 0:00.
I realized that this is only happening when i use Local Tracks via LMS. Bluetooth input is way quieter and even playing a track from Tidal via LMS is less loud.

The only setting for something similar i could find was the player Setting "Default Adjustment for Remote Streams" which is at -5
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

But that should not have any influence on Bluetooth right?

Do you think i don't have enough power? Should i try a 26V PSU?
Speakers are 6 Ohm 100W/60W Denon S 420 Surround. because they are really small, still loud, and have decent quality (for their size)

Or do you know any LMS settings that i'm missing?
I think last time i solved this issue by changing the amp gain at boot with I2C commands. But that would also reduce Bluetooth volume.

anabolyc, 2025-01-13:
Hey @haldi4803.

With the mute issue first that comes to mind, at maximum volume the DAC might be overheating, it depends on outside temperature and fresh air access. Can you please check that (this can be fixed by attaching a small heatsink at the back side of the DAC, it is designed to push the head on the board). Alternatively, it is recommended to switch modulation at a voltage above 12v, I can help you configure that as well).

Sorry I'm not an LMS expert, I'd advise you to ask at [LMS forums](https://forums.slimdevices.com/). But if you change the hardware volume at startup it will definitely affect all audio sources equally.

haldi4803, 2025-01-14:
> this can be fixed by attaching a small heatsink at the back side of the DAC, it is designed to push the head on the board)

You mean not on top of the DAC but bottom side in the PCB?
Will test this evening.

anabolyc, 2025-01-14:
Correct, bottom of the PCB. DAC has the power pad on the bottom and grid of vias to pass it on the back side of the board

haldi4803, 2025-01-14:
i doubt that's the issue... barely 50°C hot.
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

Tried with my hairdried on Cold mode (which has huricane level windspeeds) to prevent it from overheating. No difference.
Volume 80 works fine without any issue.
As soon as i go 100 it takes about 5-10 seconds and silences.
I can continue Playback with Volume 80 After shuting it down and starting again

Took a Telnet Log with sDebug.
Maybe something is written there?
https://pastebin.com/KyL8UEGz

But i guess @Sle118 would me more avid in reading those right?

anabolyc, 2025-01-15:
Thanks for the comprehensive feedback. Since it is working most of the time, I'm not sure guys from squeezelite-esp32 would consider it software related.

Also temperature doesn't look like anything remotely dangerous, it should safely go up to 100C. If you get it right, with heatsink or without, it is the same?

I think it is related to relatively high voltage. If you have something under 20V, give it a try. Otherwise I'd propose to try this:

> In section “2.3 Modulation Mode Selection”:
Figure 11 shows PVDD, which is an important factor for thermal design. The efficiency of TAS5805M
decreases with the increase of PVDD. When PVDD > 19 V, use 1SPW rather than BD, considering the
efficiency.

In summary, the efficiency of 1SPW is higher than BD mode and it is suggested you choose
1SPW mode in large output condition. In addition, a larger load means better efficiency

If you want to trigger Hybrid mode (to see if that helps), it is fairly straightforward in the nvs settings:
dac_controlset: {"init":[{"reg":3,"val":2},{"reg":3,"val":3},{"reg":2,"val":2}],"poweron":[{"reg":3,"val":3}],"poweroff":[{"reg":3,"val":0}]}

Change to {"reg":2,"val":1} for 1SPW mode, see if it is any good. If possible please take temperature measurements along the way.

haldi4803, 2025-01-15:
> Change to `{"reg":2,"val":1}` for 1SPW mode

Just quickly tested it on the 19V 65W PSU And it still crashed.
I bought a 24V 5A Meanwell PDU that should be "good" quality...
Will test on that later this week.

haldi4803, 2025-01-16:
Also happening on 24V.
IMHO even faster than on 20V... so might not really be a problem with the current but more of a voltage regulation overload ?
Sadly i don't think i have any 12V PSU lying around that does more than 1A...

anabolyc, 2025-01-18:
> Also happening on 24V. IMHO even faster than on 20V... so might not really be a problem with the current but more of a voltage regulation overload ? Sadly i don't think i have any 12V PSU lying around that does more than 1A...

I'll try to find a higher voltage PSU and try to reproduce it. I tried it with 19V and at a very high volume I think I experienced something similar. But it recovered itself after less than a minute.

haldi4803, 2025-01-18:
Its happening with bass heavy music. And only on the parts where there is a lot of bass... That's why I assume it's a power issue.

This was my testing tune.
https://youtu.be/pa8i4sNzL_g?si=hN0boCkJgwEnxT7z

koriwi, 2025-02-19:
Do we have any updates here? I experienced the same. Right now it is not really a problem, as it happens at a volume which i almost never listen to, but it would still be good to fix or work around it.

anabolyc, 2025-02-19:
I'm working to bring DSP settings to the ESP32 platform, I want to play with different modulation settings to figure out what causing the high power consumption. Also, I'll port more detailed fault logging, maybe it will spit out something useful.

I can confirm that even on low volume it can get quite hot all of a sudden, yet I don't understand why. Need to do some testing with different DAC settings

elektrinis, 2025-03-05:
This happened to me as well, a couple of times, on louder-esp32s3. Within one second when volume is increased, so likely not heat related.
I also had issues with LMS itself - audio stopped playing after I went through several radio stations. Had to restart LMS.
A separate problem: I think the DAC really needs a heatsink. I have only one speaker connected, and it becomes too hot to touch at higher volume (19V psu). I think it may overheat in stereo configuration.

anabolyc, 2025-03-06:
Give me some time, I'm implementing detailed fault reading from the DAC as long as few other settings that I want to test together with higher power voltage. What I know that this DAC behaved differently when powered with more than 12V, and probably require register tunings. I'm not there yet to define the right settings.

elektrinis, 2025-03-08:
Happened a few more times (at 80% volume). Just to confirm, it's enough to reboot the player via web interface for function to resume, it's not necessary to remove power.

anabolyc, 2025-03-08:
Good sign, probably something that can be fixed via software. @elektrinis what voltage power source are you using?

elektrinis, 2025-03-08:
> Good sign, probably something that can be fixed via software. [@elektrinis](https://github.com/elektrinis) what voltage power source are you using?

19V laptop brick.

haldi4803, 2025-03-08:
> Happened a few more times (at 80% volume).

Okay, thats low... mostly happens around 93-96% Volume in my case. 90% was safe all time.

koriwi, 2025-03-09:
> I'm working to bring DSP settings to the ESP32 platform, I want to play with different modulation settings to figure out what causing the high power consumption. Also, I'll port more detailed fault logging, maybe it will spit out something useful.
>
> I can confirm that even on low volume it can get quite hot all of a sudden, yet I don't understand why. Need to do some testing with different DAC settings

Awesome. I backed off from working on the dsp settings for the DAC in the esp-louder and started working on a standalone DSP with the esp32 which works with i2s input/output directly because i also have a subwoofer which does not use an esp-louder but discrete boards. I know its offtopic, but just wanted to let you know why I havent looked into it yet. :)

elektrinis, 2025-05-21:
Any news on the fix?
It's a cool product, I'm using it every day. Just need these small fixes.

anabolyc, 2025-05-21:
Hey @elektrinis, I haven't run detailed power tests yet. For now, I'd advise reducing analog gain view dBs to limit output driver voltage swing. It can be done via an updated startup sequence, which should include
```
{"reg": 124, "val": XX}
```

`XX` should be something between 0 and 32, I'd recommend increasing it until it gets stable enough.

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

anabolyc, 2025-08-24:
Hey folks. I found some time (finally) to run some power tests. I've placed the results [here](https://github.com/sonocotta/esp32-tas5805m-dac#power-measurements-on-louder-esp32-board), [here](https://github.com/sonocotta/esp32-tas5805m-dac#power-consumption-testing) and [here](https://github.com/sonocotta/esp32-audio-dock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)

Results that I gathered:
- Switching frequency and BD-frequency have little to no effect on the efficiency.
- 1SPW modulation mode is more efficient (for the cost of some THD degradation), but it is only worth using under higher VCC. I recommend setting it up if you're on 15V or more
- Bare naked DAC on the Louder-ESP32 can only sustain long-term operation at full power VCC=15V (BD-mode) and VCC=16V (1SPW mode). Above that, it needs passive or active cooling.
- In case you want to stay passive and use voltage above 16V, you need to tune down the analog gain to limit output power (if stability is a priority)
- Another solution, as soon as DAC reports OT warning - lower the volume slowly using automation until it disappears. In my tests, between OT warning and OT shutdown, you have around 10 seconds for that. With passive cooling more, clearly.

elektrinis, 2025-08-25:
Wait. So do we know for certain that overtemperature is the reason for this crash? In such case, a small heatsink should help.
In my case it crashed within one second of loud audio, should be not enough time to overheat.
Also how can we handle this crash, reset DAC automatically?

anabolyc, 2025-08-25:
@elektrinis yes, that's what I witnessed. A small heatsink adds thermal inertia, so you have a little more time to read faults and lower the volume, but with an excess of 3-5W heat on this small board, you won't get away that easily. Active cooling will be required for long-term stability.

If you have this issue with your board, I'd ask you to try it out
- reading faults when shutdown happens
- lower analog gain and see how it changes
- lower VCC and see if that helps

All can be done with esphome firmware

anabolyc, 2025-08-25:
@haldi4803

jdegenstein, 2025-08-26:
I just want to add that I am also seeing this issue but with a slightly different device -- a Seeed XIAO ESP32S3 wired point-to-point with a PCM5102a DAC dev board. This setup is powered solely via USB. I am considering trying to add a relatively large electrolytic to see if it helps.

When my device crashes it becomes unreachable over wifi.

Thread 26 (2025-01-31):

Louder-ESP32 (WROVER) keeps switching to Recovery Mode

mo-g, 2025-01-31:
Hi there,

I have four of these boards running now, connected by Ethernet, running squeezelite-esp32 (your build) with LMS and I keep finding them reverted to "Recovery Mode" if I leave them alone for a few hours, which means going to the device, connecting to it's WiFi network (because ethernet doesn't work in Recovery) and hitting "Exit Recovery", and then it's good for a while. I come back the evening, or maybe the next day, and one or more of the devices is back in Recovery.

Power supplies are DC jack, 12V, high wattage - and they crash on idle, not mid-use.

Can you advise me at all on how to debug these?

best,
Mog.

anabolyc, 2025-01-31:
Hey @mo-g
Thanks for reporting this. Can you check if the same happens on Wifi? Just to make sure if it has any connection to the Ethernet.
The first step would be to attach a serial logger and see if there Is anything in the logs prior to the recovery reboot. I'm not an expert on squeezelite-esp32, but I do know it will reboot in certain conditions automatically. I don't remember it ever rebooting to **recovery** by its own, but there might be a case where it would do so.
Alternatively, you may ask (or search) in the [squeezelite-esp32](https://github.com/sle118/squeezelite-esp32/issues) repo, folks there should know better.

Closed 2025-04-09.

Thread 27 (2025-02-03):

Please confirm changes necessary for MONO

frdfsnlght, 2025-02-03:
I've just received my Louder-ESP order (2 units, Rev H2, pre-flashed with SqueezeLite-ESP32). I've hooked one of them up in standard stereo mode and it works perfectly as expected. I want to hookup the second unit for MONO operation but want to confirm a few things:

1) I need to bridge the two pairs of connectors between the speaker terminals horizontally.
2) I need to change the dac_controlset NVS parameter to:

`{"init":[{"reg":3,"val":2},{"reg":3,"val":3},{"reg":2,"val":4}],"poweron":[{"reg":3,"val":3}],"poweroff":[{"reg":3,"val":0}]}
`

3) Connect a single speaker between the 2 output terminals.

Assuming I have those items correct, I have some questions:

Q1) I assume with the connectors bridged (item 1), I don't need to create a 'Y' connection between the +/- terminals on each speaker output?
Q2) Which channel will be output to the speaker? Just the left, or just the right? Can it be changed?
Q3) Assuming the previous answer is a single channel (L or R), Is it yet possible to get a true mono (L+R)/2 output? I know all about the difficulty getting programming info for the TI DAC, but have you had any success in that regard?

Thanks for help!

anabolyc, 2025-02-03:
Hey @frdfsnlght
The steps look right.
Q1)  Correct, you'll effectively connect them together with those jumper bridges. Or vice versa, connect both terminal outputs to the speaker and you may omit the jumper bridges.
Q2) It will output a single channel (can't remember which one).
Q3) Yes, it can be fixed with input mixer adjustments, but that's a considerably longer command set, and I need to test it first. I'm working currently to implement DSP settings for this DAC on the esp32 and this is one of those features I want to bring. I've made it work with Raspberry driver, but the esp32 implementation is still a work in progress.

anabolyc, 2025-02-04:
Here it is (not tested)

```
#define REG_PAGE_SET 0x00
#define REG_BOOK_SET 0x7f
```

```
    { REG_PAGE_SET, 0x00 },
    { REG_BOOK_SET, 0x8c },
    { REG_PAGE_SET, 0x29 },
    { 0x18, 0x00 }, //  Input Mixer Left to left = -6 dB
    { 0x19, 0x40 },
    { 0x1a, 0x26 },
    { 0x1b, 0xe7 },
    { 0x1c, 0x00 }, //  Input Mixer Right to left = -6 dB
    { 0x1d, 0x40 },
    { 0x1e, 0x26 },
    { 0x1f, 0xe7 },
    { 0x20, 0x00 }, //  Input Mixer Left to right = -110 dB
    { 0x21, 0x00 },
    { 0x22, 0x00 },
    { 0x23, 0x00 },
    { 0x24, 0x00 }, //  Input Mixer Right to right = -110 dB
    { 0x25, 0x00 },
    { 0x26, 0x00 },
    { 0x27, 0x00 },
    { REG_PAGE_SET, 0x00 },
    { REG_BOOK_SET, 0x00 },
```

frdfsnlght, 2025-02-04:
Excellent!

Based on what you've provided, it appears that when MONO mode (PBTL) is enabled, the DAC is only using the left input channel and ignoring the right?

If I wanted to just send the left channel at 0dB, would I use a value like (0x00 0x43 0xda 0x60 (4446816 decimal) for registers 0x18 to 0x1b, and 0x00 for the other 3 input mixer sections?

And likewise if I wanted to just send the right channel, I'd use those same values for registers 0x1c to 0x1f, and 0x00 for the other 3 input mixer sections?

And I assume before setting the input mixer registers, I should include the other register settings already in the "init" section of the existing dac_controlset value?

Assuming my assumptions are correct, I'll try this out later tonight. If my testing works as I hope it will, I'll post the final dac_controlset values here.

My ultimate plan is to use 2 of the Louder-ESP units as a stereo pair with each configured for PBTL mono, and one configured to output only left and the other only right. If that doesn't work out well, I'll just send a mono mix (L+R)/2 to both of them.

Thanks for the help so far!

frdfsnlght, 2025-02-04:
I've had a chance to play with this. The first problem I ran into is that the terminals on the board are mislabeled: left and right are swapped. Playing a test file ([like this one](https://www.aoakley.com/articles/2018-08-24-stereo-test.php)) confirms this.

The next problem I ran into was that it seems the comments in the code snippet you provided are a little wrong. My testing shows register at 0x18 (and the 3 following) are for mixing the left input to the RIGHT output, register 0x1c is for mixing the right input to the RIGHT output, register 0x20 mixes left input to LEFT output, and register 0x24 mixes right input to LEFT output. And when I say LEFT or RIGHT output, I mean AFTER swapping the left/right terminal labels.

This gets confusing fast.

Taking all this into account (speakers swapped and my observations about the registers), the test file plays as you'd expect with the default dac_controlset.

Then I tested these:

**Stereo speakers (BTL mode), mono mix (L+R)/2 output to right speaker:**
`{"init":[{"reg":3,"val":2},{"reg":3,"val":3},{"reg":0,"val":0},{"reg":127,"val":140},{"reg":0,"val":41},{"reg":24,"val":[0,64,38,231]},{"reg":28,"val":[0,64,38,231]},{"reg":32,"val":[0,0,0,0]},{"reg":36,"val":[0,0,0,0]},{"reg":0,"val":0},{"reg":127,"val":0}],"poweron":[{"reg":3,"val":3}],"poweroff":[{"reg":3,"val":0}]}
`

**Stereo speakers (BTL mode), right input to right speaker:**
`{"init":[{"reg":3,"val":2},{"reg":3,"val":3},{"reg":0,"val":0},{"reg":127,"val":140},{"reg":0,"val":41},{"reg":24,"val":[0,67,218,96]},{"reg":28,"val":[0,0,0,0]},{"reg":32,"val":[0,0,0,0]},{"reg":36,"val":[0,0,0,0]},{"reg":0,"val":0},{"reg":127,"val":0}],"poweron":[{"reg":3,"val":3}],"poweroff":[{"reg":3,"val":0}]}
`

**Stereo speakers (BTL mode), left input to right speaker:**
{"init":[{"reg":3,"val":2},{"reg":3,"val":3},{"reg":0,"val":0},{"reg":127,"val":140},{"reg":0,"val":41},{"reg":24,"val":[0,0,0,0]},{"reg":28,"val":[0,67,218,96]},{"reg":32,"val":[0,0,0,0]},{"reg":36,"val":[0,0,0,0]},{"reg":0,"val":0},{"reg":127,"val":0}],"poweron":[{"reg":3,"val":3}],"poweroff":[{"reg":3,"val":0}]}

They all work as I hoped. Of course you can change some things and get everything coming out of the left speaker instead.

I haven't configured for mono (PBTL) mode yet and worked out those control sets, but that's next.

frdfsnlght, 2025-02-04:
And now I've enabled PBTL mode with a single speaker.

**Single speaker (PBTL mode), mono mix (L+R)/2:**
`{"init":[{"reg":3,"val":2},{"reg":3,"val":3},{"reg":2,"val":4},{"reg":0,"val":0},{"reg":127,"val":140},{"reg":0,"val":41},{"reg":24,"val":[0,64,38,231]},{"reg":28,"val":[0,64,38,231]},{"reg":32,"val":[0,0,0,0]},{"reg":36,"val":[0,0,0,0]},{"reg":0,"val":0},{"reg":127,"val":0}],"poweron":[{"reg":3,"val":3}],"poweroff":[{"reg":3,"val":0}]}
`

**Single speaker (PBTL mode), right input only:**
`{"init":[{"reg":3,"val":2},{"reg":3,"val":3},{"reg":2,"val":4},{"reg":0,"val":0},{"reg":127,"val":140},{"reg":0,"val":41},{"reg":24,"val":[0,67,218,96]},{"reg":28,"val":[0,0,0,0]},{"reg":32,"val":[0,0,0,0]},{"reg":36,"val":[0,0,0,0]},{"reg":0,"val":0},{"reg":127,"val":0}],"poweron":[{"reg":3,"val":3}],"poweroff":[{"reg":3,"val":0}]}
`

**Single speaker (PBTL mode), left input only:**
`{"init":[{"reg":3,"val":2},{"reg":3,"val":3},{"reg":2,"val":4},{"reg":0,"val":0},{"reg":127,"val":140},{"reg":0,"val":41},{"reg":24,"val":[0,0,0,0]},{"reg":28,"val":[0,67,218,96]},{"reg":32,"val":[0,0,0,0]},{"reg":36,"val":[0,0,0,0]},{"reg":0,"val":0},{"reg":127,"val":0}],"poweron":[{"reg":3,"val":3}],"poweroff":[{"reg":3,"val":0}]}
`

They all work perfectly. I can finally do what I've wanted to do. Thanks for the help!

anabolyc, 2025-02-04:
I need to double-check the labels, I may have mixed them. Please double check the sequence for both cases.

Right only:
```
    { REG_BOOK_SET, 0x8c },
    { REG_PAGE_SET, 0x29 },
    { 0x18, 0x00 }, //  Input Mixer Left to left = -110 dB
    { 0x19, 0x00 },
    { 0x1a, 0x00 },
    { 0x1b, 0x00 },
    { 0x1c, 0x00 }, //  Input Mixer Right to left = 0 dB
    { 0x1d, 0x80 },
    { 0x1e, 0x00 },
    { 0x1f, 0x00 },
    { 0x20, 0x00 }, //  Input Mixer Left to right = -110 dB
    { 0x21, 0x00 },
    { 0x22, 0x00 },
    { 0x23, 0x00 },
    { 0x24, 0x00 }, //  Input Mixer Right to right = -110 dB
    { 0x25, 0x00 },
    { 0x26, 0x00 },
    { 0x27, 0x00 },
```

Left only:
```
    { REG_BOOK_SET, 0x8c },
    { REG_PAGE_SET, 0x29 },
    { 0x18, 0x00 }, //  Input Mixer Left to left = -110 dB
    { 0x19, 0x00 },
    { 0x1a, 0x00 },
    { 0x1b, 0x00 },
    { 0x1c, 0x00 }, //  Input Mixer Right to left = 0 dB
    { 0x1d, 0x80 },
    { 0x1e, 0x00 },
    { 0x1f, 0x00 },
    { 0x20, 0x00 }, //  Input Mixer Left to right = -110 dB
    { 0x21, 0x00 },
    { 0x22, 0x00 },
    { 0x23, 0x00 },
    { 0x24, 0x00 }, //  Input Mixer Right to right = -110 dB
    { 0x25, 0x00 },
    { 0x26, 0x00 },
    { 0x27, 0x00 },
```

Mono:
```
    { REG_BOOK_SET, 0x8c },
    { REG_PAGE_SET, 0x29 },
    { 0x18, 0x00 }, //  Input Mixer Left to left = -6 dB
    { 0x19, 0x40 },
    { 0x1a, 0x26 },
    { 0x1b, 0xe7 },
    { 0x1c, 0x00 }, //  Input Mixer Right to left = -6 dB
    { 0x1d, 0x40 },
    { 0x1e, 0x26 },
    { 0x1f, 0xe7 },
    { 0x20, 0x00 }, //  Input Mixer Left to right = -110 dB
    { 0x21, 0x00 },
    { 0x22, 0x00 },
    { 0x23, 0x00 },
    { 0x24, 0x00 }, //  Input Mixer Right to right = -110 dB
    { 0x25, 0x00 },
    { 0x26, 0x00 },
    { 0x27, 0x00 },
```

This is coming directly from TI's PurePath, including comments, so I'm confident about the channel labels. BTW, please check if your WS signal is not inverted by any chance

frdfsnlght, 2025-02-04:
Your left and right sequences look identical to me and your mono sequence is the same as what you originally provided. But I do see the value now for 0dB is 0x00 0x80 0x00 0x00 and not the value I was using, but that just changes the level a little. I'll correct my sequences with that value.

As for the WS signal, I have no way of checking that. Isn't that a signal between the ESP and the DAC? Do I have any control over that? I'm just using the config as it came shipped, except for changing the dac_controlset value.

anabolyc, 2025-02-04:
My mistake, left and right corrected. Mono is the same as above.
Was can be inverted in the i2s init config, but if you didn't do any changes around it, it is probably not inverted by default.

frdfsnlght, 2025-02-04:
I didn't make that change. I was just looking at the squeezelite docs and I see that "ws" is defined there, but it doesn't look like it can be inverted like some of the other signals.

frdfsnlght, 2025-02-04:
I've updated my sequences above to change the 0dB level to 0x00 0x80 0x00 0x00 ([0,128,0,0]).

frdfsnlght, 2025-02-05:
Your idea about the WS signal being inverted may have merit, but I can't find a way to change it. I think it would explain a lot. However, looking at the ESP32 i2s library, specifically [this page](https://docs.espressif.com/projects/esp-idf/en/v4.2/esp32/api-reference/peripherals/i2s.html), there doesn't seem to be a way to invert the WS line. But I'm wondering if some other field (maybe communication_format?) in the i2s_config_t structure needs to have a different value. I don't think squeezelite-ESP gives you the ability to tweak those fields though. I didn't dig enough into the squeezelite code to figure out what values are used in that structure, so I'm not sure if anything should be changed. But it was a thought.

anabolyc, 2025-02-05:
Search for `invert_flags` [here](https://docs.espressif.com/projects/esp-idf/en/stable/esp32/api-reference/peripherals/i2s.html)

frdfsnlght, 2025-02-05:
That looks interesting, but I can find it's use anywhere in the squeezelite code? And there's nothing in the squeezelite docs about the ability to invert the WS signal. So it might require a patch to squeezelite?

Closed 2025-02-09.

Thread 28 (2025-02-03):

HiFi-ESP ethernet

frdfsnlght, 2025-02-03:
I've just received my order for a HiFi-ESP board (rev F) with W5500 ethernet interface pre-installed. How do I get the interface working?

I've plugged in the antenna and got it working over WiFi, but I'd really like to use the ethernet port instead. I assume I have to configure the "SPI Bus Parameters" under the "Hardware" tab in squeezelite-ESP32, but I'm not 100% sure what put in the various fields.

Any help would be appreciated.

anabolyc, 2025-02-03:
Hey @frdfsnlght , please have a look [here](https://github.com/sonocotta/esp32-audio-dock?tab=readme-ov-file#optional-spi-ethernet-module)

frdfsnlght, 2025-02-04:
For some reason I didn't see that before. I'll give it a try tomorrow. Thanks.

frdfsnlght, 2025-02-04:
I've got the ethernet configured with the settings you've referenced. Works perfectly.

However, as I noted in issue #27, the right/left output is swapped just like in the Louder-ESP. Not a huge problem, I'll just swap the RCA plugs on the cable I'm using.

anabolyc, 2025-02-04:
Thanks for letting me know. I'll double check the labels

bib2, 2025-02-05:
Hi please can you explain me how i can do these changes on the louder esp32 to enable lan ethernet?

Do i have to flash it again with changed settings or is there a terminal available where i can enter this commands (e.g. like on raspberry)? Maybe Telnet?

anabolyc, 2025-02-05:
@bib2
- Access your device over HTTP (you need to find it's IP from your router or from device serial console)
- Reboot to recovery (the button is in the update section I think)
- Access NVS settings when in Recovery
- Update spi and ethernet values as stated in docs
- Save and exit recovery

bib2, 2025-02-10:
I did this like described. But i can´t find it on my dhcp server.

Is the ap-ip-settings also used with ethernet? I can see 192.168.4.1 there.

I can connect with my smartphone over wifi, but i don´t see it ony my router menu.

If i add the two lines in the recovery mode, is dhcp activated or do i have to do something more?

anabolyc, 2025-02-10:
Squeezelite-esp32 is not able to use both ethernet and wifi at the same time. With the eth config in place, it will boot up and try to init ethernet and get IP from the DHCP server (or use static IP). If unsuccessful, it will reboot into wifi mode and no longer use ethernet, until the next reboot. That seems to be the case.

Can you please check and confirm that after a reset ethernet logs are present and check if there is anything about DHCP. Are there any lights on the ethernet when it boots (greed/yellow next to RJ45 and red power light on the bottom)?

bib2, 2025-02-10:
Green led is on, orange is blinking. When i maked a reboot, i can´t access via the old ip. I open my smartphone wifi settings and there i can see the AP again. I have to enter the AP and login to the wifi again.

ping is not working. When i connect to the wifi, i get back the ping immediately.

anabolyc, 2025-02-10:
Okay, got it, that sounds promising.

When it reboots and gets IP from the DHCP it will not be the same address, since the MAC of the wifi is different from ethernet. Best would be to attach a serial debugger over the USB-C (Don't connect high voltage at the same time!) and capture the boot log using the web-installer or serial monitor app. Once more, when ethernet is active, wifi will be completely off, so don't count on it to connect to the board, USB-c is your only friend

bib2, 2025-02-10:
Ok. But to clarify:

ip-settings in nve editor are for wifi only? The setting starts with ap- ... There are no ip settings for ethernet in nve editor?

Ethernet is DHCP only? No fixed IP?

And ap setting is for Access Point only? When i connect to a wifi, it will be useless? Then dhcp only?

anabolyc, 2025-02-10:
Please use  [web installer](https://sonocotta.github.io/esp32-audio-dock/) with the **erase** check box pressed. If it didn't help, I'd agree it is a hardware issue, I'll replace your board.

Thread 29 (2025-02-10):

Unable to Flash Louder ESP32-S3

Dotsch2005, 2025-02-10:
I want to install the snap client via “https://sonocotta.github.io/esparagus-snapclient/” and connect the board.

Access via “Logs & Console” works without any problems.

Is there a trick?

The WLAN hotspot does not work either.

[esp-web-tools-logs (2).txt](https://github.com/user-attachments/files/18733840/esp-web-tools-logs.2.txt)

anabolyc, 2025-02-10:
You might need to reset the board with FLASH button pressed. Please try that. Also, if that didn;t help, please include the logs from the Chrom Dev Tools while you're trying to flash it

Dotsch2005, 2025-02-10:
Is it the TOO Button?

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

Dotsch2005, 2025-02-10:
Okay, it looks like the ESP32-S3 board is not supported for Snapcast, or is it?

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

[sonocotta.github.io-1739199553254.log](https://github.com/user-attachments/files/18735631/sonocotta.github.io-1739199553254.log)

anabolyc, 2025-02-10:
Oh, I totally missed it. You're right, snapcast is not supported on the S3 at the moment. Some time ago I managed to build and flash it from the source code, but it was stuttering. I think it was a memory issue, not a DAC issue. Can you please reach out to [CarlosDerSeher](https://github.com/CarlosDerSeher/snapclient) and check if he's looking to add S3 support? I'm willing to give away a Louder-ESP32S3 board to anyone willing to make it work, shipping included.

Dotsch2005, 2025-02-10:
Is a program modification necessary here or must another sdkconfig be created?

I bought 3 boards of the Louder ESP32-S3, so a implementation would also be interesting for me.

I would have a look around [CarlosDerSeher](https://github.com/CarlosDerSeher/snapclient).

Dotsch2005, 2025-02-11:
Thank you, I have opened an issue at [CarlosDerSeher Issue 112](https://github.com/CarlosDerSeher/snapclient/issues/112)

I have tried to modify the SDKConfig myself and have also found the problem with the APLL. As you said, it's only a minimal change.

Do you still have the SDKConfig? The board always resets after HAL: INIT.

anabolyc, 2025-02-11:
Please look at [this branch](https://github.com/sonocotta/esparagus-snapclient/tree/features/s3-support)

Dotsch2005, 2025-02-12:
I tried to solve the problem in the issue at [CarlosDerSeher](https://github.com/CarlosDerSeher/snapclient/issues/112).

I couldn't find the information in the [branch ](https://github.com/sonocotta/esparagus-snapclient/tree/features/s3-support) either.

According to the [documentation](https://www.tindie.com/products/sonocotta/louder-esp32/), the I2S and I2C pins are different. Is the I2C_ADDR the same?

I have already tested the ESP-IDF example for an I2C scanner, but unfortunately it cannot find an address. I can't find a suitable SDKConfig for the ESP32S3 in the [Branch](https://github.com/sonocotta/esparagus-snapclient/tree/features/s3-support) either.

anabolyc, 2025-02-12:
You're right, I didn't commit the sdkconfig in the branch, my bad. Please check [this one](https://github.com/sonocotta/esparagus-snapclient/blob/master/sdkconfig.esparagus-echo-debug), it is not the same board (MAX98357 DAC), but it is for S3 and it was building and running as far as I remember.

I referred to the branch since it has [build error fixes](https://github.com/sonocotta/esparagus-snapclient/commit/f1b51dadc574875517ab0e1a2d13d5d836475d80) that should give you a green build to start with.

You found the correct pinout right. I2C address is the same, but I2C pinout is different. Long story short, every pin is different. I'll try to create a build for Louder-ESP32S3 that runs and produces a sound, and I'll share it that way. Give me some time, please.

Dotsch2005, 2025-02-13:
Thanks for checking and updating the repo.

Unfortunately I get the following error when compiling:
```
-- Performing Test C_COMPILER_SUPPORTS_WFORMAT_SIGNEDNESS
-- Performing Test C_COMPILER_SUPPORTS_WFORMAT_SIGNEDNESS - Success
-- App "snapclient" version: eac5495-dirty
-- Adding linker script D:/Github/esparagus-snapclient/build/esp-idf/esp_system/ld/memory.ld
-- Adding linker script D:/Github/esp-idf-v5.1.1/components/esp_system/ld/esp32s3/sections.ld.in
-- Adding linker script D:/Github/esp-idf-v5.1.1/components/esp_rom/esp32s3/ld/esp32s3.rom.ld
-- Adding linker script D:/Github/esp-idf-v5.1.1/components/esp_rom/esp32s3/ld/esp32s3.rom.api.ld
-- Adding linker script D:/Github/esp-idf-v5.1.1/components/esp_rom/esp32s3/ld/esp32s3.rom.libgcc.ld
-- Adding linker script D:/Github/esp-idf-v5.1.1/components/esp_rom/esp32s3/ld/esp32s3.rom.newlib.ld
-- Adding linker script D:/Github/esp-idf-v5.1.1/components/esp_rom/esp32s3/ld/esp32s3.rom.version.ld
-- Adding linker script D:/Github/esp-idf-v5.1.1/components/soc/esp32s3/ld/esp32s3.peripherals.ld
CMake Error at D:/Github/esp-idf-v5.1.1/tools/cmake/component.cmake:313 (message):
  Include directory
  'D:/Github/esparagus-snapclient/components/improv_wifi/Improv-WiFi-Library/src'
  is not a directory.
Call Stack (most recent call first):
  D:/Github/esp-idf-v5.1.1/tools/cmake/component.cmake:482 (__component_add_include_dirs)
  components/improv_wifi/CMakeLists.txt:4 (idf_component_register)

-- Configuring incomplete, errors occurred!
See also "D:/Github/esparagus-snapclient/build/CMakeFiles/CMakeOutput.log".
cmake failed with exit code 1
```

I checked for ESP-IDF v5.1.5 and the branch [fix_20ms_chunk_size_bug](https://github.com/CarlosDerSeher/snapclient/tree/fix_20ms_chunk_size_bug) as recommended by [CarlosDerSeher](https://github.com/CarlosDerSeher). Here the compile works, but it hangs.

It gets stuck at `HAL: INIT` when I enable PSRAM and when PSRAM is disabled it gets stuck at `WIFI: wifi_init_sta finished`.

Is it possible that the board is defective or does not have PSRAM installed?

Many many thanks

anabolyc, 2025-02-13:
You need to sync submodules, it will fix the build.
PSRAM is built-in on module, I really doubt there is an issue with that, just double check the PSRAM settings in the SDKCONFIG

ataa, 2025-02-13:
> Is it possible that the board is defective or does not have PSRAM installed?

Use this to check for PSRAM : https://github.com/AdamJHowell/ESP32_CPU_Memory_Info

It will generate a report like this:

```
Source file: C:\ESP32_CPU_Memory_Info\ESP32_CPU_Memory_Info.ino
ESP32 Chip model: ESP32-D0WDQ6
  Revision: 3
  Core count: 2
  Chip ID: 381348
  Frequency: 240
  Cycle count: 1002386537
  SDK version: v4.4.2
Heap:
  Total: 363804
  Used: 25300
  Free: 338504
  Largest block: 118772
  Minimum free since boot: 333112
Flash:
  Total: 16777216
  Speed: 80000000
Sketch:
  Size: 264336
  Free: 1310720
PSRAM:
  Total: 4192139
  Used: 0
  Free: 4192139
  Largest block: 4128756
  Minimum free since boot: 4192139
Next printout in 20 seconds.
```

Dotsch2005, 2025-02-13:
> You need to sync submodules, it will fix the build. PSRAM is built-in on module, I really doubt there is an issue with that, just double check the PSRAM settings in the SDKCONFIG

Oh man... I forgot about that. I'm so sorry!
With the branch and the SDKCONFIG the compile works.

Unfortunately it doesn't work with the latest version ([fix_20ms_chunk_size_bug](https://github.com/CarlosDerSeher/snapclient/tree/fix_20ms_chunk_size_bug)). I'll tinker around with it a bit more.

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

This is what I was looking for. Thank you!

Closed 2025-04-09.

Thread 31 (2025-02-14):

Louder ESP32-S3 dead on arrival?

elektrinis, 2025-02-14:
I bought one of these on tindie. Should be preinstalled with squeezelite and LAN port.
When I powered it via USB, wifi AP did not appear. Connected LAN - LEDs not blinking. So it's dead, or not flashed?

Tried to flash it via windows installer, but getting "Failed to execute 'open' on 'SerialPort'". After trying many times, if I pass this, I then get "Failed to initialize. Try resetting your device or holding the BOOT button while clicking INSTALL."
There's no boot button, but tried it with IO0 - no help. Also tried it per ESP's instructions: hold boot, press reset, release boot. Still no action.

What else can I do?
I'm an engineer, but I no longer have the time to hack things together, I bought it to use it.

ataa, 2025-02-14:
Have you tried powering it using the power terminal instead of USB-C? It will accept 5V to 26V.

anabolyc, 2025-02-14:
Hey @elektrinis . S3 is a bit different from the regular ESP32. It has a USB port for flashing and debugging purposes, but it only gets initialized when the board boots up with the right parameters. That said, first you need to make sure you connect to the right serial port, ti will show up in the Linux as ttyACMx, not really sure how this looks like in the Windows.

Second, flashed or not, S3 sometimes requires placing it into download mode for esp-web-tools to work, as I said S3 is a bit different there. And the sequence you mentioned is right, IO0 (aka FLASH) pressed, RESET clicked, FLASH released. Look up Serail port after that and web flasher should work.

If it spins forever, you might want to open Chrome Web tools and the console will give you a bit more information on how it is going. Sometimes it is a permissions issue, in most cases wrong serial port.

Just to be clear, I flash and test every board myself if you got it from Tindie, so it was working when it left my hands. I'm fairly confident it is an issue we can fix, but also I'm open to a return and refund if it is more than you're ready to invest. Please feel free to bail out any time

elektrinis, 2025-02-14:
I'd prefer to get it working, as there are really no alternatives.
Do you test them with USB or external power?
I've tested with phone's brick and with laptop's port.
Also laptop brick did not work, which you may want to take a look in future.

My unit is acting strangely when connected to laptop. Sometimes I get a virtual COM port, other times it's the same com port plus JTAG interface (with a yellow exclamation mark - no driver found).

elektrinis, 2025-02-14:
OK, I've fried my laptop. I supplied 19V to the board and plugged in USB. Laptop switched off and will not turn on. Battery re-plug did not fix it.
So I'm guessing the 19V were supplied in reverse to the laptop.
A sensible thing would be to add a diode or ideal diode on USB power.
Now I have a brick worth €1k and upcoming recovery of data.

anabolyc, 2025-02-14:
> I'd prefer to get it working, as there are really no alternatives. Do you test them with USB or external power? I've tested with phone's brick and with laptop's port. Also laptop brick did not work, which you may want to take a look in future.

I test them with USB only

> My unit is acting strangely when connected to laptop. Sometimes I get a virtual COM port, other times it's the same com port plus JTAG interface (with a yellow exclamation mark - no driver found).

I guess you're missing the drivers then

> OK, I've fried my laptop. I supplied 19V to the board and plugged in USB. Laptop switched off and will not turn on. Battery re-plug did not fix it.

I'm really sorry about that, that's why it says underneath not to do that very specific thing
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

I thought long and hard before doing those schematics, and the main reason is I don't want every single unit to lose voltage and consequently output power and risk cooking the diode (it should withstand up to 5A),  when it is fairly easy to develop/debug/test using cable only, and only connect full power when ready to deploy.

You pushed 19V into your USB port, which should cook the USB driver, hopefully nothing more. I hope there is a fuse that can be replaced and bring it back to life.

elektrinis, 2025-02-15:
Did not see the warning. It's good it's there. As for laptop, I think damage may be deep, down to dc-dc converter. Not going to attempt a fix. Expensive lesson.

I bought a new laptop, restored all data and tried again. Same results. Every time I plug it in, I get different behavior. One time I get COM3 (driver fully installed), other time I get COM4 + "Unknown device". Another time I get again COM3 + JTAG interface.

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

Different errors on web installer. One time I get "can't open port", other time install fails with suggestions about buttons. I do the button thing, but nothing changes.

I've tested 3 different USB cables, two laptops, different browsers and spent a lot of time on this. I believe it's defective.

I'd like a replacement. How can I contact you for further steps?

anabolyc, 2025-02-15:
I can replace it, no worries, just trying to avoid the case when the new one will do the same trick on you. As I said, the S3 is not the same as the classic ESP3, it works differently.

With the web tools, can you please open the Chome Dev Console on the console log and try again your routine? This should give you more information on how the communication flow goes.

anabolyc, 2025-02-16:
Is this whole log you see? Improv Serial relates to Wifi-configuration, that is not that much relevant for initial flashing. Errors are not that promising, you might simply missing device drivers. Let me try this on my Windows laptop and I'll see if it works and if the log look any similar. If you can provide full log here, I'll have something to compare to

elektrinis, 2025-02-17:
Yes, this is full log, there is no more output. Tried it a few times.

anabolyc, 2025-02-17:
BTW I can replace it with the regular ESP32 version, to make things simpler for you. Is there a specific reason for you to use S3?

elektrinis, 2025-02-17:
I have just tested flashing my devboard with second USB port. It worked properly.
I'm sure there is nothing wrong on my end, with drivers etc. There is nothing else I can do.
Let me know your email so we can resolve this matter privately. Thanks.

anabolyc, 2025-02-17:
> I have just tested flashing my devboard with second USB port. It worked properly. I'm sure there is nothing wrong on my end, with drivers etc. There is nothing else I can do. Let me know your email so we can resolve this matter privately. Thanks.

Okay, got it. Please reach out at andriy@sonocotta.com. Sorry about the confusion.

anabolyc, 2025-02-18:
Replacement board has been shipped out

elektrinis, 2025-03-05:
Replacement board arrived and is working fine. Thank you.
Issue resolved.

Closed 2025-03-05.

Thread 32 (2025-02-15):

How to connect ST7789 on Louder-ESP32-S3 ! Problem to identify PIN !

nanostra, 2025-02-15:
Hello,

Hello, I purchased a Louder-ESP32-S3 with an external antenna on Tindie.
I do not have an optional Ethernet port connected.
I am using Squeezelite.

**1. I managed to connect a KU-040 rotary encoder and make it work properly with Squeezelite**

- CLK on GPIO 12 SPI CLK,
- DT on GPIO 11 SPI MOSI,
- SW on GPIO10

`Squeezelite NVS Editor --> Rotary_config --> A=11,B=12,SW=10,volume,longpress`

For your information, a short press = Play/Pause, rotating left/right increases the volume.
A long press changes the mode, rotating left/right selects the previous/next track.

**2. I am now trying to connect a 2.8" ST7789 240x320 display, but I can't find some pins mentioned in your documentation, especially PIN 37 OLED SPI DC!!! Where is this PIN 37 located?  Similarly, I cannot find PIN RGBOUT 9 anywhere!**

**Could you please tell me where PIN 37 and RGBOUT 9 are located and confirm that my connection diagram is correct?**

Thank you for this very nice project, even though I’m struggling to identify the pins I need! 😊

```
GND  -->GND
VCC	  --> 3.3V
SCL (SPI CLK)	--> OLED SPI CLK GPIO 12 (Shared with encoder)
SDA (SPI MOSI)  --> OLED SPI MOSI GPIO 11 (Shared with encoder)
RST (Reset)        --> OLED RST GPIO 38
**DC (Data/Command) --> ???? GPIO 37**
CS (Chip Select)  --> OLED SPI CS GPIO 39
BL (Backlight) --> Not connected
```

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

anabolyc, 2025-02-15:
Hey @nanostra
Pin 37 is blocked by PSRAM, I didn't route it out. Pin 9 is used by I2C. You can use pretty much any pin available as a test point on the front and back sides. I routed out all pins that are not booked yet.

nanostra, 2025-02-16:
I solved the problem with these explanations. I was hesitant to use these pins, as the ones available in the documentation seemed to be limited to those listed. Maybe you could clarify this point in the documentation.

What is the version of Squeezelite installed on your page https://sonocotta.github.io/esp32-audio-dock/ ?

There are quite a few bugs with Spotify artworks, causing the Louder-ESP32S3 to crash... or it might be a compilation issue.
I have opened a ticket on the Squeezelite GitHub, but maybe it's better to ask you instead.

🚨 Issue encountered

When Spotify sends an image URL (artwork) for the current track, the ESP32 attempts to download it but fails with the following error in the logs. Squeezelite then completely crashes, and I have to reboot and remove the artwork:1 option.

```
I (50365) cspot: requesting artwork https://i.scdn.co/image/ab67616d00001e029a494f7d8909a6cc4ceb74ac
I (50365) display: playing Chris Brown - Under The Influence
[00:05:13.786] D MercurySession.cpp:252: Executing Mercury Request, type SEND
E (50415) HTTP_CLIENT: No transport found

> E (50425) HTTP_CLIENT: Please enable HTTPS at menuconfig to allow requesting via https

W (50425) cspot: artwork error or too large 0
```
Thank you for your great work! 😊

anabolyc, 2025-02-16:
I will have a look. Seems to be fairly easy to fix. I was planing to update the code to the latest as well. Give me some time and I'll give you a build to test.

anabolyc, 2025-02-17:
@nanostra can you please try it out at https://sonocotta.github.io/esp32-audio-dock/
I've updated to the latest code and build with the following flags updated
```
#
# ESP HTTP client
#
CONFIG_ESP_HTTP_CLIENT_ENABLE_HTTPS=y
CONFIG_ESP_HTTP_CLIENT_ENABLE_BASIC_AUTH=y
CONFIG_ESP_HTTP_CLIENT_ENABLE_DIGEST_AUTH=y
```

nanostra, 2025-02-17:
Hello, @anabolyc,

Thank you for your feedback... But apparently, this did not solve the problem, and the Louder still crashes, I have to reboot it and remove the artwork option.

Another possibility would be to retrieve the artwork using an HTTP request instead of HTTPS...

**Example:**

`http://i.scdn.co/image/ab67616d00001e02c58b581c98eafab982391a6d`

Additionally, when I enable Telnet, I completely lose access to the Louder, and I have to reinstall the firmware to regain control.
For logs, I use Console-Log from your web page.

Similarly, if I disable Bluetooth, which is logically unnecessary on the ESP32-S3, I also lose access to the Louder and have to reinstall the firmware. But these are separate issues.

**Questions:**

Do you have documentation for compiling the firmware for the Louder-ESP32-S3?
**At least, do you have the specific parameters needed for it?**
I usually work with PlatformIO. Would it be easy to port/compile the project on this platform?

```
[00:00:57.427] I MercurySession.cpp:42: Received packet, command: 178
[00:00:57.431] D MercurySession.cpp:174: Received mercury packet
[00:00:57.460] I MercurySession.cpp:42: Received packet, command: 178
[00:00:57.464] D MercurySession.cpp:174: Received mercury packet
[00:00:57.795] I TrackPlayer.cpp:206: Playing
[00:00:57.797] I Shim.cpp:120: new track started <> => <de8bfbbe2281f3162ebb36b89523e4d624cc484f>
[00:00:57.809] I Shim.cpp:262: next track will play in 0 ms
[00:00:57.827] _output_frames:150 track start sample rate: 44100 replay_gain: 0
[00:00:57.885] I Shim.cpp:416: next track's audio has reached DAC (offset 6085)
[00:00:57.893] D MercurySession.cpp:252: Executing Mercury Request, type SEND
I (58949) cspot: requesting artwork https://i.scdn.co/image/ab67616d00001e02c58b581c98eafab982391a6d
I (58949) display: playing Marnik - Boyz In Paris (with VINAI)
[00:00:57.951] D MercurySession.cpp:252: Executing Mercury Request, type SEND
E (59029) esp-tls-mbedtls: No server verification option set in esp_tls_cfg_t structure. Check esp_tls API reference
E (59029) esp-tls-mbedtls: Failed to set client configurations, returned [0x8017] (ESP_ERR_MBEDTLS_SSL_SETUP_FAILED)
E (59039) esp-tls: create_ssl_handle failed
E (59049) esp-tls: Failed to open new connection
E (59049) TRANSPORT_BASE: Failed to open a new connection
E (59059) HTTP_CLIENT: Connection failed, sock < 0
W (59069) cspot: artwork error or too large 0
I2S abort!
```
[nvs_config_squeezelite_config_avec_ecran+artwork.txt](https://github.com/user-attachments/files/18830718/nvs_config_squeezelite_config_avec_ecran%2Bartwork.txt)

anabolyc, 2025-02-17:
S3 support is not official, I'm afraid. I will add to the repo sdkconfig, that I'm using, it builds and runs with the latest code, with certain limitations like you already discovered, lack of telnet and Bluetooth.

If the https issue is not S3 specific, good chances it can get fixed if you report it to sqeezelite-esp32 official repo.

I tried in the past to make it build in Platformio but gave up in the end. They use quite old esp-idf and it is a bit like wrestling every time. But feel free to go for it.

anabolyc, 2025-02-17:
[Here](https://github.com/sonocotta/esp32-audio-dock/tree/main/firmware/squeezelite-esp32) it is

nanostra, 2025-02-17:
There is a branch for the S3, but it seems abandoned...
https://github.com/sle118/squeezelite-esp32/tree/4.4-s3

This Squeezelite project doesn’t seem very active anymore...

Do you know of any other similar projects that support AirPlay, rotary encoder control, and screen integration?

anabolyc, 2025-02-17:
I think squeezelite-esp32 authors switched to [euphonium](https://github.com/muvox-io/euphonium), I'm not sure in which stage it is and if it supports screen options

anabolyc, 2025-02-17:
Look into ESPHome + Home Assitant maybe

nanostra, 2025-02-17:
Thank you very much. I will take a look to euphonium.

> Philippe44 answer me... to say "It's a config error from the s3 build.. As I don't provide "official" s3 build, the author should change menuconfig to enable HTTPS " :-)

I use Home Assistant with more than 90 devices. However, for this use case, I don’t want to depend on Home Assistant because I don’t see much benefit in it, like in LMS...

I also have a 3D speaker design that I’m testing, in which I wanted to integrate the Louder-ESP32-S3, but I’m now realizing that I probably shouldn’t have chosen the S3.

I’ll keep you updated on my progress

nanostra, 2025-02-17:
Do you see the last answer from Philippe44 ?

https://github.com/sle118/squeezelite-esp32/issues/473

> Indeed, in ESP-TLS, you have to:
> [] Allow potentially insecure options
> [] Skip server certificate verification by default (WARNING: ONLY FOR TESTING PURPOSE, READ HELP)

philippe44, 2025-02-17:
BTW, we have not switched to euphonium, we collaborated with the dev of euphonium as he wrote cspot and we exchanged some piece of code. I've not been active on squeezelite-esp32 much these past month as life have decided otherwise. But the s3 branch is not stalled, it's not used as a separated branch. All s3 related code is now in the main branch, si it's a single steel of code. Only have I been lazy on the sdkcondig file ...

anabolyc, 2025-02-18:
@philippe44 thanks for correcting me out, I may have misunderstood that

@nanostra how can I test it without a screen, I want to try disabling TLS verification. Alternatively, I can give you steps to build and test with S3. It is fairly straightforward.

nanostra, 2025-02-18:
@anabolyc You can probably try with the NVS file provided earlier in the conversation... but without the screen connected, I'm not sure if it will go all the way.

And yes, I'm interested in compiling it myself.

anabolyc, 2025-02-18:
Okay @nanostra , it is fairly simple
Assuming you pulled the repo and all the submodules. Copy `sdkconfig` that I've provided [here](https://github.com/sonocotta/esp32-audio-dock/tree/main/firmware/squeezelite-esp32)

Run docker container for build
```
docker run --rm -it -v .:/project -w /project -v /dev:/dev --privileged espressif/idf:v4.4.7
```

Inside a container install one dependency
```
pip3 install protobuf grpcio-tools
```

Prepare for the build, change the sdkconfig settings related to tls (Use / for search inside menuconfig)
```
cp sdkconfig.esp32s3 sdkconfig
idf.py set-target esp32s3
IDF_TARGET=esp32s3 idf.py menuconfig
```

Build and flash
```
IDF_TARGET=esp32s3 idf.py build flash monitor
```

Closed 2025-04-09.

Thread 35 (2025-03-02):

Louder-ESP32 "custom component" no longer supported in Home Assistant 2025.2

admn-monkey, 2025-03-02:
Will not validate or compile to update / install. Error below:

`
INFO ESPHome 2025.2.1
INFO Reading configuration /config/esphome/esphome-web-5ffc84.yaml...
Failed config

switch.custom: [source /config/esphome/esphome-web-5ffc84.yaml:60]

  The "custom" component has been removed. Consider conversion to an external component.
  https://esphome.io/guides/contributing#a-note-about-custom-components.
  platform: custom
  lambda: auto tas5805 = new TAS5805();
  App.register_component(tas5805);
  return {tas5805};
  switches:
    name: Enable Amp
`

TommySharpNZ, 2025-03-02:
Yup was just about to log this too!

anabolyc, 2025-03-02:
Hey @admn-monkey @TommySharpNZ. Thanks for reporting. I'm working on this together with a few folks in the community. The test version is here:
```
substitutions:
  devicename: louder-esparagus-kantoor
  long_devicename: "Louder ESParagus kantoor"

esphome:
  name: "${devicename}"
  name_add_mac_suffix: false
  comment: "${long_devicename}"
  on_boot:
    priority: 250
    then:
    ## Set a volume limit just to be safe...
    - media_player.volume_set:
        id: louder_mediaplayer
        volume: 10%

esp32:
  board: mhetesp32minikit

wifi:
  ssid: !secret esphome_wifi_ssid
  password: !secret esphome_wifi_password
  ap:
    ssid: "$devicename Hotspot"
    password: !secret esphome_ap_password

captive_portal:
### Optional if you want ethernet (then remove all wifi config) ###
#ethernet:
#  type: W5500
#  clk_pin: GPIO18
#  mosi_pin: GPIO23
#  miso_pin: GPIO19
#  cs_pin: GPIO05
#  interrupt_pin: GPIO35
#  reset_pin: GPIO14

logger:
  level: DEBUG

api:
  encryption:
    key: !secret esphome_api_key

ota:
  platform: esphome
  password: !secret esphome_ota_password

psram:
  mode: octal
  speed: 80MHz

external_components:
  - source: github://mrtoy-me/esphome-components-test@main
    components: [ tas5805m ]
    refresh: 0s

i2c:
  id: i2c_component
  sda: GPIO21
  scl: GPIO27
  scan: True
  frequency: 400kHz
  timeout: 10ms

audio_dac:
  - platform: tas5805m
    id: tas5805_dac
    enable_pin: GPIO33

i2s_audio:
  i2s_lrclk_pin: GPIO25
  i2s_bclk_pin: GPIO26

media_player:
  - platform: i2s_audio
    name: "${long_devicename} mediaplayer"
    id: louder_mediaplayer
    dac_type: external
    i2s_dout_pin: GPIO22
    mode: stereo
    on_play:
      - switch.turn_on: enable_louder

switch:
  - platform: template
    name: "Enable ${long_devicename}"
    id: enable_louder
    optimistic: true
    turn_on_action:
      - lambda: !lambda |-
          id(tas5805_dac).set_deep_sleep_off();
    turn_off_action:
      - lambda: !lambda |-
          id(tas5805_dac).set_deep_sleep_on();

interval:
  - interval: 1min
    then:
      - if:
          condition:
            - switch.is_on: enable_louder
            - for:
                time: 30s
                condition:
                  or:
                    - media_player.is_idle: louder_mediaplayer
                    - media_player.is_paused: louder_mediaplayer
          then:
            - switch.turn_off: enable_louder
```

NickiNiclas, 2025-03-02:
Based on the above, here is my tested and working config for Louder-ESP32 **S3**

```
substitutions:
  devicename: louder-esp32-01
  long_devicename: "Louder ESP32"

esphome:
  name: "${devicename}"
  name_add_mac_suffix: false
  comment: "${long_devicename}"
  on_boot:
    priority: 800
    then:
    ## Set a volume limit just to be safe...
    - media_player.volume_set:
        id: louder_mediaplayer
        volume: 20%

external_components:
  - source: github://mrtoy-me/esphome-components-test@main
    components: [ tas5805m ]
    refresh: 0s

esp32:
  board: esp32-s3-devkitc-1
  variant: ESP32S3
  flash_size: 16MB
  framework:
    type: arduino

### Optional if you want ethernet (then remove all wifi config) ###
#ethernet:
#  type: W5500
#  clk_pin: GPIO12
#  mosi_pin: GPIO11
#  miso_pin: GPIO13
#  cs_pin: GPIO10
#  interrupt_pin: GPIO6
#  reset_pin: GPIO5

# Enable logging
logger:
  level: DEBUG

psram:
  mode: octal
  speed: 80MHz

audio_dac:
  - platform: tas5805m
    id: tas5805_dac
    enable_pin: GPIO33

switch:
  - platform: template
    name: "Enable ${long_devicename}"
    id: enable_louder
    optimistic: true
    turn_on_action:
      - lambda: !lambda |-
          id(tas5805_dac).set_deep_sleep_off();
    turn_off_action:
      - lambda: !lambda |-
          id(tas5805_dac).set_deep_sleep_on();

i2c:
  sda: GPIO8
  scl: GPIO9
  scan: True
  id: i2c_component

i2s_audio:
  i2s_lrclk_pin: GPIO15
  i2s_bclk_pin: GPIO14

interval:
  - interval: 1min
    then:
      - if:
          condition:
            - switch.is_on: enable_louder
            - for:
                time: 30s
                condition:
                  or:
                    - media_player.is_idle: louder_mediaplayer
                    - media_player.is_paused: louder_mediaplayer
          then:
            - switch.turn_off: enable_louder

media_player:
  - platform: i2s_audio
    name: "${long_devicename} mediaplayer"
    id: louder_mediaplayer
    dac_type: external
    i2s_dout_pin: GPIO16
    mode: stereo
    on_play:
      - switch.turn_on: enable_louder
### max_volume feature - uncomment below to enable
#     on_state:
#       then:
#         - if:
#             condition:
#               lambda: |-
#                 float current_volume = roundf(id(louderesp32).volume * 100) / 100.0;
#                 float max_vol = roundf(${max_volume} * 100) / 100.0;
#                 return current_volume > max_vol;
#             then:
#               - logger.log: "Volume exceeds max volume, resetting to max volume"
#               - media_player.volume_set:
#                   id: louderesp32
#                   volume: ${max_volume}
#               - logger.log: "Volume set to max volume"
```

TommySharpNZ, 2025-05-03:
I now get this error when trying to flash my rev H ESP Louder....

Octal PSRAM is only supported on ESP32-S3, not ESP32.

TommySharpNZ, 2025-05-03:
I'll grab the latest ESPHome code from the repository and see if that helps.

admn-monkey, 2025-05-12:
@anabolyc  That worked for me. Running well on ESPHome 2024.11.3 (ready now to switch to 2025.4.2, just not today).

admn-monkey, 2025-05-14:
@anabolyc I just tested with ESPHome Device Builder 2025.4.2 and also receive the error below.

`  Octal PSRAM is only supported on ESP32-S3, not ESP32.
  mode: octal
  speed: 80000000.0
  enable_ecc: False`

anabolyc, 2025-05-21:
I'm testing the mrtoy's [dev branch](https://github.com/mrtoy-me/esphome-components-test/blob/dev/components/tas5805m/esp32S3_louder_idf_media.yaml) currently. With S3 it works flawlessly. With the ESP32 it crashes on playback. I'll try to play with SDKCONFIG settings

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

anabolyc, 2025-05-23:
While work is still in progress, I'm posting the config that works for me (external component work is not finalized yet). It is based on esp-idf and compared to the Arduino implementation, it works much better, no glitches and much more stable, at least based on my limited experience. Bonus points, this implements a 15-band equalizer, with -15..+15dB regulation, works really amazing, really looking forward to having it finalized

```yaml

substitutions:
  name: esphome-web-dc73f8
  friendly_name: louder-esp32
  task_stack_in_psram: "false"

esphome:
  name: ${name}
  friendly_name: ${friendly_name}
  min_version: 2024.11.0
  name_add_mac_suffix: false
  platformio_options:
    board_build.flash_mode: dio
  # on_boot:
  #   priority: 600  # After most components are initialized
  #   then:
  #     - lambda: |-
  #         id(tas5805m_dac).set_volume(int(id(current_volume)));
  #         ESP_LOGI("tas5805m", "Restored volume on boot: %.0f", id(current_volume));
esp32:
  board: mhetesp32minikit
  flash_size: 8MB
  framework:
    type: esp-idf
    version: recommended
    sdkconfig_options:
      CONFIG_BT_ALLOCATION_FROM_SPIRAM_FIRST: "y"
      CONFIG_BT_BLE_DYNAMIC_ENV_MEMORY: "y"

      CONFIG_MBEDTLS_EXTERNAL_MEM_ALLOC: "y"
      CONFIG_MBEDTLS_SSL_PROTO_TLS1_3: "y"  # TLS1.3 support isn't enabled by default in IDF 5.1.5

# Enable logging
logger:
  level: DEBUG

# Enable Home Assistant API
api:

# Allow Over-The-Air updates
ota:
  platform: esphome
  password: !secret esphome_ota_password

wifi:
  ssid: !secret esphome_wifi_ssid
  password: !secret esphome_wifi_password
  ap:
    ssid: "$name Hotspot"
    password: !secret esphome_ap_password

captive_portal:

psram:
  speed: 80MHz

#  - source: /config/esphome/esp32-tas5805m-dac/esphome/components
#  - source: /config/esphome/external/esphome-components-test/components
external_components:
  - source: github://mrtoy-me/esphome-components-test@dev
    components: [ tas5805m ]
    refresh: 0s

# script:
#   - id: set_volume
#     parameters:
#       level: float
#     then:
#       - lambda: |-
#           id(current_volume) = level;
#           id(tas5805m_dac).set_volume(int(level));
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

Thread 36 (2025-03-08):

No sound when playing announcement

elektrinis, 2025-03-08:
I have a Louder ESP32s3 and it has a weird issue with playing my mp3 file.
I'm using it with squeezelite firmware (the one it shipped with), LMS and Home Assistant with Piper addon (text to speech).
In HA, I use it mainly as internet radio player, which works really well for a few days now.
I also use it to play announcements. For example, this one:
https://www.dropbox.com/scl/fi/lhd7rvgkuid3l50u5mwbs/someone-at-the-door.mp3
When sent to play, the status of player changes to "playing" and "media_position" advances until it finishes. Everything looks normal as if it was working fine, however there is no audio output, it's completely silent. It plays normally when switched back to internet radio stream.
If I visit the full url of "media_content_id", my browser plays the file normally.
Before this I was running original squeezelite firmware on chinese A1S devboard and it worked fine.
Any ideas?

anabolyc, 2025-03-08:
Hey @elektrinis

First of all, S3 support of squeezelite-esp32 is unofficial, so I would be ready for some bugs. Second, would you be able to pull some logs over Serial.

I'm working on the updated TAS5805M driver that will implement a few diagnostics and fault-reading methods, I'm planning to start testing it in the next few weeks. I might be able to give you a better logging output soon, but for now if you can pull what you already have, that might be a good first step

elektrinis, 2025-05-21:
Just a short update I still have this issue and could not find a workaround.
Any news on diagnostics? What's the latest version and how to update without connecting USB?

anabolyc, 2025-05-21:
Hey @elektrinis . I'm currently testing a new esp-idf implementation with ESPHome, which implements enforced encoding before playback. Probably the problem lies there. When I finish testing for ESPHome, I can try out the same using squeezelite-esp32 with Piper or Google TTS (if I figure out how to do it). If you can find a way to enforce a specific media format, that would probably be the way to fix it.
Myself I was too lazy to fix it, so I deployed another ESPHome device just for text announcements. But that's me, I have a few extra boards and speakers I can spare.

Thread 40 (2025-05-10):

Stream running but no audio output on LouderESP S3

finally-fancy, 2025-05-10:
Hi there,

I'm using the **LouderESP S3** board. Everything seems to initialize correctly — the amp powers on via I2C, WiFi connects, the MP3 stream is fetched without any errors, and `audio.isRunning()` returns `true`. But: no sound is heard from the speaker.

I'm powering the LouderESP via **12V through the barrel jack** (to ensure the amplifier has proper power), while simultaneously connected via **USB-C** for serial monitoring.

Here's the minimal sketch I'm using for testing:

```cpp
#include <Arduino.h>
#include <Wire.h>
#include <WiFi.h>
#include <Audio.h>

const char* ssid = "mySSID";
const char* pw   = "########";

const int AMP_PWDN = 17;
const uint8_t AMP_I2C = 0x2D;

Audio audio;

void amp_on() {
  pinMode(AMP_PWDN, OUTPUT);
  digitalWrite(AMP_PWDN, LOW);
  delay(5);

  Wire.begin(8, 9);
  Wire.beginTransmission(AMP_I2C); Wire.write(0x00); Wire.write(0x00); Wire.endTransmission();
  Wire.beginTransmission(AMP_I2C); Wire.write(0x02); Wire.write(0x00); Wire.endTransmission();
  Wire.beginTransmission(AMP_I2C); Wire.write(0x03); Wire.write(0x00); Wire.endTransmission();
}

void setup() {
  Serial.begin(115200); delay(5000);
  amp_on();

  WiFi.begin(ssid, pw);
  while (WiFi.status() != WL_CONNECTED) delay(100);

  audio.setPinout(PIN_I2S_SCK, PIN_I2S_FS, PIN_I2S_SD);
  audio.setVolume(21);
  audio.connecttohost("http://st03.dlf.de/dlf/03/128/mp3/stream.mp3");

  if (audio.isRunning()) {
    Serial.println("Audio stream is running");
  } else {
    Serial.println("Audio stream failed to start");
  }
}

void loop() {
  audio.loop();
}
```

my platformio.ini
```
[env:s3dev]
platform = espressif32
board = esp32-s3-devkitc-1
framework = arduino
monitor_speed = 115200

build_flags =
    -DARDUINO_USB_CDC_ON_BOOT=1
    -DCORE_DEBUG_LEVEL=5
    -DBOARD_HAS_PSRAM
    -mfix-esp32-psram-cache-issue
    -D PIN_I2C_SDA=8
    -D PIN_I2C_SCL=9
    -D PIN_I2S_FS=15
    -D PIN_I2S_SCK=14
    -D PIN_I2S_SD=16
```

Is there anything obvious I’m missing that would explain why there’s no sound output?

finally-fancy, 2025-05-10:
**Additional note:**
I had 8 Ω speakers connected and powered the board via the 12 V barrel jack. Later, I noticed the datasheet says:

> **“2×25 W (8 Ω, 1% THD+N) at 22 V”**

Does this mean that I *need* to supply 22 V to get any audible output? The barrel jack is labeled "5 V–26 V", so I assumed 12 V would be sufficient — but perhaps that's too low for meaningful audio output with 8 Ω speakers?

anabolyc, 2025-05-10:
First of all, please make sure your board do not have a warning on the back
about simultaneous power from usb and barrel jack, you may fry tour usb
port (earlier revisions)

Second, you get max power with 26v as noted in specs, but it will work
starting from 5v with lower power output.

Can you please cross check with examples in this repo, I don’t think i2c
communication in your snippet is right. Linked repo has minimal esp-idf
code that should give you quick start

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

finally-fancy, 2025-05-10:
There are two power input available, the one with the barrel jack and the other one with +5V (and the warning). I'm using the the barrel one to provide power to the amplifier(?).

All the samples do not run. I get always a `panic` in the log..

```
 *  Executing task: platformio run --target upload --target monitor --environment louder-esp32s3

Processing louder-esp32s3 (board: lolin_s3_mini; framework: arduino; platform: espressif32)
----------------------------------------------------------------------------------------------------------------------------------------------------
Verbose mode can be enabled via `-v, --verbose` option
CONFIGURATION: https://docs.platformio.org/page/boards/espressif32/lolin_s3_mini.html
PLATFORM: Espressif 32 (6.10.0) > WEMOS LOLIN S3 Mini
HARDWARE: ESP32S3 240MHz, 320KB RAM, 4MB Flash
DEBUG: Current (cmsis-dap) External (cmsis-dap, esp-bridge, esp-builtin, esp-prog, iot-bus-jtag, jlink, minimodule, olimex-arm-usb-ocd, olimex-arm-usb-ocd-h, olimex-arm-usb-tiny-h, olimex-jtag-tiny, tumpa)
PACKAGES:
 - framework-arduinoespressif32 @ 3.20017.241212+sha.dcc1105b
 - tool-esptoolpy @ 1.40501.0 (4.5.1)
 - tool-mkfatfs @ 2.0.1
 - tool-mklittlefs @ 1.203.210628 (2.3)
 - tool-mkspiffs @ 2.230.0 (2.30)
 - toolchain-riscv32-esp @ 8.4.0+2021r2-patch5
 - toolchain-xtensa-esp32s3 @ 8.4.0+2021r2-patch5
LDF: Library Dependency Finder -> https://bit.ly/configure-pio-ldf
LDF Modes: Finder ~ chain, Compatibility ~ soft
Found 34 compatible libraries
Scanning dependencies...
Dependency Graph
|-- esp32-tas5805m-dac @ 0.0.0+20231111144526.sha.aa6b7a1
|-- I2S @ 1.0
Building in release mode
Retrieving maximum program size .pio/build/louder-esp32s3/firmware.elf
Checking size .pio/build/louder-esp32s3/firmware.elf
Advanced Memory Usage is available via "PlatformIO Home > Project Inspect"
RAM:   [=         ]   6.0% (used 19768 bytes from 327680 bytes)
Flash: [===       ]  30.5% (used 399673 bytes from 1310720 bytes)
Configuring upload protocol...
AVAILABLE: cmsis-dap, esp-bridge, esp-builtin, esp-prog, espota, esptool, iot-bus-jtag, jlink, minimodule, olimex-arm-usb-ocd, olimex-arm-usb-ocd-h, olimex-arm-usb-tiny-h, olimex-jtag-tiny, tumpa
CURRENT: upload_protocol = esptool
Looking for upload port...
Auto-detected: /dev/cu.usbmodem2101
Uploading .pio/build/louder-esp32s3/firmware.bin
esptool.py v4.5.1
Serial port /dev/cu.usbmodem2101
Connecting...
Chip is ESP32-S3 (revision v0.2)
Features: WiFi, BLE
Crystal is 40MHz
MAC: 94:a9:90:0c:40:20
Uploading stub...
Running stub...
Stub running...
Changing baud rate to 921600
Changed.
Configuring flash size...
Flash will be erased from 0x00000000 to 0x00003fff...
Flash will be erased from 0x00008000 to 0x00008fff...
Flash will be erased from 0x0000e000 to 0x0000ffff...
Flash will be erased from 0x00010000 to 0x00071fff...
Compressed 15104 bytes to 10430...
Writing at 0x00000000... (100 %)
Wrote 15104 bytes (10430 compressed) at 0x00000000 in 0.3 seconds (effective 431.6 kbit/s)...
Hash of data verified.
Compressed 3072 bytes to 146...
Writing at 0x00008000... (100 %)
Wrote 3072 bytes (146 compressed) at 0x00008000 in 0.1 seconds (effective 367.0 kbit/s)...
Hash of data verified.
Compressed 8192 bytes to 47...
Writing at 0x0000e000... (100 %)
Wrote 8192 bytes (47 compressed) at 0x0000e000 in 0.1 seconds (effective 555.4 kbit/s)...
Hash of data verified.
Compressed 400032 bytes to 225009...
Writing at 0x00010000... (7 %)
Writing at 0x00019102... (14 %)
Writing at 0x00024fa1... (21 %)
Writing at 0x0002fc79... (28 %)
Writing at 0x00035b8d... (35 %)
Writing at 0x0003b447... (42 %)
Writing at 0x00040c82... (50 %)
Writing at 0x00046722... (57 %)
Writing at 0x0004b8cd... (64 %)
Writing at 0x00050fec... (71 %)
Writing at 0x00059247... (78 %)
Writing at 0x00060327... (85 %)
Writing at 0x00067b53... (92 %)
Writing at 0x0006d3cc... (100 %)
Wrote 400032 bytes (225009 compressed) at 0x00010000 in 3.3 seconds (effective 957.3 kbit/s)...
Hash of data verified.

Leaving...
Hard resetting via RTS pin...

Please build project in debug configuration to get more details about an exception.
See https://docs.platformio.org/page/projectconf/build_configurations.html

--- Terminal on /dev/cu.usbmodem2101 | 115200 8-N-1
--- Available filters and text transformations: colorize, debug, default, direct, esp32_exception_decoder, hexlify, log2file, nocontrol, printable, send_on_enter, time
--- More details at https://bit.ly/pio-monitor-filters
--- Quit: Ctrl+C | Menu: Ctrl+T | Help: Ctrl+T followed by Ctrl+H
[  3127][I][generator.hpp:65] init(): [TONE] I2S initialized
[  3133][I][esp32-hal-i2c.c:75] i2cInit(): Initialising I2C Master: sda=8 scl=9 freq=100000
[  3301][I][main.cpp:40] setup(): [MAIN] Setting VOLUME value to: 80
[  3307][I][main.cpp:43] setup(): [MAIN] Setting GAIN value to: -15.5Db
[  3314][I][commandline.hpp:86] register_commands(): [CLI] Registering command: amp
[  3322][I][commandline.hpp:86] register_commands(): [CLI] Registering command: volume
[  3330][I][commandline.hpp:86] register_commands(): [CLI] Registering command: vol
[  3337][I][commandline.hpp:86] register_commands(): [CLI] Registering command: dacmode
[  3345][I][commandline.hpp:86] register_commands(): [CLI] Registering command: eq
[  3353][I][commandline.hpp:86] register_commands(): [CLI] Registering command: mod
[  3360][I][commandline.hpp:86] register_commands(): [CLI] Registering command: gain
[  3368][I][commandline.hpp:86] register_commands(): [CLI] Registering command: mixer
[  3376][I][commandline.hpp:86] register_commands(): [CLI] Registering command: fault
[  3384][I][commandline.hpp:127] init(): [CLI] ESP32 Command Line Interface Ready! Type 'help' for a list of commands.
[  3394][I][commandline.hpp:98] registerCommandHandler(): [CLI] Registering command: tone
Guru Meditation Error: Core  1 panic'ed (Unhandled debug exception).
Debug exception reason: Stack canary watchpoint triggered (loopTask)
Core  1 register dump:
PC      : 0x420199ca  PS      : 0x00060036  A0      : 0x8200d61e  A1      : 0x3fce9ff0
A2      : 0x00000001  A3      : 0x3c04f919  A4      : 0x3c04d110  A5      : 0x00000ce1
A6      : 0x3c04f919  A7      : 0x3c04d2f0  A8      : 0x3fcea000  A9      : 0x3fcea030
A10     : 0x00000ce1  A11     : 0x00000000  A12     : 0x00060e20  A13     : 0x420206cc
A14     : 0x3fcf088c  A15     : 0x00000001  SAR     : 0x00000004  EXCCAUSE: 0x00000001
EXCVADDR: 0x00000000  LBEG    : 0x400556d5  LEND    : 0x400556e5  LCOUNT  : 0xfffffffb
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

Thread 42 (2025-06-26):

Hifi ESP32 S3: No programmable mute control ?

davidandreoletti, 2025-06-26:
Hi @sonocotta

On the [schematics](https://github.com/sonocotta/esp32-audio-dock/blob/e09d5e691483df712a825f8a4eba469b99183b4a/hardware/5-hifi-esp32s3/2409-hifi-esp-g-schematic.pdf):
- PCM5100's mute pin is XSMT.
- XSMT pin seems  physically connected to 3V3 rail on the board.

When:
- XSMT is low, audio is muted
- XSMT is high, audio is unmuted audio.

Hence, when the board is powered on, the PCM5100 is unmuted.

I will be using a rather noisy PAM8046 amp and prefer to mute audio at the dac level for better "silence".

I would like to control when to mute while the Hifi ESP32 S3 board is powered on, what's the recommended approach ?

anabolyc, 2025-06-26:
Hey @davidandreoletti, unfortunately, I didn't implement pin control on the DAC, since it is typically very low noise even when un-muted and no audio feed in.
In your case, I'd advise using PAM8046 mute pin, since this is the place where amplification happens, so it will be responsible for most of the noise (even if you shunt the amp input altogether)

Another consideration, how much voltage are you planning to supply to the PAM8046? Please check what the voltage swing amp expects on the input. Typically, 2.1V RMS of PCM5100 DAC needs a voltage divider before it enters the amp, and the lower leg of it would shunt the amp input when the DAC is off, which should prevent the noise from the DAC once more.

davidandreoletti, 2025-06-26:
@anabolyc

>  advise using PAM8046 mute pin

Got it. Thank you.

> how much voltage are you planning to supply to the PAM8046?

PAM8406's [datasheet](https://docs.rs-online.com/7c06/0900766b81268cf8.pdf) states:
- supply voltage: 2.5V to 5.5V
- input voltage  is stated as -0.3 to VDD+0.3V, which I understand as -0.3 to 5.8V.
- with 4ohm/5W speaker, graph 17 states 5V supply voltage yields 5V 5000mW of output power

PCM5100's [datasheet](https://www.ti.com/lit/ds/symlink/pcm5100.pdf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) states:
-- Full scale output: 2.1V RMS  (ie this output will be AMP's input voltage).
-- Output Logic Level High (0.8*VDD or 0.8*3.3V=2.64V) where 3.3V is the voltage supplied to the PCM5100 by the "Hifi ESP32 S3 board"
-- Output Logic Level Low (0.22*VDD or 0.22*3.3V=0.72V)

So I intend for the PAM8406:
- to receive a 5V supply voltage for each 4ohm/5W speakers to be driven to 5W.
- to not have any voltage divider between the DAC's output voltage and the AMP's input voltage since (PAM8406) -0.3V < (PCM5100) 0.72V < (PCM5100) 2.1V RMS < (PCM5100) 2.64V < (PAM8406) 5.8V

Sounds good ?

> the lower leg of it would shunt the amp input when the DAC is off, which should prevent the noise from the DAC once more.

Would you mind explainning "lower leg of it" in simpler terms please ?

anabolyc, 2025-06-26:
The input voltage indicated absolute maximum input value would not damage by this amp, but it will be heavily distorted if you choose to drive it with a 5V+ signal. Based on the datasheet, gain is 24db (I think), which is around 16x amplification. So it would expect around 0.2..0.3V on the input. If you connect it to PCM5102 without a voltage divider, you should expect heavy distortions (although it would not damage it).

Logic Levels of the PCM5100 are irrelevant here, sice this applies to analog section only.

> Would you mind explainning "lower leg of it" in simpler terms please ?

What you're looking to do

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

If you imagine that PCM5100 output would go floating for some reason (DAC lose power), the lower leg of the voltage divider would shunt the amp input to the ground with 10K, which should be enough to keep it quiet. You can pick different values, of course, just try to find the right ratio to not drive the amp to clipping

Closed 2025-08-24.

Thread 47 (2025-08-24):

Crackling sound for Louder-ESP32S3 on esphome

XtracT, 2025-08-24:
Hello,

I am trying to set up my Louder board using Esphome, but I hear a continuous crackling sound with it. It does not happen when I flash squeezelite-esp32 though. Any ideas how to fix it? I am using the yaml from the repo directly, no modifications.

BR;

/Xtract

anabolyc, 2025-08-24:
Hey @XtracT

I never had this issue, by mrtoy mentioned it as well. Can you please try it with the following change:

```yaml
media_player:
  - platform: speaker
    name: Mediaplayer
    id: louder_mediaplayer
    buffer_size: 100000
```

XtracT, 2025-08-24:
So I tried again this morning, flashing from squeezelite-esp32 to esphome again, and the crackling is gone. I do not know if it could have been some configuration problem (although I am pretty sure I completely erased the device) or the dac not being reset or something, maybe I did not power cycle. In any case, now it works as it should, I was having some issues with squeezelite when I was changing playlists back and forth, but now with esphome it is a simpler setup and it works for my application.

Thanks for the quick response!

anabolyc, 2025-08-24:
Glad it worked out well )

Closed 2025-08-24.

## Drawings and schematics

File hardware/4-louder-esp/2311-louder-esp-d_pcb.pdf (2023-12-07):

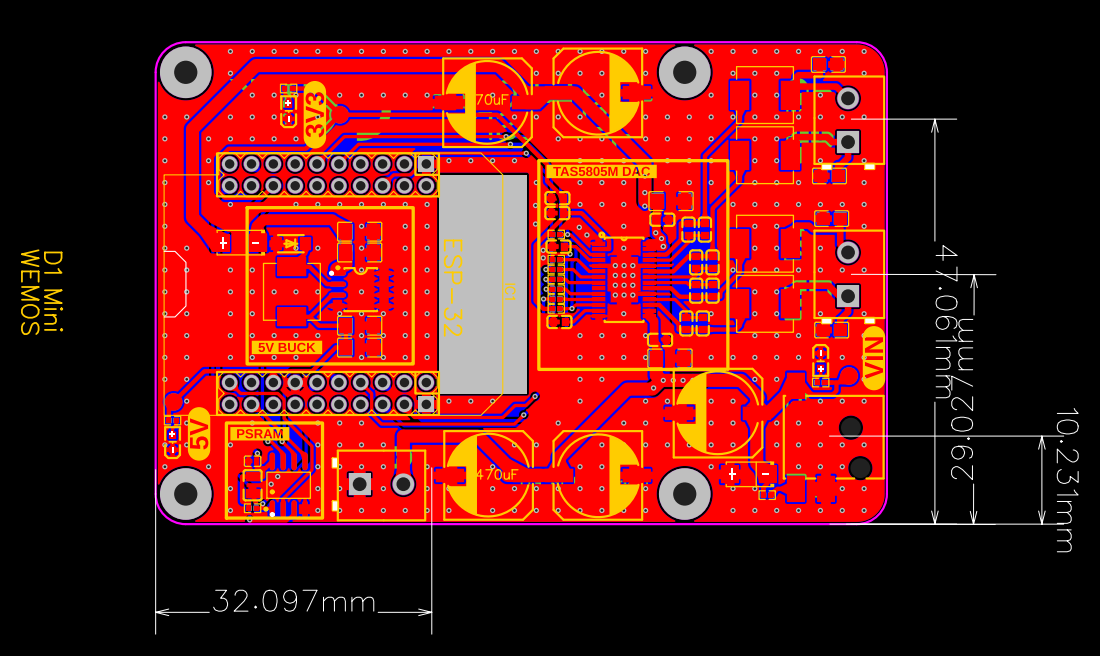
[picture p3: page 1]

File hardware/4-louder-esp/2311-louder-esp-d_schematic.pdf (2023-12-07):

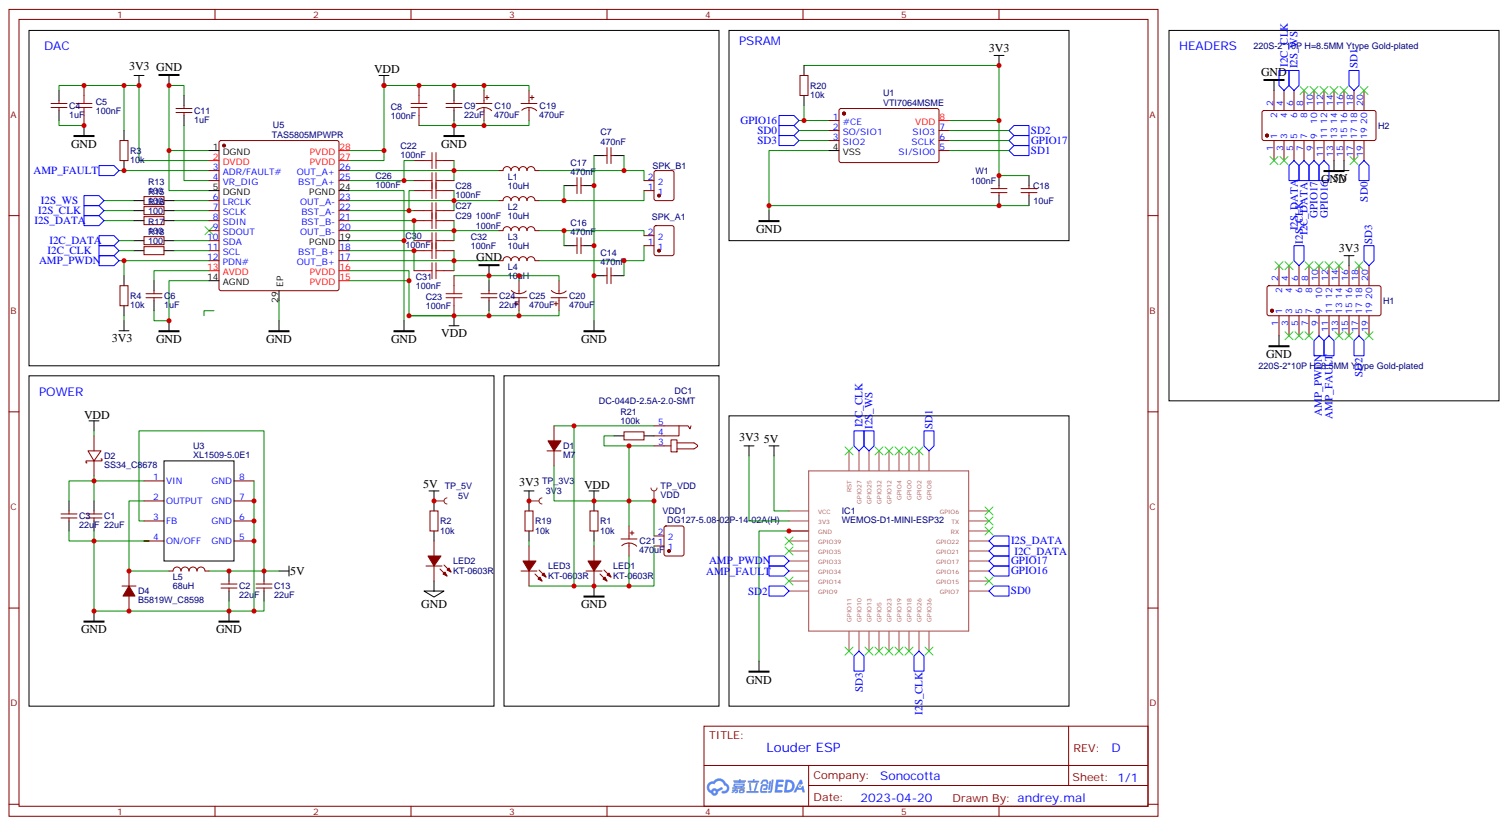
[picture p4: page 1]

Drawn By: andrey.mal

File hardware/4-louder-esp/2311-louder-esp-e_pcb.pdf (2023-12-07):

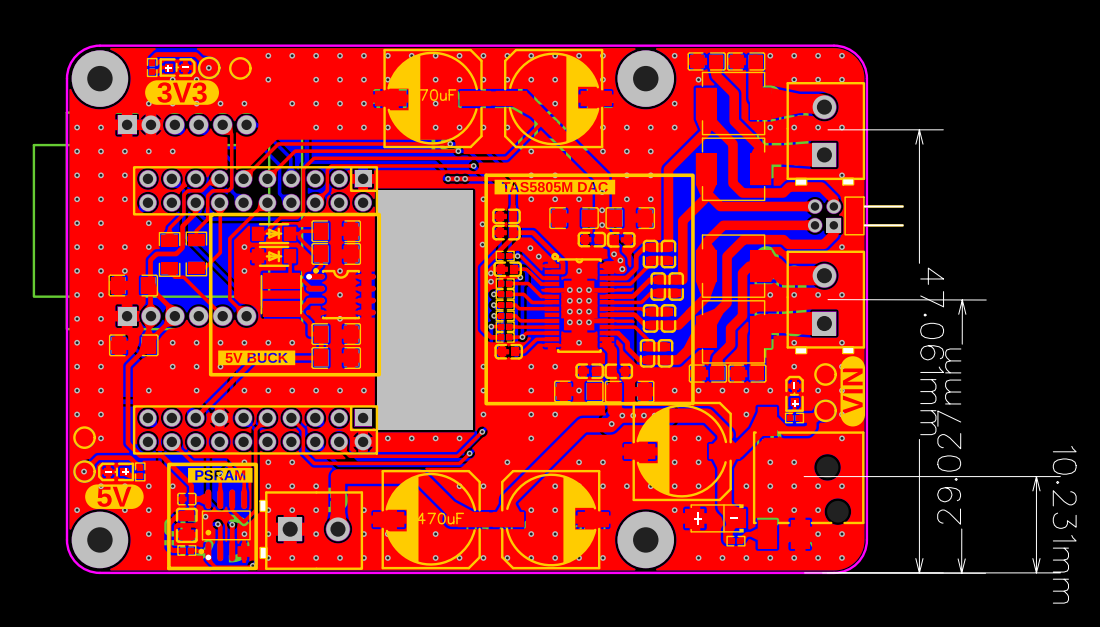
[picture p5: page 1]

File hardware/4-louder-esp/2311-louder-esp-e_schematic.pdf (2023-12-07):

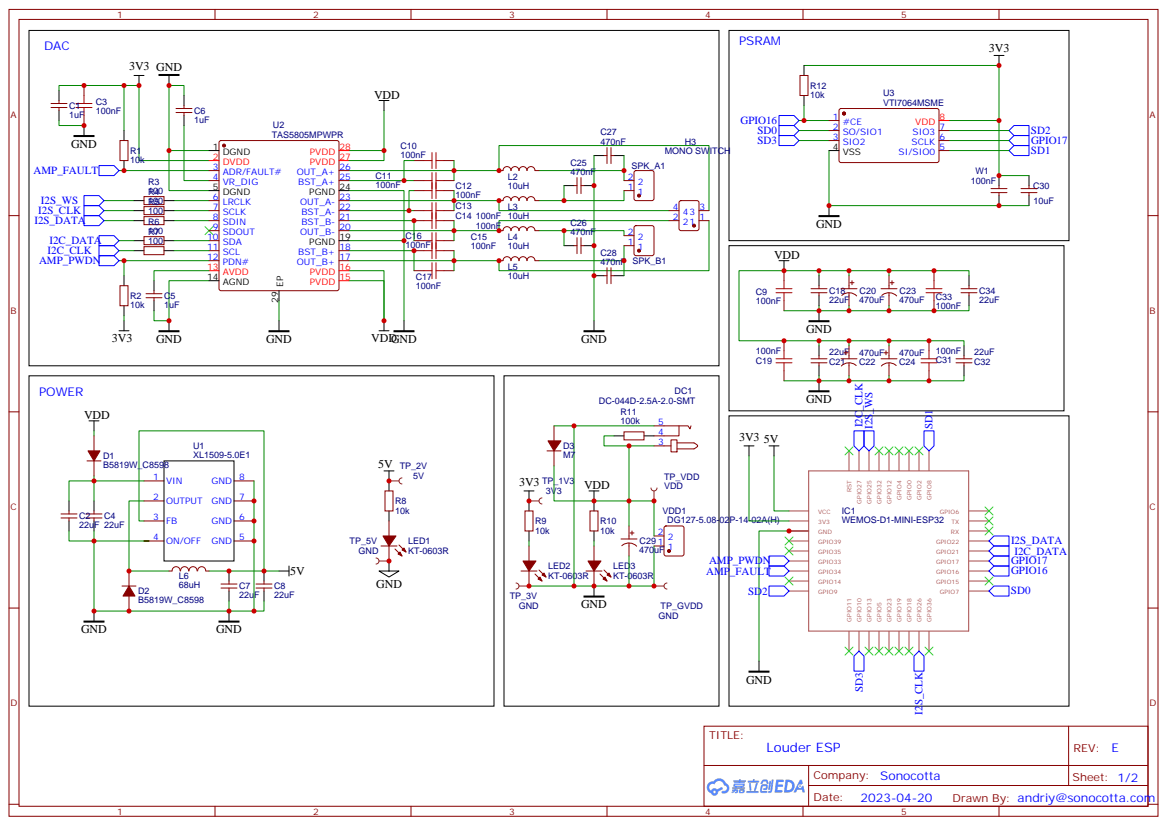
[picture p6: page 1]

Drawn By: andriy@sonocotta.com

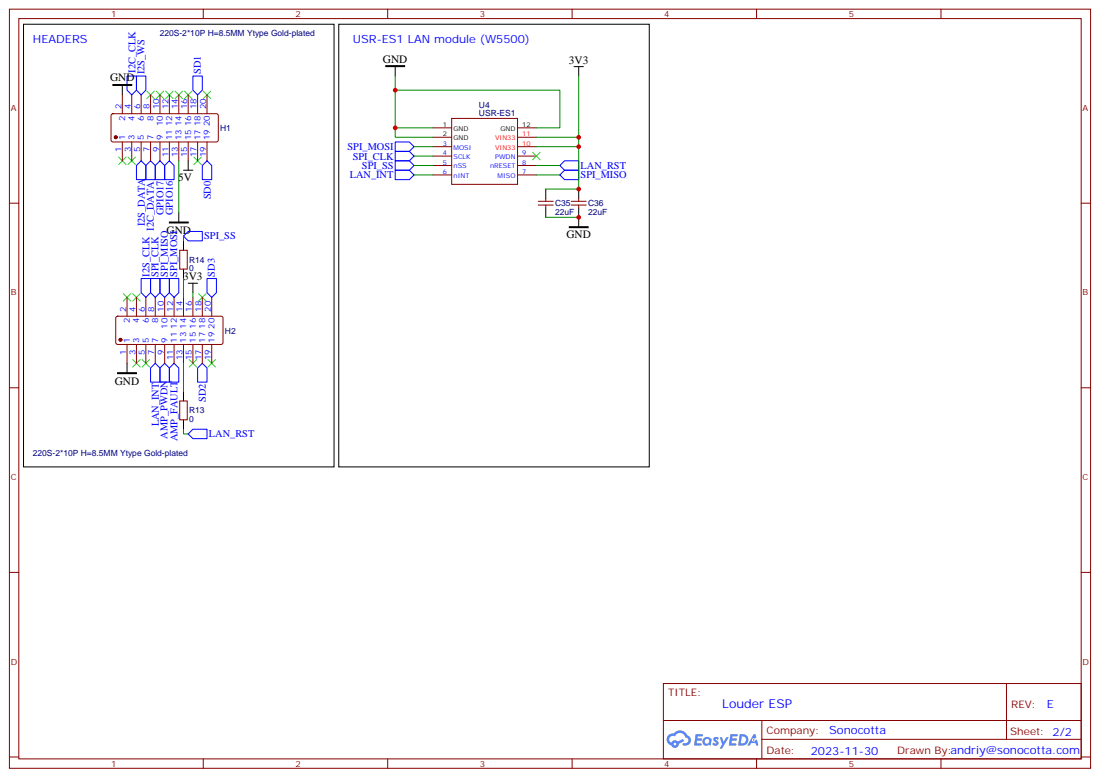
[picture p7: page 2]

Drawn By:andriy@sonocotta.com

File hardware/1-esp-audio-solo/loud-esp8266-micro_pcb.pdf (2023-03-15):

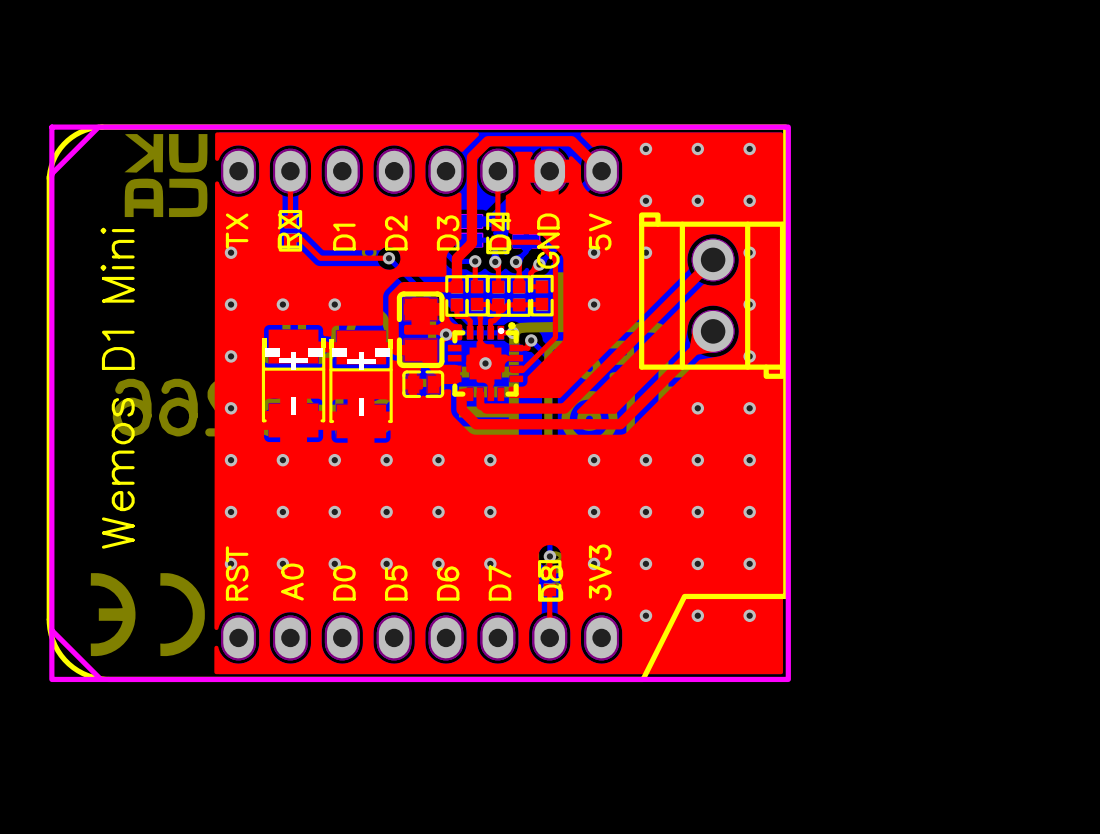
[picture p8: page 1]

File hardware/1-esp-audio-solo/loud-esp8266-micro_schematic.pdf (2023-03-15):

## CONNECTION

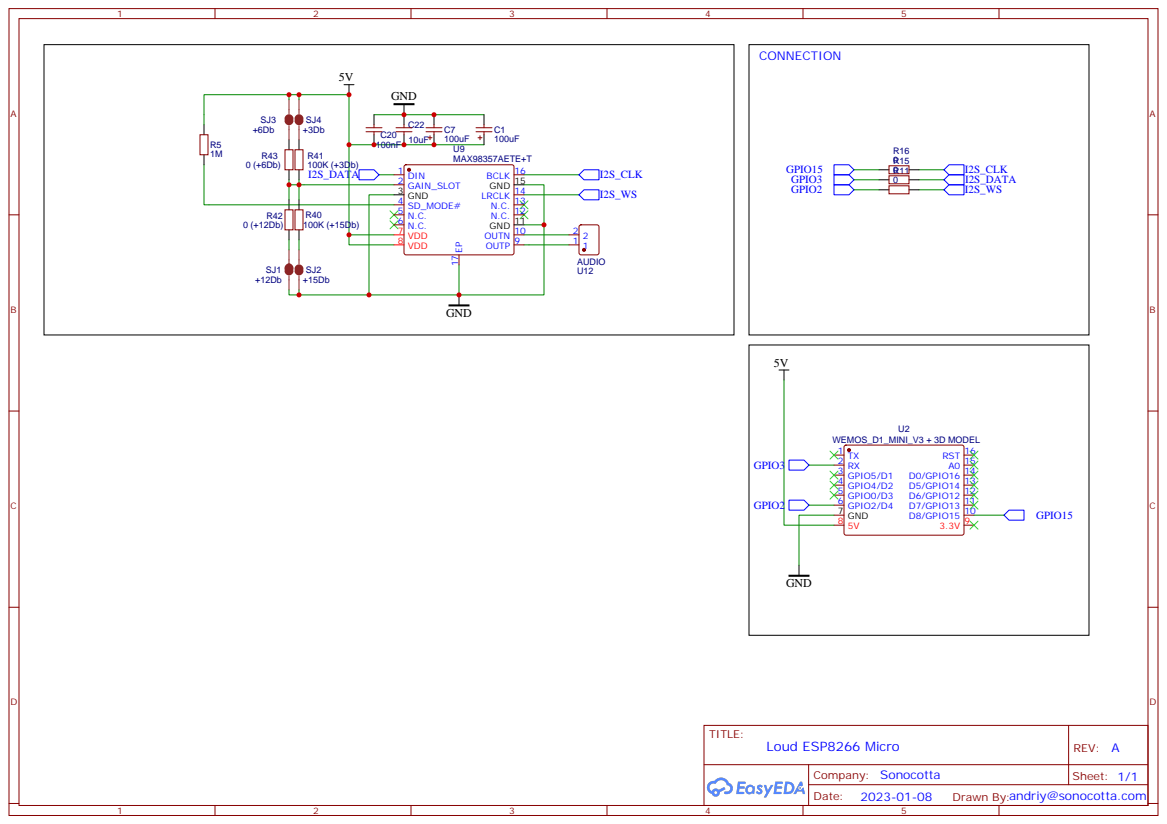
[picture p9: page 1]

Drawn By:andriy@sonocotta.com

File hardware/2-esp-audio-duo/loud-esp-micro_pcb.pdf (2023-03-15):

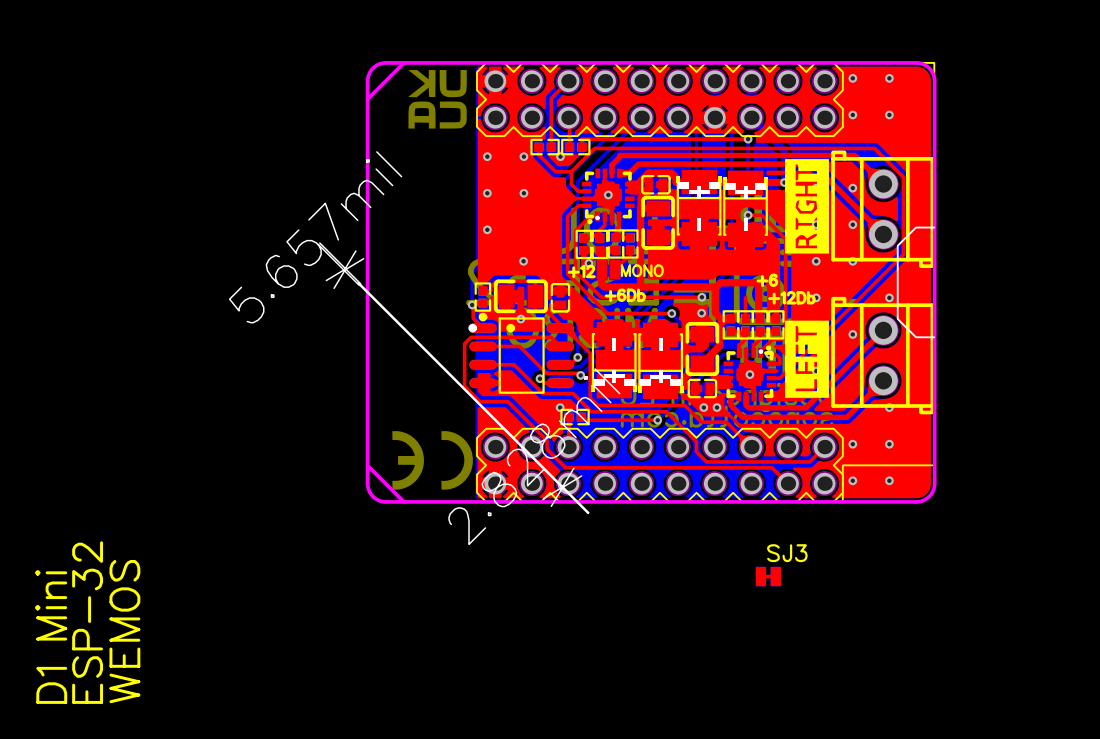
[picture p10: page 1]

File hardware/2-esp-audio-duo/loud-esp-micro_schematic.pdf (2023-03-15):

## PSRAM RIGHT CHANNEL

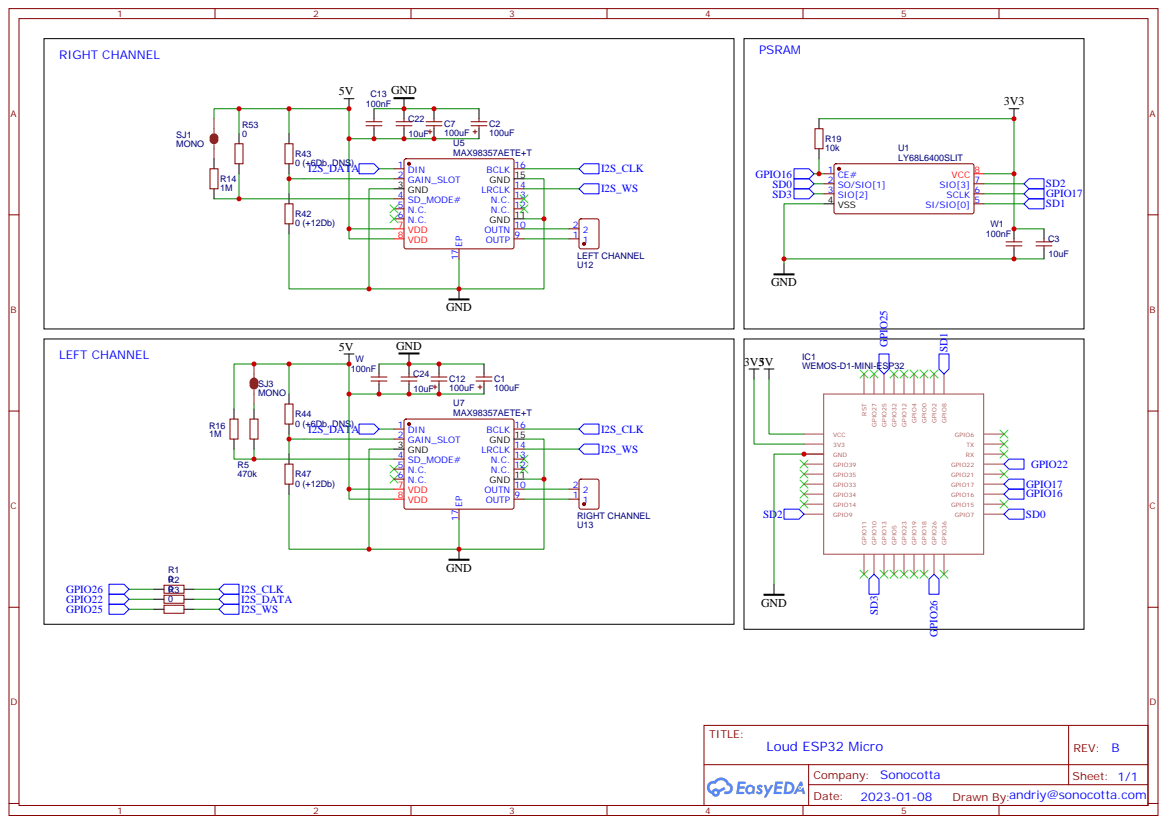
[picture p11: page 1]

Drawn By:andriy@sonocotta.com

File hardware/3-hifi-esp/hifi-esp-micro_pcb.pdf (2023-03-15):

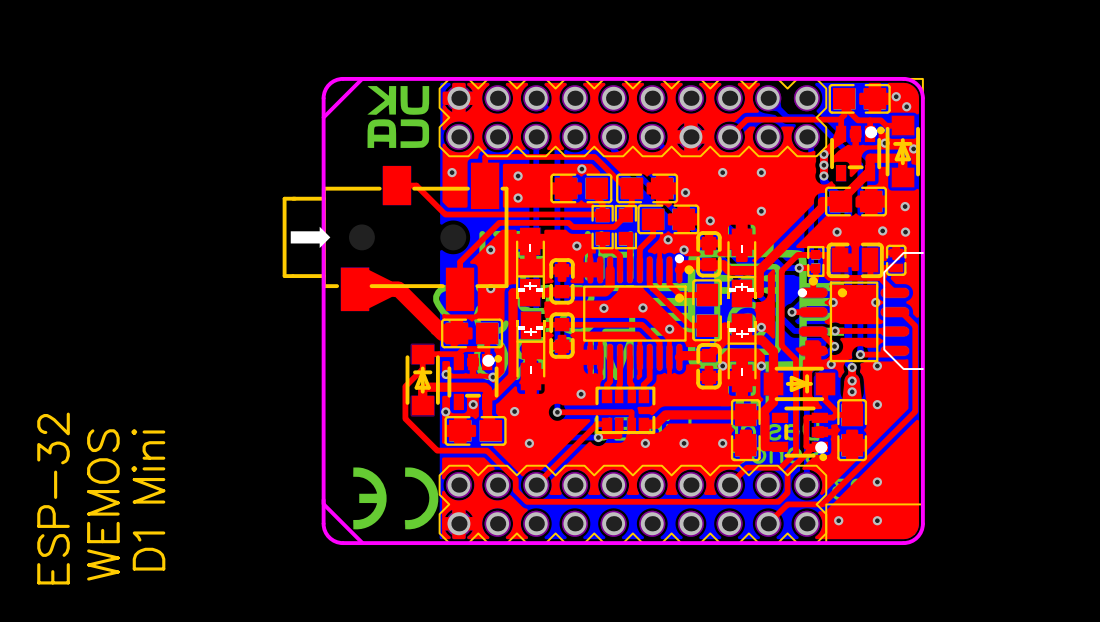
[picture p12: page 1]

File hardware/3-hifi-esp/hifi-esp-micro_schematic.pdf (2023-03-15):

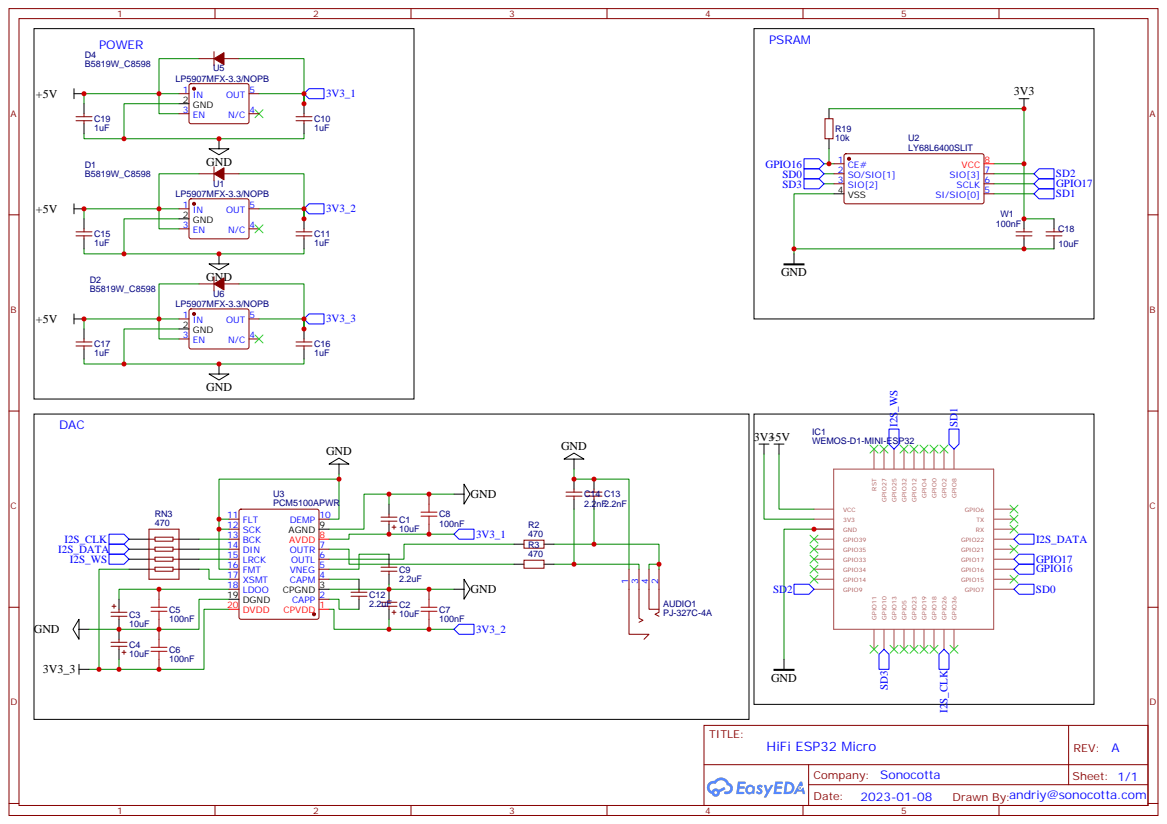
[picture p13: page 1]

Drawn By:andriy@sonocotta.com

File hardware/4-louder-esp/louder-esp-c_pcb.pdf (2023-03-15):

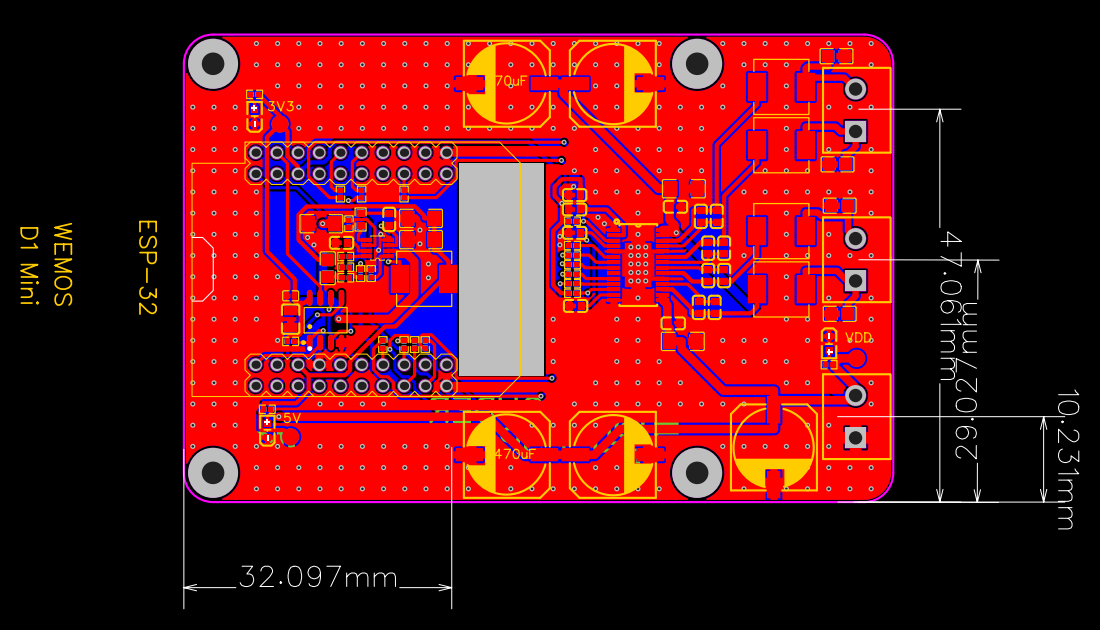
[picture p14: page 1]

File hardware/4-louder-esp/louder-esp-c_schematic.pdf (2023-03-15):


Drawn By: andrey.mal

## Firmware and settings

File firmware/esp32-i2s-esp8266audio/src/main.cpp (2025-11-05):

#include <Arduino.h>

#define filesystem LittleFS

#ifdef CONFIG_DAC_TAS5805M
#include <Wire.h>
#include <tas5805m.hpp>
#include <Ticker.h>
tas5805m Tas5805m(&Wire);
Ticker ticker;
#endif

#ifdef CONFIG_DAC_PCM5122
#include <Wire.h>
#include "PCM51xx.h"
PCM51xx Pcm5122(Wire);
#endif

const char *TAG = "MAIN";

#include "player.hpp"
Player player;

#include "playlist.hpp"
Playlist playlist;

#include <commandline.hpp>
CommandLine cmd;

#ifdef CONFIG_DAC_TAS5805M
void ticker_callback()
{
  TAS5805M_FS_FREQ freq;
  uint8_t ratio;
  Tas5805m.getFsFreq(&freq);
  Tas5805m.getBckRatio(&ratio);

  TAS5805M_CTRL_STATE state;
  Tas5805m.getPowerState(&state);

  bool is_r_muted, is_l_muted;
  Tas5805m.getAutomuteState(&is_r_muted, &is_l_muted);

  ESP_LOGI(TAG, "FS Frequency: %s, BCK ratio: %d; Power state: %s; Automute: R: %d, L: %d",
           tas5805m_map_fs_freq(freq), ratio,
           tas5805m_map_amp_state(state),
           is_r_muted, is_l_muted);

  TAS5805M_FAULT fault;
  Tas5805m.getFaultState(&fault);
  Tas5805m.decodeFaults(fault);

  if (fault.err0 || fault.err1 || fault.err2 || fault.ot_warn)
  {
    ESP_LOGI(TAG, "Clearing fault states");
    Tas5805m.clearFaultState();
  }
}
#endif

void init_cmd_line()
{
  cmd.init();

  cmd.addCommand("play", "Play the current track", [](int argc, char **argv)
                 { return player.play(); });

  cmd.addCommand("pause", "Pause the current track", [](int argc, char **argv)
                 { return player.pause(); });

  cmd.addCommand("resume", "Resume the current track", [](int argc, char **argv)
                 { return player.resume(); });

  cmd.addCommand("stop", "Stop the current track", [](int argc, char **argv)
                 { return player.stop(); });

  cmd.addCommand("next", "Play the next track", [](int argc, char **argv)
                 { return player.next(); });

  cmd.addCommand("prev", "Play the previous track", [](int argc, char **argv)
                 { return player.prev(); });

  cmd.addCommand("list", "List all tracks", [](int argc, char **argv)
                 { return playlist.list(); });

  cmd.addCommand("loop", "Loop the current track", [](int argc, char **argv)
                 { return player.toggleLoop(); });

  cmd.startLoopAsync();
}

void setup()
{
  WiFi.mode(WIFI_OFF);

  Serial.begin(SERIAL_BAUD);
  Serial.println(F("Starting up...\n"));

  esp_log_level_set("*", ESP_LOG_DEBUG);

  ESP_ERROR_CHECK(playlist.init());

  // This should start I2S clock
  ESP_ERROR_CHECK(player.init());

#ifdef CONFIG_DAC_TAS5805M
  Wire.begin(PIN_I2C_SDA, PIN_I2C_SCL);
  // This will send default DSP init sequence
  Tas5805m.init();

  // alternative way is to run 'fault on' command
  // ticker.attach_ms(10000, ticker_callback);

  // I2S must be initialized by this time for DSP settings to apply
  uint8_t newVolume = 78; //(-15 Db default volume)
  ESP_LOGI(TAG, "Setting VOLUME value to: %d", newVolume);
  ESP_ERROR_CHECK(Tas5805m.setVolume(newVolume));

  ESP_LOGI(TAG, "Setting GAIN value to: -15.5Db");
  ESP_ERROR_CHECK(Tas5805m.setAnalogGain(TAS5805M_MIN_GAIN));
#endif

#ifdef CONFIG_DAC_PCM5122
  Wire.begin(PIN_I2C_SDA, PIN_I2C_SCL);
  // This will send default DSP init sequence
  Pcm5122.begin(PCM51xx::SAMPLE_RATE_44_1K, PCM51xx::BITS_PER_SAMPLE_16);
  // begin() returns false currently, but DAC is working. Why?
  #ifdef PIN_PCM5122_MUTE
  pinMode(PIN_PCM5122_MUTE, OUTPUT);
  digitalWrite(PIN_PCM5122_MUTE, HIGH); // unmute
  #endif
#endif

  ESP_ERROR_CHECK(player.play());
  init_cmd_line();
}

void loop()
{
  player.loop();
}

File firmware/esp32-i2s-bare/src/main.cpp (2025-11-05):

#include <Arduino.h>

const char *TAG = "MAIN";

#ifdef CONFIG_DAC_TAS5805M
#include <tas5805m.hpp>
tas5805m Tas5805m(&Wire);
#endif

#ifdef CONFIG_DAC_PCM5122
#include <Wire.h>
#include "PCM51xx.h"
PCM51xx Pcm5122(Wire);
#endif

#include "generators/generator.hpp"
SquareGenerator squareGenerator;
SineGenerator sineGenerator;

#include <commandline.hpp>
CommandLine cmd;

#include "commands/squaretone.hpp"
SquareToneCommand toneCmd1;

#include "commands/sinetone.hpp"
SineToneCommand toneCmd2;

void setup()
{
  Serial.begin(SERIAL_BAUD);
#if ARDUINO_USB_CDC_ON_BOOT
  delay(3000);
#else
  delay(500);
#endif

  // esp_log_level_set("*", ESP_LOG_DEBUG);

  // initializes I2S, important!
  squareGenerator.init();

#ifdef CONFIG_DAC_TAS5805M
  Wire.begin(PIN_I2C_SDA, PIN_I2C_SCL);
  // This will send default DSP init sequence
  Tas5805m.init();

  // I2S must be initialized by this time for DSP settings to apply
  uint8_t newVolume = 100; // 0...124, where 100 is max voltage swing without risk of clipping (assuming analog gain is set appropriately)
  ESP_LOGI(TAG, "Setting VOLUME to: %d%", newVolume);
  ESP_ERROR_CHECK(Tas5805m.setVolume100(newVolume));

  // If you power from onboard USB, you must set gain to minimum to avoid clipping
  // ESP_LOGI(TAG, "Setting GAIN value to: -15.5dB");
  // ESP_ERROR_CHECK(Tas5805m.setAnalogGain(TAS5805M_MIN_GAIN));

  // If you power from external 15V+ supply, you can set gain to max
  ESP_LOGI(TAG, "Setting GAIN value to: 0dB");
  ESP_ERROR_CHECK(Tas5805m.setAnalogGain(TAS5805M_MAX_GAIN));
#endif

#ifdef CONFIG_DAC_PCM5122
  Wire.begin(PIN_I2C_SDA, PIN_I2C_SCL);
  // This will send default DSP init sequence
  Pcm5122.begin(PCM51xx::SAMPLE_RATE_44_1K, PCM51xx::BITS_PER_SAMPLE_16);
  // begin() returns false currently, but DAC is working. Why?
  #ifdef PIN_PCM5122_MUTE
  pinMode(PIN_PCM5122_MUTE, OUTPUT);
  digitalWrite(PIN_PCM5122_MUTE, HIGH); // unmute
  #endif
#endif

  cmd.init();
  cmd.registerCommandHandler(&toneCmd1);
  cmd.registerCommandHandler(&toneCmd2);

  // Spin up tone automatically for demo purposes
  // sineGenerator.setFrequency(100);
  // sineGenerator.setAmplitude(14);
  // sineGenerator.start();

  // squareGenerator.setFrequency(1000);
  // squareGenerator.setAmplitude(14);
  // squareGenerator.start();

}

void loop()
{
  cmd.loop();
}

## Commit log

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2023-11-16 update deps version to fix build (#2)
    * Added samle web-radio player project
    * Added squeezelite-esp32 instructions
    ---------
    [main.cpp]
2023-11-29 Added TAS5805M examples to change volume, gain, reset faults, switch to mono mode
    [main.cpp]
2024-05-07 Features/s3 board support (#6)
    * Added Louder-ESP32S3 configurations
    * Boot freeze issues on the ESP32S2
    * Added PSRAM usage to buffer example (web radio)
    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
    [main.cpp]
2024-05-20 Added esp32-s3 binaries and configs (#7)
    * Added S3 binaries and configs
    * Upgrade esp-web-tools version
    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
2024-09-19 Generation 2 boards docs (#17)
    * updated docs and hw files
    * Update README.md
    * Update README.md
    * toc update
    * Update README.md
    * Update README.md
    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
2024-12-16 feat(esphome): turn on/off Amp on media_player usage, add manufacturer info (#20)
    * turn on amp on start playing audio
    * turn off amp after no sound playing
    * add project (manufacturer and device name) and comment
2024-12-17 ESPHome - Add maximum volume feature to louder ESP (#21)
    * ESPHome - Add optional maximum volume feature to Louder-ESP32
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2025-02-17 updated squeezelite-esp32 binaries to the latest release (#33)
    * updated squeezelite-esp32 binaries to the latest release
    * updated S3 bins
    * added S3 sdkconfig
    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
2025-03-27 Updated examples for new version of the esp32-tas5805m-dac lib (#37)
    * Updated examples
    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
2025-03-31 Added Amped-ESP32 files (#38)
    * Added hw files
    * Added amped-esp32 squeezelite installer files
    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
2025-08-10 Features/esphome component update (#43)
    * Added recent hardware files
    * Updated esphome configs
    * updated readme
    * Added new 3d-printed design
    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
2025-08-13 Adjustments with latest driver updates (#45)
    * Adjustments with driver updates
    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
2025-08-21 Added sine wave generator (for testing purposes) (#46)
    * Added sine wave generator (for testing purposes)
    * build fix
    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
    [main.cpp]
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2025-10-16 Added pinout updates for hiFi-esp32 (#54)
    * Added pinout updates for hiFi-esp32
    * Replace images in README
    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
2025-10-24 updated amped-esp32 settings with amp en pin (#56)
    * updated amped-esp32 settings with amp en pin
    * Added Rev H docs
    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
2025-11-05 Features/pcm5122 support and docs (#59)
    * updated 5122 examples
    * Added hardware files. Updated code examples to work with HiFi-ESP32S3-Plus
    * Added HiFi-ESP32 Plus readme updates
    * Added pinout
    * Build error
    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
    [main.cpp]
2025-11-28 Added hardware design files (Amped-ESP32 and HiFi-ESP32-Plus) (#63)
    * Added hardware design files
    * Update README with HiFi-ESP32 Plus details
    Added details about the HiFi-ESP32 Plus and Amped-ESP32 Plus, including features and specifications.
    * Upd ToC
    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
    [2511-amped-esp32-h1-bom.csv, 2511-amped-esp32-s3-j-bom.csv, 2511-hifi-esp32-f4-bom.csv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]
2025-12-12 Features/documentation updates (#66)
    * Added new case links, draft of reworked PBTL section
    * Added new case links, draft of reworked PBTL section
    * Fix typos and enhance PBTL mode documentation
    Correct typos and improve clarity in PBTL mode section of README.
    * Enhance README with bridging outputs and connections
    Updated the README to include a table for bridging outputs and added images for physical connections in PBTL mode.
    * Update speaker usage recommendations formatting
    Removed bullet points from speaker usage recommendations.
    * power calculation docs
    * fix text
    * fix
    * wip
    * mistype
    * wip
    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
2025-12-12 Features/amped-esp32-s3 configs for esphome (#67)
    * added amped-s3 esphome configs
    * Added config links to the README
2025-12-17 Added settings and manifests for hifi-esp32-plus and amped-esp32-s3 (#68)
    * Added settings and manifests for hifi-esp32-plus and amped-esp32-s3
    * Mistype
    * Updated docs
    * updare dac en pin on amped
    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
2025-12-19 Added HiFi-ESP32-Plus esphome yaml configs and updated docs (#69)
    * Added yaml config and updated docs
    * upd yamls
    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
2025-12-21 Features/squeezelite esp32 installer update (#64)
    * moved sdkconfig
    Add squeezelite-esp32 submodule under firmware
    Added build pipeline
    trigger fix
    WIP
    WIP
    WIP
    WIP
    WIP Fri Dec 12 10:46:34 CET 2025
    WIP Fri Dec 12 10:54:25 CET 2025
    WIP Fri Dec 12 11:01:32 CET 2025
    WIP Fri Dec 12 11:12:45 CET 2025
    WIP Fri Dec 12 11:19:25 CET 2025
    WIP Fri Dec 12 11:26:03 CET 2025
    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
2026-01-10 Fix flash ram size for S3 chips (#72)
    * update flash size & min esphome version for S3-based boards
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2026-01-25 Fixed sendspin configuration for hifi-esp32-s3-plus
    Removed on_boot configuration for media player and added globals for current_volume and announcement_triggered.
2026-01-25 Fixed sendpin for amped-esp32-s3
2026-02-11 Added plus models configs (#84)
    * Added plus models configs
    * Add built squeezelite binaries and latest templates (latest)
    * Updated settings
    * Add built squeezelite binaries and latest templates (latest)
    * hw files overhaul
    * Added plus boards hardware files
    * Add built squeezelite binaries and latest templates (latest)
    * Updated pinouts, added sendspin configs for plus boards
    * Add Esparagus boards note to README
    Added a note about Esparagus boards and linked to the sister repository.
    * Fix formatting of warning message in README
    * updated configs for amped-esp32-plus
    * test build pipeline
    * Updated pipelines
    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
    [2511-amped-esp32-h1-bom.csv, 2511-amped-esp32-s3-j-bom.csv, 2511-hifi-esp32-f4-bom.csv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]
2026-02-16 Refactor README for Amped-ESP32 Plus details
    Updated product names and descriptions for clarity. Fixed formatting issues and removed redundant sections.
2026-02-16 Enhance README with product highlights and new models
    Added emphasis to product names and introduced Louder-ESP32 Plus and Amped-ESP32 Plus sections with details on their features.
2026-02-17 Fix broken ESPHome config links in README (#91)
    ESPHome YAML files were reorganized into numbered subdirectories
    (e.g., 1-hifi-esp32/, 3-louder-esp32/) but README links still
    pointed to the old flat paths under firmware/esphome/.
2026-02-18 Added 32-bit builds alongside with 16-bit (#88)
    * Added 32-bit builds alongside with 16-bit
    * Split templates into 16-bit and 32-bit versions. Updated installer
    * Added loud-esp display settings
    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
    [loud-esp-settings.csv]
2026-02-26 ESPHome configs pulled from packages (#94)
    * Added hifi-esp32 configs for idf media-player and snapclient
    * Added hifi-esp32-sendspin configs
    * Added louder-esp32 configs
    * Added hifi-esp32-plus boards + refactoring
    * Added amped-esp32 configs (not tested)
    * Added loud-esp32 configs (not tested)
    * refactored Louder-ESP32-Plus configs (not tested)
    * Fix build errors
    * Final refactoring for all boards except Louder-ESP32-Plus and Amped-ESP32-Plus
    * Fixed sendspin config
    * Fixed build errors. Added readme
    * Updated main readme
    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
2026-03-05 Disable I2S Clock Fault binary sensor (#105)
    Comment out I2S Clock Fault sensor due to its limited utility.
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2026-03-18 Correct pinout for Amped-ESP32-plus
2026-03-23 Updated hifi-esp32-s3-plus pinout (#111)
    [hifi-esp32s3-plus-settings.csv]
2026-04-02 Features/loud esp32 update (#114)
    * Added hardware files for newer boards
    * Updated loud-esp32 settings and other fixups
    * trigger manifest rebuild
    * Update images in README for ESP32 models
    Updated images for Loud-ESP32 and added new images for ESP32-S3.
    * Added community project section
    * Add images to project links in README
    Updated project links to include images in the README.
    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
    [2601-amped-esp32-plus-b-bom.csv, 2602-amped-esp32s3-plus-c-bom.csv, 2602-louder-esp32-plus-b-bom.csv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]
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2026-04-12 Update README.md (#122)
    Updated wording of how to flash S3 variant. The current wording is confusing. I thought it meant you release flash button before releasing reset button, which does not work. What actually works (and what original author intended) is hold flash button while doing only a momentary press of reset button, then release flash last. I think my proposed wording better explains this
2026-04-17 Add tas58xx dac config refresh_eq override for snapclient (#120)
    * Add dac refresh_eq override
    * Add new snapclient PR for louder-esp32
    * Set DAC EQ Mode on snapclient play
    * Set DAC EQ Mode on snapclient play
    * suppress delay
    * Added dac events, updated eq enable event. Updated all tas58xx dac configs
    * moved eq_enable trigger to addon file, so it can be used with basic DACs
    * moved external Dac to addon file
    * Fixed addon and updateed hifhi/load board defintions
    * Added remaining board configs
    * Build fixes
    * make sure dac is enabled and wait a short time before applying eq mode
    * Removed legacy boards from validation pipeline
    * Update snapclient tas58xx addon
    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
2026-05-07 Added squeezelite-esp32 configs and updated installer (#134)
    * Added squeezelite-esp32 configs and updated installer
    * Added Loud-ESP32-Plus esphome configs
    * Updated esphome remote links
    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
    [loud-esp32-plus-settings.csv, loud-esp32s3-plus-settings.csv]
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2026-06-11 Added latest boards hardware files
    [2601-loud-esp32s3-plus-a-bom.csv, 2601-louder-esp32s3-plus-a-bom.csv, 2605-amped-esp32s3-k0-bom.csv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]
2026-06-22 Added new boards esphome configs. Updated readme (#150)
    * Added new boards esphome configs. Updated readme
    * Added mini 3d enclosure
    * moved 3d files
    * Fixed build pipeline
    * Updated configs for pcm5122-based boards
    * Fixed for loud-esp32-plus boards
    * Restored main branch ref
    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
    [2605-louder-esp32s3-plus-pd-c-bom.csv, Louder-ESP32-mini-shell.stl]
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2026-07-10 Revise power adapter details and fix typos
    Updated power adapter information and corrected typos in the README.
2026-07-23 Added mini/pro configs. Disabled telnet and btsink on Louder S3 by default (#160)
    * Added mini/pro configs. Disabled telnet and btsink on Louder S3 by default.
    * Added settings binaries build step
    * Updated remaining S3 boards
    * Added PBTL mode into dac_controlset for mini
    * Add built squeezelite binaries, latest templates and NVS settings binaries
    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
    [amped-esp32s3-plus-settings.csv, amped-esp32s3-settings.csv, hifi-esp32s3-plus-settings.csv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]
2026-07-24 Added louder-esp32-mini shell files
    [Louder-ESP32-mini-M-shell.stl, Louder-ESP32-mini-S-shell.stl]
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2026-08-13 Added mini Louder-ESP32-mini hardware files
    [2605-louder-esp32-mini-a-bom.csv, 2605-louder-esp32-mini-pickandplace.csv, 2606-louder-esp32-mini-pd-b-bom.csv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]
2026-08-14 Added missing hw files
    [2606-amped-esp32-plus-d0-bom.csv, 2606-amped-esp32s3-plus-e0-bom.csv]
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2026-09-03 Added eth config to all squeezelite settings files by default (#173)
    * Added eth config to all squeezelite settings files by default
    * Updated settngs binaries
    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
    [amped-esp32-plus-settings.csv, amped-esp32-settings.csv, amped-esp32s3-plus-settings.csv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]
2026-09-09 Added Louder ESP32 H7 hardware files #176
    [2508-louder-esp32-h7-bom.csv]
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2026-09-18 Removed wifi-credentials from squeezelite settings binary (#184)
    * Removed wifi-credentials from squeezelite settings binary
    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
    [common-esp-nvs.csv]
2026-09-30 Added case files and readme (#189)
    * Added case files and readme
    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
    [Amped_Case.scad, Louder_Display.scad]
2026-10-08 Replaced custom PCM5122 component with upstream version (#190)
    * Replaced custom component with upstream version
    * Fix deprecation warning
    * Sync with esparagus repo updates
    * Fix validation build error
    * Excluded legacy boards from build validation
    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
2026-10-12 Add Louder ESP32 S3 Voice Assist config (#196)
    * Create louder-esp-32-s3-idf-sendspin-voice.yaml
    add voice assist version
    * Update louder-esp-32-s3-idf-sendspin-voice.yaml
    add ref'd mic stuff
    * Update louder-esp-32-s3-idf-sendspin-voice.yaml
    add mic i2s
    * Rename louder-esp-32-s3-idf-sendspin-voice.yaml to louder-esp32-s3-idf-sendspin-voice.yaml
    update filename
    * Update louder-esp32-s3-idf-sendspin-voice.yaml
    * Update louder-esp32-s3-idf-voice-assist.yaml
    * Rename louder-esp32-s3-idf-sendspin-voice.yaml to louder-esp32-s3-idf-voice-assist.yaml
    fix file name
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2026-10-23 Added voice-assist config for the Loud-ESP32-S3 board (+pinout fix) (#200)
    * Added voice-assist config for the Loud-ESP32-S3 board (+pinout fix)
    * removed dead config
    * Added missing voice-assist configs (untested)
    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
2026-10-29 Switched to esphome 2026.10.0, added sendspin model/manufacturer tags (#203)
    * Switched to esphome 2026.10.0, added sendspin model/manufacturer tags
    * Fix sendspin TFT artwork, verify packages against the branch under test
    sendspin-addon-tft.yaml pinned `sendspin` and `generic_image` to
    github://pr#16057, an upstream WIP PR closed unmerged on 2026-07-30.
    That override replaced core's sendspin component with a pre-July
    snapshot, so 2026.10.0's api_connection.cpp failed to compile against
    it:
    error: 'global_sendspin_hub' is not a member of 'esphome::sendspin_'
    Drop the pin and move the two artwork entries onto core's built-in
    Sendspin artwork (`image: - platform: sendspin`), matching wha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
2026-11-03 Add errata for Amped-ESP32-Plus wrong DAC output filter caps (#210)
    * Add errata for Amped-ESP32-Plus wrong DAC output filter caps
    A batch of rev D0/E0 TPA3118 boards was assembled with ~27uF caps at
    C65/C73 instead of 2.2nF, causing muffled, quiet audio (see #204).
    Document detection, affected shipping dates and the fix (remove caps),
    and link it from the README.
    * Fix capacitor values and DAC model in errata
    Corrected capacitor values and descriptions for the Amped-ESP32-Plus DAC output filter issue, updating from 27µF to 22µF and clarifying the DAC model.
    * Tidy errata image layout and capacitor values
    Put comparison photos s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
2026-11-04 Enable Sendspin static delay adjustment and replace placeholder device names (#212)
    * Enable static_delay_adjustable on Sendspin media source
    The option defaults to false, so the device reports a static delay of 0
    and does not offer SET_STATIC_DELAY, leaving the server unable to adjust it.
    * Replace esphome-web-* placeholder device names in dev configs
    Dev configs hardcoded leftover names such as esphome-web-e1b35c, so every
    unit built from them identified as that name and shared one hostname. Use the
    board name from the matching factory config instead. Factory images and
    dashboard-adopted devices are unaffected, as they set their o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
2026-11-12 Added pcm5122 test firmware update, +flash tool (#216)
    * Added pcm5122 test firmware update, +flash tool
    * Fix Build Examples workflow path filters
    Path filters are matched against repo-relative paths without a ./ prefix
    and need a glob to match folder contents.
    * Update Build Examples workflow to Python 3.12 and current actions
    Python 3.9 is no longer available on ubuntu-latest runners; also bump
    checkout/cache/setup-python to supported major versions.
    ---------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
2026-11-13 Unmute DAC/amp at the start of announcements played from idle (#218)
    Fixes sonocotta/esp32-audio-dock#213: an announcement played while nothing
    else was playing stayed silent, because the DAC/amp was never unmuted.
    Two causes:
    - sendspin-addon-dac-mute.yaml and sendspin-addon-amp-unmute.yaml had no
    on_announcement handler, so only on_play unmuted the output.
    - Even where an addon did hook on_announcement (dac-enable, the
    media-player addons), ESPHome concatenates the extended action list after
    the base package's actions. The base ducking sequence blocks on
    `wait_until: not announcing`, so the addon's unmute only ran once the
    announcement had already finished.
    The base ducking/vol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
2026-11-13 Run the PlatformIO samples build only when the samples change (#221)
    The Build Examples workflow triggered on any firmware/** change, so
    ESPHome-only commits and PRs ran (and failed) the unrelated PlatformIO
    sample builds. Limit it to the three sample directories it builds.
2026-11-13 Quieter monitoring: disable debug sensors by default, runtime log level, no API reboot (#220)
    * Quieter monitoring: debug sensors off by default, runtime log level
    - Diagnostic sensors stay compiled in but are disabled_by_default, so
    HA records nothing for them until a user enables one to debug.
    - Uptime is a timestamp sensor; the Status binary sensor is removed.
    - Configs compile with logger level DEBUG and start at initial_level
    INFO; a Log Level select raises it at runtime without a rebuild.
    - api reboot_timeout 0s: Music Assistant-only players no longer reboot
    every 15 minutes for lack of a Home Assistant client.
    * Add a pe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
